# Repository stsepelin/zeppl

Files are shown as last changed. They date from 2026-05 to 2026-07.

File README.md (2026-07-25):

# Zeppl





> **Zeppl** — DIY digital instrument cluster for a 2009 Harley-Davidson VRSCF
> Muscle: an 800×800 round IPS gauge that drops into the stock dash, reads the
> bike's J1850 bus, and bridges phone notifications + media over BLE.

Built on the Waveshare ESP32-P4-WIFI6-Touch-LCD-3.4C (ESP32-P4 dual-core
RISC-V @ 360 MHz + ESP32-C6 BLE/WiFi coprocessor, 32 MB PSRAM, 16 MB flash).
LVGL 9 over MIPI-DSI on ESP-IDF v6, paired with the Zeppl Android companion
app for phone integration.

## What's in the repo

| Path | What it is |
|---|---|
| [`firmware/`](firmware/) | ESP-IDF cluster firmware — gauge UI, sim engine, BLE peripheral, host tests, desktop simulator |
| [`companion/`](companion/) | **Zeppl** Android BLE-central app — notifications + media bridge, live telemetry, and speed/fuel calibration for the cluster |
| [`docs/`](docs/) | Cross-system docs — project brief, roadmap, hardware/bus reference, phase plans, UI screens |
| [`firmware/docs/`](firmware/docs/) | Firmware-internal docs — architecture, reference notes, ride logs, plans |

Start with [`docs/PROJECT-BRIEF.md`](docs/PROJECT-BRIEF.md) for the whole-system view,
or jump straight to a component:

- [`firmware/CLAUDE.md`](firmware/CLAUDE.md) — firmware working notes
- [`companion/README.md`](companion/README.md) — Android app working notes

## Quick start

```sh
make help              # list every target
make build-fw          # build the firmware
make flash-monitor     # flash + open serial monitor
make test-fw           # run host unit tests (no MCU required)
make sim               # desktop SDL2 + LVGL simulator
make build-app         # build the Android app
make test-app          # run companion unit tests
```

The Makefile delegates to `idf.py` / `gradlew` in the right subdirectory
and sources the ESP-IDF environment for you. Override
`IDF_EXPORT=/path/to/export.sh` or `PORT=/dev/cu.usbmodemXXXX` on the
command line if defaults don't match your setup.

## Status

**Phase 1 (firmware & gauge UI)** is complete — display, widgets, touch,
settings, the Android BLE companion, the simulator, and a 100% host-test
gate; a synthetic driving cycle drives the full widget set at 30 FPS on the
round display. **Phase 2 (J1850 bus + IM simulation)** is well along: the RX
sniffer, decode → vehicle_data producer, on-board ride log, and the full
companion telemetry / calibration / fuel stack are in and bench-validated,
with the **speed divisor locked at 188** (Ride 2, 2026-07-09 — gear-ratio
physics + radar, not GPS). **Stage 4 TX + IM replay is on-bike validated
(2026-07-24)** and the **DTC read** firmware is built. Remaining: the DTC
follow-ups and the stock-cluster-removal checks. See
[`docs/phases/phase2-j1850.md`](docs/phases/phase2-j1850.md).

See [`docs/ROADMAP.md`](docs/ROADMAP.md) for the full four-phase roadmap with
per-stage statuses.

## Hardware

- **Board**: Waveshare ESP32-P4-WIFI6-Touch-LCD-3.4C — [vendor page](https://www.waveshare.com/esp32-p4-wifi6-touch-lcd-3.4c.htm)
- **Bike**: 2009 Harley-Davidson VRSCF Muscle (VRSC family, J1850 VPW bus,
  12-pin instrument harness)
- **Companion**: Android 16+ device (minSdk 36); the companion app is
  side-loadable in dev builds

The firmware *should* compile on any ESP32-P4 board with a 16 MB flash
and PSRAM, but the BSP layer (display, touch, codec) is Waveshare-specific.

## Development

```sh
# First-time IDF setup (one-off)
git clone https://github.com/espressif/esp-idf.git -b v6.0.1 ~/esp/esp-idf
cd ~/esp/esp-idf && ./install.sh esp32p4

# In this repo, with IDF active:
. ~/esp/esp-idf/export.sh   # or have Makefile source it via IDF_EXPORT
make build-fw

# Host tests (no IDF needed beyond cmake + lcov)
brew install lcov            # macOS
make test-fw

# Android side: standard Gradle + Android Studio
make build-app
```

See each component's working notes for deeper conventions (cache
discipline on widget setters, theme palette, font choices, BLE GATT
layout, etc.).

## Contributing

This is primarily a personal project for one specific bike, but the
firmware patterns (LVGL setter caches, V-Rod palette, BLE-over-VHCI
on a P4+C6 module, the binutils 2.45 link-trap workaround) are
generic enough to be useful elsewhere. Issues + PRs welcome —
especially ports to other Harley models or display boards.

If you're filing a bug, please include:
- ESP-IDF version + toolchain bundle
- ESP32-P4 silicon revision (`esptool chip_id`)
- Board model
- The full boot log if it's a runtime issue, or `idf_size.py --archives`
  output for a build-size issue

## License

[Apache 2.0](LICENSE). Vendor BSP components under `firmware/components/`
and `firmware/managed_components/` retain their own licenses (Apache 2.0,
MIT, etc.); see the LICENSE file inside each.

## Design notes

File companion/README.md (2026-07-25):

# Zeppl (companion)

**Zeppl** (package `ee.zeppl.companion`) is the Android phone-side bridge for
the [Zeppl](../) cluster firmware.

Mirrors notifications and media state from the phone to the bike's
gauge over a BLE GATT link, and accepts commands back (accept / reject
calls, media transport). The firmware advertises as `Zeppl`
and this app is the central that pairs with it.

Whole-system context: [`../docs/PROJECT-BRIEF.md`](../docs/PROJECT-BRIEF.md) ·
[`../docs/ROADMAP.md`](../docs/ROADMAP.md). The companion work is Phase 1 (relay)
+ Phase 2 Stage 5 (telemetry / calibration) in that roadmap.

**Deep-dive docs** (in [`docs/`](docs/)): [`ARCHITECTURE`](docs/ARCHITECTURE.md)
(packages, link model, data flow) · [`PROTOCOL`](docs/PROTOCOL.md) (the BLE wire
format) · [`CALIBRATION`](docs/CALIBRATION.md) (speed-divisor + fuel math).

## Status

**Phase 1 relay + Phase 2 Stage 5 companion, done.** The Material 3
Expressive redesign (adaptive nav, per-cluster detail screens, Galaxy
Fold 6 foldable support) is in.

Relay (Phase 1): BLE central with scan + device picker, LE Secure Connections
bonding (numeric comparison), a foreground service
(`FOREGROUND_SERVICE_CONNECTED_DEVICE`) hosting the GATT link,
`NotificationListenerService` relay with a per-app allow-list,
`MediaSessionManager` watcher for now-playing metadata, and a
`CommandHandler` that dispatches cluster-issued commands (call
accept/reject/end, media prev/play/pause/next, notification dismiss)
into `TelecomManager` / `MediaController`.

Cluster integration (Phase 2 Stage 5): a 4 Hz **telemetry** stream
(`TelemetryCodec`), a **GPS speed-calibration** wizard (`SpeedCalibrator`
least-squares-fits GPS speed vs the cluster's raw ECM count → speed
divisor, written back over BLE), **config write-back** to cluster NVS,
and **fuel economy / range** (`FuelEconomy`: fill-up mL/tick calibration →
mpg / L/100km / range-to-empty). The wire-format encoder and the pure
calibration modules are unit-tested against the firmware's C fixtures.

Auto-reconnect: on link loss (`ReconnectPolicy` — supervision timeout,
i.e. cluster power cycle or out-of-range) the client re-arms a
background `connectGatt(autoConnect=true)` to the bonded address, so
the link heals on every ignition cycle without touching the phone.
Deliberate disconnects (either side's disconnect button) stay
disconnected.

## Why a custom companion app

The cluster's ESP32-C6 radio is BLE-only — no Bluetooth Classic, so
HFP / AVRCP / MAP are off the table. iOS exposes notifications and
media over ANCS + AMS natively; Android doesn't have an equivalent
profile, so we forward over our own GATT characteristic. Keeping the
wire format custom (rather than re-using a spec like ANCS) lets the
firmware speak the same protocol on both platforms.

## Requirements

- Android 16 (API 36) device or emulator
- Android Studio (AGP 9.2 + Kotlin 2.3)
- JDK 17 (the Robolectric test task self-selects JDK 21 via the toolchain)

## UI architecture

Material 3 **Expressive** (`MaterialExpressiveTheme` + the spring-based
`MotionScheme`), branded Zeppl dark theme by default (orange-on-near-black,
mirroring the cluster's own palette in `firmware/main/display/theme.h`;
Material You dynamic color is an opt-in toggle under Settings). The theme
lives in `ui/theme/` (`Color.kt` / `Type.kt` / `Theme.kt`).

Navigation is an adaptive `NavigationSuiteScaffold` (bottom bar on phones,
rail on larger screens) over a type-safe `@Serializable`-route NavHost
(`ui/Destinations.kt`, `ui/App.kt`), with a persistent connection-status
strip (`ui/ConnectionStatusBar.kt`) visible on every tab. Four top-level
destinations:

- **Ride** — live telemetry dashboard (`ui/RideScreen.kt`), reading
  `ble/TelemetryState`; offline empty-state until frames arrive.
- **Cluster** — device hub: link, bond management, setup/maintenance
  (`ui/ClusterScreen.kt`).
- **Settings** — notification/media relay + appearance + cluster config
  write-back (`ui/SettingsScreen.kt`).
- **History** — trips + economy trends (`ui/HistoryScreen.kt`, placeholder).

Version note: material3 is pinned to `1.5.0-alpha18` (newest Expressive
alpha still on the Compose 1.11 line — 1.5.0-alpha20+ / Compose 1.12 need
compileSdk 37; see `gradle/libs.versions.toml`).

## Build + run

```sh
# From the repo root via the top-level Makefile:
make build-app         # ./gradlew :app:assembleDebug
make test-app          # ./gradlew :app:test
make install-app       # ./gradlew :app:installDebug (to a connected device)

# Or directly:
cd companion
gradle wrapper         # one-time, generates gradlew jar
./gradlew :app:assembleDebug
```

## Wire format

`app/src/main/java/ee/zeppl/companion/ble/Protocol.kt` mirrors
[`firmware/main/connectivity/phone/phone_protocol.c`](../firmware/main/connectivity/phone/phone_protocol.c)
byte-for-byte. The firmware's host tests
(`firmware/test_apps/host/tests/test_phone_protocol.c`) are the
canonical fixtures; `ProtocolTest.kt` asserts the same shapes from the
encoder side. Touch one, touch both.

## Layout

```
companion/
├── app/                          Main module
│   ├── src/main/
│   │   ├── AndroidManifest.xml
│   │   ├── java/ee/zeppl/companion/
│   │   │   ├── MainActivity.kt
│   │   │   ├── ble/              GATT client, protocol encoder, state, telemetry
│   │   │   ├── media/            MediaSession watcher → wire format
│   │   │   ├── notif/            NotificationListener bridge
│   │   │   └── ui/               Compose app: theme/, nav shell, four tab screens
│   │   └── res/
│   └── src/test/                 JVM unit tests (Protocol, BleState, …)
├── build.gradle.kts
└── settings.gradle.kts
```

## Roadmap

- [x] BLE central: scan for `Zeppl`, bond, open the GATT
      service, hold the write characteristic, subscribe to the command
      notify characteristic.
- [x] Foreground service hosting the BLE link
      (`FOREGROUND_SERVICE_CONNECTED_DEVICE`).
- [x] `NotificationListenerService` → `Protocol.encodeNotif`.
- [x] `MediaSessionManager` listener → `Protocol.encodeMedia`.
- [x] Inbound command path → Telecom
      (`TelecomManager.acceptRingingCall`, `endCall`) and
      media key dispatch for prev/play/next.
- [x] Status / pairing UI (`ScanScreen`, device picker).
- [x] Auto-reconnect when the bonded cluster reappears after a power
      cycle (background `connectGatt(autoConnect=true)` armed on link
      loss — works under directed advertising, unlike a rescan).
- [x] Material 3 Expressive redesign: branded theme, adaptive
      navigation hub (Ride / Cluster / Settings / History), persistent
      connection status.
- [x] Live telemetry stream on the Ride dashboard (Brick 1).
- [x] GPS speed-calibration wizard (Brick 2). (Firmware divisor is locked at
      188 from Ride 2 physics + radar; the wizard is a GPS cross-check.)
- [x] Cluster config write-back with ack/read-back (Brick 3).
- [x] Fuel economy / range (Brick 4). Persistent trip history is a follow-up.
- [ ] **Diagnostics view** — surface the DTCs the cluster reads (firmware read
      path is built) + a clear-codes action. See the roadmap's Phase 2 Stage 5.

## License

Apache 2.0 — see [`../LICENSE`](../LICENSE) at the repo root.

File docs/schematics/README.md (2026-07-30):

# Schematics

Source of truth for the analog/wiring drawings. Each `.py` is a
[schemdraw](https://schemdraw.readthedocs.io/) script that renders the
`.svg` next to it; the SVGs are committed so the docs render on GitHub
without any toolchain. (Exceptions: the matplotlib drawings —
`j1850_signal_board.py`, `bike_power_perfboard.py`,
`im_connector_face.py` — are matplotlib, not schemdraw; see Regenerate.)

> **TX polarity RESOLVED (2026-07-04): standard VPW → high-side TX.**
> The bus idles LOW / dominant HIGH (bare-bus DMM + invert-off raw dump +
> clean filter-off decode all agree — see `SESSION-2026-07-04.md`), so
> `j1850_tx.svg` (high-side PNP) is the canonical TX. The low-side
> `j1850_transceiver` drawing was the inverted-bus hypothesis; it was
> wrong and has been deleted (its "wrong turn" is recorded in prose in
> the roadmap + session notes, not kept as a buildable drawing). TX
> build itself is still Stage 4, gated on the 2N2907A + bench self-sniff.

| Drawing | Built in | What it is |
|---|---|---|
| `j1850_rx.py/.svg` | Phase 2 Stage 1–2 | J1850 RX front end alone: 7.5V zener clamp + 10k/4.7k divider → sniffer GPIO. Correct and unchanged. Build this first — it can't disturb the bus. (The temporary GPIO 22 ADC amplitude probe is a second wire off node B — firmware `CONFIG_VROD_J1850_ADC_GPIO`; not drawn.) **Phase 3:** the permanent harness needs a **comparator / Schmitt** stage here for noise immunity — not the P4 glitch filter (it desyncs decode; see the roadmap Phase 3 note + `../../firmware/docs/reference/j1850-toggling-isr-candidate.md`). This bare-divider drawing is the bench build. |
| `j1850_tx.py/.svg` | Phase 2 Stage 4 — **canonical TX (high-side)** | High-side PNP source: dominant = drive bus HIGH. Correct for standard VPW (idle LOW / dominant HIGH), now confirmed on the bike. 2N2907A needed. |
| `j1850_signal_board.py/.svg` | Phase 2 + 6 — full bike signal board | Physical pad-per-hole layout of the whole signal board: the J1850 transceiver **plus the 6 discrete 12V dividers** (`discrete_divider`, ×6: turn L/R, beam, neutral, oil, ignition). Bike build (no Rpd). **v4 (18×24 perfboard): single GND rail down the right edge, one P4 comb (RX·GP20 / TX / GND + the 6 divider outputs), a PWR/BUS 3-pin input terminal, 2×3p signal-input terminals, and a +12V/GND transit terminal onward to the power board; each 3V3 clamp joins its comb pin through a jumper so the pin hole stays free.** **12V topology (split point S2): the row-1 rail IS the split — the harness feeds (1,3), Q2's emitter taps off the rail, and (18,2) transits onward to the power board, so this rail carries the FULL power-board current (~0.5 A cont / ~1.0 A peak). F1 is inline in the harness; this board is fused but NOT reverse-protected (D2 is downstream, on the power board).** ⚠ **That describes the INTENDED state: F1 is currently NOT installed and v4 is drawing from pin 6 unfused — see the deviation note in [`../../firmware/docs/reference/bike-power-injection.md`](../../firmware/docs/reference/bike-power-injection.md). Blocking before the power board is connected.** As-built status: `j1850_signal_board.md`. The power chain lives on a **separate** board (switcher noise / current). Build doc + netlist + ring-out: `j1850_signal_board.md`. Electrical source of truth stays `j1850_rx`/`j1850_tx`/`discrete_divider`. **matplotlib, not schemdraw.** |
| `discrete_divider.py/.svg` | Phase 3 | 12V discrete-signal divider (10k/2.7k + optional 3.3V zener), ×6 for turns/beam/neutral/oil/ignition. Sized for 14.4V charging voltage. |
| `bike-power-chain.py/.svg` | Phase 3 (power) | Protected 12V→5V bike-power chain: fuse + reverse-polarity + load-dump TVS (TVS1 P6KE16A) → mini560 → output reverse-block (D4 XL74610 ideal-diode @ 5.0V) → board header 5V, with USB-C data coexisting via the board's own AO3401. Full parts list + bench test in `../../firmware/docs/reference/bike-power-injection.md`; BOM in `bike-power-chain.bom.md`. |
| `bike_power_perfboard.py/.svg` | Phase 3 (power) — perfboard build | Physical pad-per-hole layout of the `bike-power-chain` circuit. **Starts at D2** — F1 is a harness part, not on this board: D2 SB560 → TVS1 P6KE16A → mini560 12V→5V → D4 XL74610 ideal-diode → P4 header 5V. **Its 12V input is fed BY the signal board's transit terminal (split point S2); this board sources nothing back to it.** Separate board from the signal board. Electrical source of truth stays `bike-power-chain.py`. **matplotlib, not schemdraw.** |
| `im_connector_face.py/.svg` | Phase 3 (harness) | Physical face map of the V-Rod Instrument Module 12-pin connector (**Deutsch DTM06-12S** socket, from the molded housing marking) for building quick-connect mating connectors. 2-row / 6-wide; **bottom row numbering is inverted** — 12,11,10,9,8,7 left→right (pin 12 under pin 1, pin 7 under pin 6), **verified on the bike (2026-07)**, not assumed. Wire-entry side (the mating face mirrors L↔R). Each cavity shows wire colour + signal; the ring colour encodes the destination (signal-board divider / J1850 BUS / power board / GND / Phase 3 / unused). Pin→colour→signal from the connector table in `../reference/J1850-BUS.md` / `../PROJECT-BRIEF.md`. **matplotlib, not schemdraw.** |
| `gps_module.py/.svg` | Map (optional) | NEO-6M / GY-NEO6MV2 map-position module: 5V/GND + module TX → GPIO 21 (3.3V TTL, no level shift), RX-only. Wiring + bring-up in `../../firmware/docs/reference/gps-module.md`. |

## Regenerate

```sh
python3 -m venv .venv && .venv/bin/pip install schemdraw matplotlib
for f in *.py; do .venv/bin/python "$f"; done
```

Edit the `.py`, re-run, commit both files. Don't hand-edit the SVGs.

The matplotlib drawings — `j1850_signal_board.py`,
`bike_power_perfboard.py`, `im_connector_face.py` — are **matplotlib, not
schemdraw** (hence the `matplotlib` install above). Each writes both a `.svg`
and a `.png`; only the `.py` + `.svg` are committed, the `.png` is gitignored
(`docs/schematics/*.png`).

## Conventions

- Component designators are stable across drawings, in **two families** that
  never share a name. The v4 signal board carries parts from both, so read the
  family, not just the letter:
  - **J1850 front end** — `R1` 10k / `R2` 4.7k divider, `D1` 7.5 V BUS clamp,
    plus `R3` 1k, `R4`/`R6` 10k, `R5` 100 Ω, `Rg` 10k, `Q1` IRLZ44N, `Q2`
    2N2907A. Match the prose in `../reference/J1850-BUS.md`.
  - **12V discrete divider** (×6) — `Ra` 10k / `Rb` 2.7k, `Dz` 3.3 V clamp.

  The distinction is load-bearing: a 3.3 V `Dz` fitted in the `D1` position would
  clamp the **bike's J1850 bus** at 3.3 V. `j1850_signal_board.md`'s placement
  table lists both families with their holes.
- Values that came out of analysis carry their reasoning as a caption
  inside the drawing (e.g. the 14.4V charging-voltage math), so a
  printout taken to the bench is self-contained.

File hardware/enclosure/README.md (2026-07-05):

# Enclosure — Waveshare ESP32-P4-WIFI6-Touch-LCD-3.4C

Parametric round enclosure in `enclosure.scad`. **Rear-bolt board fixation** for a
motorcycle (vibration): the PCB is mounted the way it's designed to be — bolted at
its 4 mount holes (74.5 mm square) to internal standoffs, from the **rear**.

**Key dimensions:** Ø115 mm face (cover-glass OD, `glass_od`) · 74.5 mm board mount
square (`mount_square`) · ~50 mm electronics cavity depth (`internal_depth`). Build
tiers (`simple` / `compromise` / `robust`) tune wall / floor / standoff / gasket —
see the tier table below. (STL outputs are regenerated from `enclosure.scad`, not
committed — see the render commands under "Modes".)

> **This is a TEMP / bench-test build.** Wiring exits through ONE cable hole at the
> bottom of the wall (`cable_hole_dia` at `cable_exit_angle` = 270°); the per-connector
> cutouts (USB-C / microSD / 40-pin / buttons) are dropped and kept as commented
> params for the final enclosure. microSD access on this build = remove the rear cover.
> **Every screw boss is gusseted** (bezel ears, case perimeter bosses, board
> standoffs) via a shared `boss_gusset` module — no freestanding stalks anywhere.

```
[ bezel ring ]   frames + protects the glass edge (light duty)
[ glass + PCB ]  one bonded block, 7.6 mm (glass 6 + pcb 1.6), touching; in from front
[ standoffs ]    4 chunky wall-gusseted posts behind the PCB at the 74.5 square,
                 M3 heat-set inserts — the board's PRIMARY load path
[ deep cavity ]  ~50 mm for breadboard + mini560 + wiring
[ rear cover ]   REMOVABLE — reach the 4 board bolts + wiring, then close
```

## Why the rear cover is removable (not a closed cylinder)

The 4 board bolts are driven from the **rear**, so the back must be **open during
assembly** to reach them. A one-piece closed cylinder would make the board bolts
(and wiring, and the microSD) unreachable. So the rear cover is a separate,
removable panel — screwed on last.

## Why this works now (it didn't before)

The 4 M3 holes sit under the glass *from the front*, but the removable rear cover
means they're **reachable from behind**. The board seats rear-face on 4 chunky
standoffs at the 74.5 square; 4 rear M3 bolts thread up into heat-set inserts in
the standoffs, engaging the board's own mount holes. The block is trapped forward
by the front lip + bezel and rearward by the standoffs, so the board is held
captive at its 4 holes — its intended mount, stronger and more direct than the
edge-compression it replaces.

> Note on the load path: because the glass fully backs the PCB *front*, a bolt
> head can't sit on the glass side, so the rear bolts **locate + secure** the board
> at its holes while the front lip/bezel trap the block forward (the board can't
> lift off the posts). This is a direct 4-point board mount, not an edge clamp.

## Standoffs (the board's load path)

Chunky and **wall-gusseted** — no thin tall stalks. Diameter is per-tier (`simple`
9, `compromise` 10, `robust` 11 mm). Each post is tied to the wall by a **tapered
fan gusset** (`gusset_span` ±15°, `gusset_h` 10 mm): a solid web fanning from the
post base out to a ~30° arc of the wall and tapering up to the post, so the post
can't crack off at the base under vibration. M3 heat-set insert (`insert_hole_dia
= 4.0`, `insert_depth = 6.0`) opens toward the PCB; the rear bolt reaches it up a
clearance bore. A **`gasket_under_pcb`** pad (0.8 mm default) sits between the PCB
rear and the standoff tops — the whole board is damped, not just the glass rim.
Print `rear_case` open-end up so the standoff/gusset layers resist the bolt load
across, not along, the layer lines.

Verified in the render echo: standoff centers at (±37.25, ±37.25) → **74.5 mm
center-to-center in X and Y**, and the bolt path PCB-hole (z 6–7.6) → under-PCB
gasket (7.6–8.4) → insert (8.4–14.4) → rear clearance to the open back.

## Modes / render

```sh
openscad -o rear_case.stl        -D 'part="rear_case"'        enclosure.scad
openscad -o bezel.stl            -D 'part="bezel"'            enclosure.scad
openscad -o rear_cover.stl       -D 'part="rear_cover"'       enclosure.scad
openscad -o calibration_base.stl -D 'part="calibration_base"' enclosure.scad
# tier / fastener overrides:
openscad -o rear_case.stl -D 'part="rear_case"' -D 'tier="robust"' enclosure.scad
```
All four parts render manifold (`Simple: yes`) at every tier / fastener setting.

## Build tiers (`-D 'tier="..."'`)

| tier | fastener | wall | floor | perimeter screws | standoff Ø | gasket_gap |
|---|---|---|---|---|---|---|
| `simple` | captured nuts | 3.0 | 4.0 | 4 | 9 | 1.0 |
| `compromise` (default) | heat-set | 3.0 | 3.5 | 6 | 10 | 0.6 |
| `robust` | heat-set | 4.0 | 4.0 | 6 | 11 | 1.0 |

Every screw boss (bezel ears, case perimeter bosses, board standoffs) is reinforced
by the shared `boss_gusset` module — a fan web to its wall/ring/floor, sized by
`gusset_span` / `gusset_h`. `screw_offset` (0°) keeps a clean gap at the bottom
(270°) for the cable hole with 6 screws.

`fastener` (for the perimeter bezel/cover screws) is independently overridable:
`-D 'fastener="heatset"'` / `"captured_nut"`. The **board** standoffs always use
M3 heat-set inserts (metal — the board is the load path).

## Print order

1. **`calibration_base`** — shallow front section with the block-seat ledge, the
   bezel screw ears, **and the 4 board standoffs**. Verify the block seats, the
   bezel screws line up, and — most important — the **board bolts onto the 74.5
   standoffs from the rear**. Cheap.
2. **`rear_case` + `bezel` + `rear_cover`** once the fit checks out.

## Assembly order

1. **Heat-set the inserts** into the 4 board standoffs (and the perimeter bezel /
   rear-cover bosses). Metal only — printed threads strip under vibration.
2. **Glass+PCB block in from the FRONT** — glass to the front lip; the PCB rear
   lands on the 4 standoff tops. Put the `gasket_under_pcb` foam/silicone pad (with
   4 clearance holes for the bolts) between the PCB rear and the standoff tops, and
   a gasket under the glass rim — the whole board is damped, not just the glass.
3. **4 rear board bolts** — reaching through the **open back**, drive short M3 bolts
   into the standoff inserts, engaging the board's 4 mount holes. **Thread-locker**
   (medium, e.g. Loctite 243) on every one.
4. **Bezel on the front** — light-duty frame/edge protection over the glass rim,
   its perimeter screws into the rear-case ears.
5. **Wiring** in the cavity (breadboard + mini560) exits the **single bottom cable
   hole**; then **rear cover** on last (screws into the rear bosses; thread-locker too).

## Material (print settings)

- **PETG** to start (tough). **ASA** best for a bike — UV / heat / sun resistant.
  **Not PLA** — heat-warps in a sun-parked cockpit.
- **Layer orientation:** print `rear_case` open-end up so the standoffs + gussets
  aren't a cleavage plane under the bolt load; 4+ perimeter walls. Print `bezel` and
  `rear_cover` flat. Thread-locker on all metal fasteners.

## Params to tune after test-fit

- **`standoff_len` / `standoff_od`** — post depth and chunk.
- **`gusset_span` / `gusset_h`** — fan-gusset arc and taper height (post-to-wall tie).
- **`gasket_under_pcb`** — foam/silicone pad between the PCB rear and standoff tops.
- **`gasket_gap`** — damping pad under the glass rim.
- **`mount_square` (74.5)** — the board bolt circle; re-measure if the bolts miss.
- **`fastener`** — perimeter screw style (`heatset` / `captured_nut`).
- **`glass_fit` / `block_fit`** — bore clearance if the block is tight/loose.

## Cable exit — single bottom hole (TEMP build)

All wiring exits one grommet hole at the **bottom of the wall** (`cable_hole_dia`
12 mm at `cable_exit_angle` 270°, `cable_exit_z` 35). Verified clear of the
standoffs (45/135/225/315°, z 8.4–22.4) and the screw gussets (270° sits in the
255–285° gap between the 240°/300° screws) — echoed at render time. **microSD is
accessed by removing the rear cover** on this temp build; a dedicated SD slot (and
the per-connector cutouts, kept commented in-file) comes on the final enclosure.
Move the hole with `cable_exit_angle` / `cable_exit_z`, or widen `cable_hole_dia`,
if your bundle needs it.

## Out of scope — handlebar mount

Metal load path, separate task: aluminium straps to the triple-tree riser bolts
(M10×1.5, ~89 mm). A commented `mount_strap_*` location is left in `enclosure.scad`.

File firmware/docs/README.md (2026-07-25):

# Firmware docs

Working notes for the ESP-IDF cluster firmware. Cross-system docs (project
brief, roadmap, hardware/bus reference) live at the repo root in
[`../../docs/`](../../docs/).

## Core (read these first)

- [`ARCHITECTURE.md`](ARCHITECTURE.md) — threading, render pipeline, boot
  sequence, decision history.
- [`DISPLAY-PERF-AND-MEMORY.md`](DISPLAY-PERF-AND-MEMORY.md) — **read before
  touching anything that draws.** Render/RAM constraints, bake-don't-transform
  rules, the debug playbook.
- [`PINS.md`](PINS.md) — header pin map / GPIO assignments.
- [`ble-bringup-bisect.md`](ble-bringup-bisect.md) — the binutils 2.45 / IDF
  P4-rev link-trap resolution.

## reference/ — design + bring-up notes

- [`reference/bike-power-injection.md`](reference/bike-power-injection.md) — protected 12V→5V power chain.
- [`reference/gps-module.md`](reference/gps-module.md) — optional NEO-6M map-position module.
- [`reference/dtc-read-probe.md`](reference/dtc-read-probe.md) — HD J1850 DTC read protocol + probe.
- [`reference/j1850-toggling-isr-candidate.md`](reference/j1850-toggling-isr-candidate.md) — future RX ISR design note.
- [`reference/j1850-undecoded-frames.md`](reference/j1850-undecoded-frames.md) — catalogue of still-undecoded bus frames.
- [`reference/live-gauge-bench-test.md`](reference/live-gauge-bench-test.md) — stationary bus→gauge validation.
- [`reference/signal-mapping-capture.md`](reference/signal-mapping-capture.md) — one-input-at-a-time signal capture plan.

## rides/ — on-bike sessions + bring-up logs

- [`rides/next-onbike-plan.md`](rides/next-onbike-plan.md) — **step-by-step plan for the next bike visit** (all open tests, in order).
- [`rides/ride-1-findings.md`](rides/ride-1-findings.md) — J1850 decode calibration.
- [`rides/ride-2-findings.md`](rides/ride-2-findings.md) — speed-divisor lock (188) + live-stack review.
- [`rides/ride-2-calibration-plan.md`](rides/ride-2-calibration-plan.md) — the Ride-2 plan (completed).
- [`rides/ride-3-plan.md`](rides/ride-3-plan.md) — map on-bike verification (pending).
- [`rides/onbike-session-plan.md`](rides/onbike-session-plan.md) · [`rides/stage4-onbike-step3.md`](rides/stage4-onbike-step3.md) — Stage-4 on-bike session plans.
- [`rides/stage4-tx-bench-log.md`](rides/stage4-tx-bench-log.md) — the Stage-4 TX bring-up + on-bike validation log.
- `captures/` — raw serial capture logs the ride docs reference.

## plans/

- [`plans/phase1-display-plan.md`](plans/phase1-display-plan.md) — the (complete) gauge-UI phase.
- [`plans/map-worldwide-plan.md`](plans/map-worldwide-plan.md) — GPS-paged per-cell map tiles.

## Other

- `waveshare-reference/` — vendor examples kept for reference (not ours).

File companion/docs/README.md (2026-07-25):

# Companion docs

Deep-dive docs for the Zeppl Android companion app. Start with the app overview
+ status + roadmap in [`../README.md`](../README.md); these are the reference
details behind it.

- [`ARCHITECTURE.md`](ARCHITECTURE.md) — package/class map (ble / cal / media /
  notif / ride / ui), the foreground-service link model, data flow, threading,
  and testing.
- [`PROTOCOL.md`](PROTOCOL.md) — the BLE GATT wire format: Nordic-UART
  characteristics, the TLV framing, every phone→cluster event type, the `0x40`
  telemetry frame, commands, and the icon codec. Mirrors the firmware's
  `phone_protocol.c` / `telemetry_codec.c` byte-for-byte.
- [`CALIBRATION.md`](CALIBRATION.md) — the pure `cal/` math: the least-squares
  speed-divisor solve and the fuel-economy / range calculations.

Whole-system context: [`../../docs/PROJECT-BRIEF.md`](../../docs/PROJECT-BRIEF.md)
· [`../../docs/ROADMAP.md`](../../docs/ROADMAP.md). The companion is **Phase 1**
(notification/media relay) + **Phase 2 Stage 5** (telemetry / calibration) in
that roadmap.

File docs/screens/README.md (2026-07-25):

# Screen layouts

Real renders of the cluster UI, captured headlessly from the desktop simulator
(`firmware/simulator/`) — the same widget code that runs on the P4, not mockups.
The physical panel is the inscribed circle of the 800×800 square (the case hides
the black corners). Images are downscaled to 480 px and palette-quantized for the
repo (see "Regenerating" below).

## Ride / gauge screen

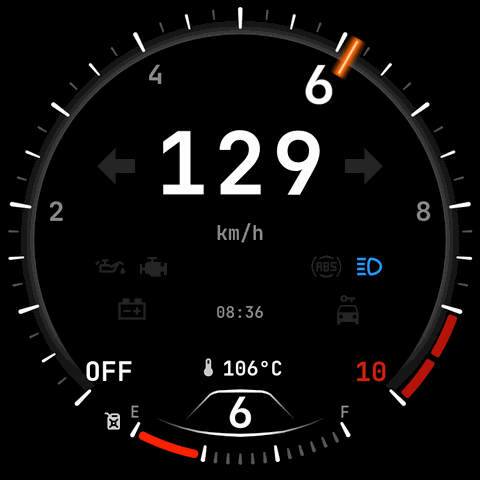
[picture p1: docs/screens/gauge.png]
Ride gauge screen — 129 km/h, gear 6, high beam


The primary screen (BMW-EfficientDynamics styling). Layout:

- **Tach** — 270° arc around the rim: capsule ticks, zoom + colour-coupled
  labels 2/4/6/8/10, a two-segment rounded **redline** (red, lower right), and a
  baked Gaussian **cursor** sprite tracking RPM. `OFF` (lower left) is the
  shift-light state.
- **Speed** — large centre digits (three slots, `km/h` / `mph` per settings),
  flanked by the **turn-signal** arrows.
- **Warning lamps** — two chevrons: oil, check-engine, ABS, battery,
  immobiliser (car-key), high/low beam (slot rotates).
- **Clock + odometer + dual trips** cycle in a shared slot; **temperature**
  readout; **gear** indicator in the bottom selector (orange `N`).
- **Fuel** — arc across the bottom (E→F), red when low, jerrycan icon.

Idle / key-on state (engine off, immobiliser + battery lit, `N`):

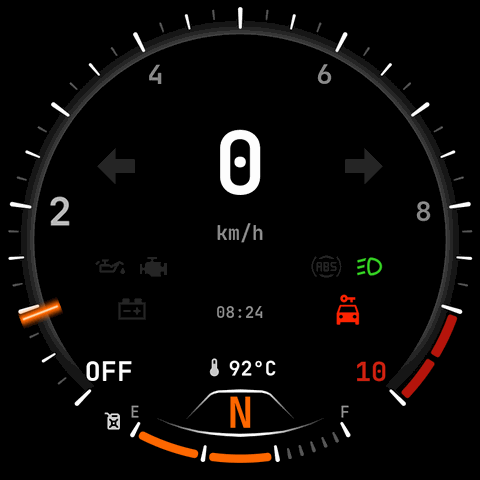
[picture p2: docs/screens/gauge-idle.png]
Ride gauge screen — idle, N, immobiliser lit


## Map screen

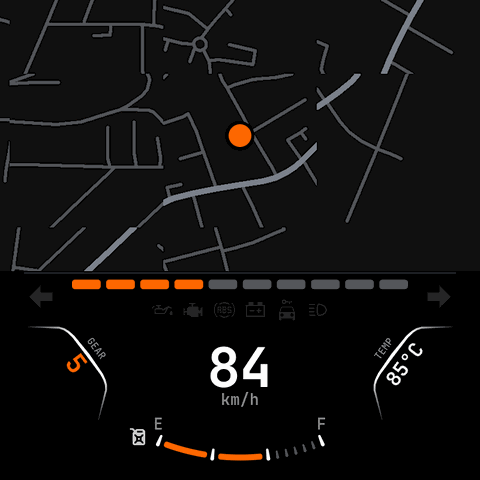
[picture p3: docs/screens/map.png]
Moving map + compact cluster


Reached by double-tapping off the gauge: SD-streamed vector tiles, heading-up
rotation, position dot (dual-source — onboard NEO-6M preferred, phone GPS
fallback), and a **compact cluster** strip below — RPM bar, warning lamps, a
slanted gear panel, centre speed, temperature, and the fuel arc.

## Settings

| | |
|---|---|
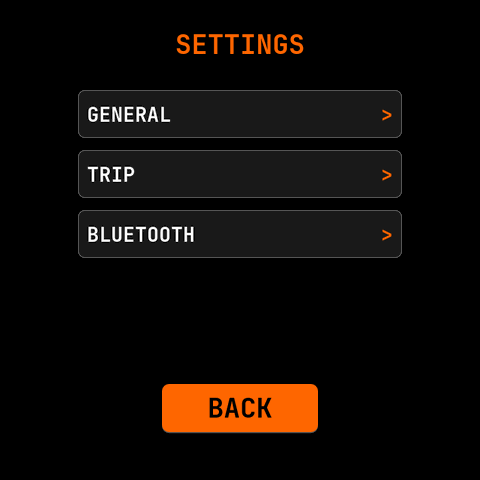
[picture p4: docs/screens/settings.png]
Settings menu
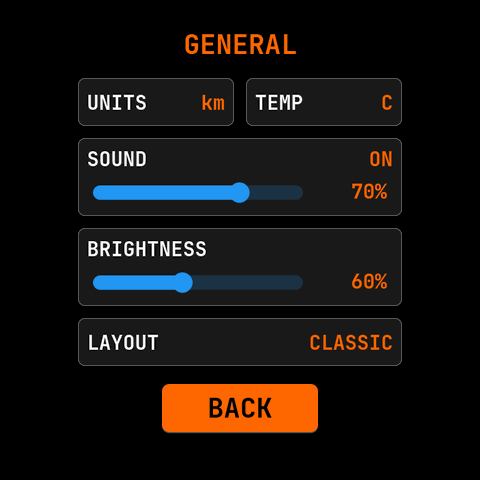
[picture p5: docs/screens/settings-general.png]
General settings
|  |  |
| **Menu** — General / Trip / Bluetooth. | **General** — units, temp unit, sound + brightness sliders, layout (classic / map). |
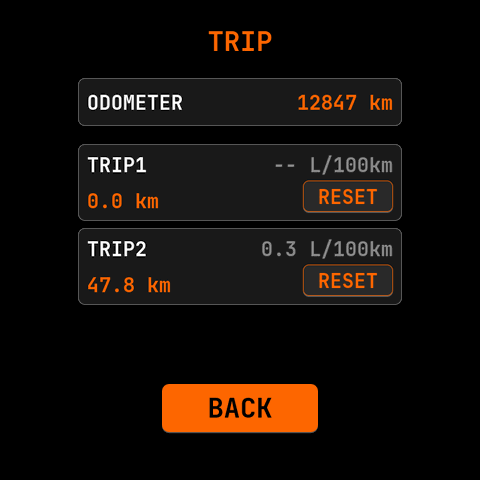
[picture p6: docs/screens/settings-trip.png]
Trip settings
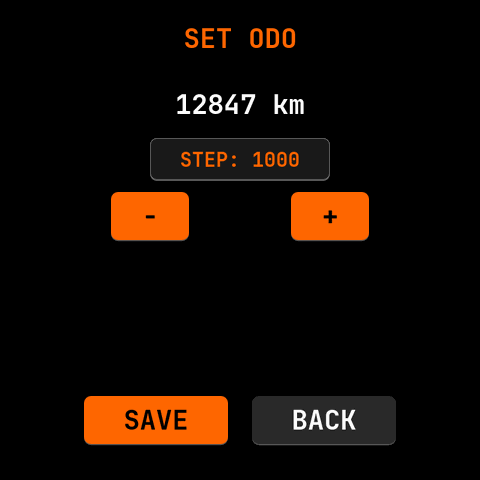
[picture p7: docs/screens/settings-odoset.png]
Set odometer
|  |  |
| **Trip** — odometer + dual trips, reset. | **Set ODO** — seed the odometer (step + / −, save). |
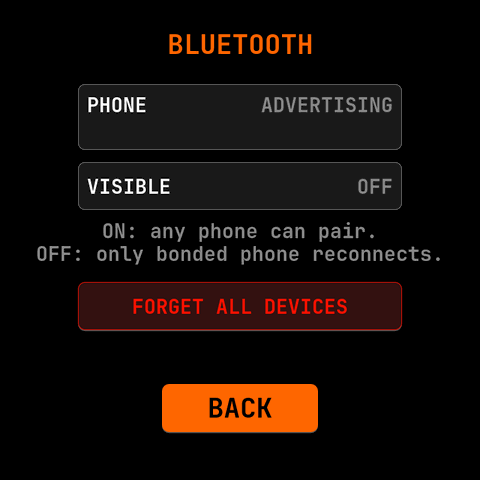
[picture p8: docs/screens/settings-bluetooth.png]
Bluetooth settings
|  | |
| **Bluetooth** — advertising state, visibility toggle, forget-all-devices. | |

## Regenerating

The simulator dumps the active screen to PNG headlessly via `VROD_SHOT` (needs
SDL2; `brew install sdl2`). `VROD_SCREEN=<name>` jumps to a settings screen;
`VROD_MAP_ZMTA` renders the map; `VROD_SHOT_FRAMES` picks the driving-cycle
frame; `VROD_NO_DEVBTN=1` hides the simulator-only dev buttons.

```sh
cd firmware/simulator
cmake -B build -S . && cmake --build build --parallel

# Gauge (moving ~frame 1400) and idle (frame 90):
VROD_SHOT=/tmp/gauge.png       VROD_SHOT_FRAMES=1400 VROD_NO_DEVBTN=1 ./build/vrod_sim
VROD_SHOT=/tmp/gauge-idle.png  VROD_SHOT_FRAMES=90   VROD_NO_DEVBTN=1 ./build/vrod_sim
# Map + compact cluster (demo corridor, centred on the demo track):
VROD_SHOT=/tmp/map.png VROD_SHOT_FRAMES=150 VROD_NO_DEVBTN=1 \
  VROD_MAP_ZMTA=../main/assets/corridor.zmta VROD_MAP_CENTER="59.4802377,24.8538196" ./build/vrod_sim
# Settings family:
for s in settings settings-general settings-trip settings-odoset settings-bluetooth; do
  VROD_SHOT=/tmp/$s.png VROD_SHOT_FRAMES=70 VROD_NO_DEVBTN=1 VROD_SCREEN=$s ./build/vrod_sim
done
```

Then downscale to 480 px + palette-quantize (small, crisp; `sips` re-encodes PNG
poorly, so use Pillow):

```sh
python3 -c 'from PIL import Image;import sys
for p in sys.argv[1:]:
    im=Image.open(p).convert("RGB").resize((480,480),Image.LANCZOS)
    im.quantize(256,method=Image.Quantize.FASTOCTREE).save(p,optimize=True)' /tmp/*.png
```

See `firmware/simulator/main.c` for the full env-var list (`VROD_SCREEN`,
`VROD_MAP_*`, `VROD_NO_BEZEL`, `VROD_PERF`, …). The bench (`VROD_J1850_SNIFFER`
build) and BLE-pairing screens aren't in this gallery — the first needs the
sniffer build + live stats, the second is a transient pairing prompt.

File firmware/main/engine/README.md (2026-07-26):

# engine/ — the bike node

**Role:** everything vehicle-facing. Reads the motorcycle (J1850 bus, discrete
signals, IM simulation), aggregates it into one canonical vehicle state, and
accepts vehicle commands. This is the always-on unit that could one day live as a
tiny board near the harness. See [ADR 0001](../../../docs/adr/0001-engine-display-split.md).

## Boundaries (the rules that keep this a clean node)

- **Produces** the canonical `vehicle_data` store; **accepts** vehicle commands
  (DTC read/clear, speed-divisor calibration) via [`contract/`](../contract/).
- **MUST NOT** include a radio (BLE / WiFi), **MUST NOT** include LVGL, and
  **MUST NOT** own GPS, media, settings, or any UI. If the engine needs something
  the phone knows, it arrives as a command through `contract/` — never as a
  direct call into a connectivity or display module.
- Anything the outside world reads (a display, the telemetry publisher, a future
  CAN broadcaster) reads it from `vehicle_data`, not from engine internals.

## Contents

### `j1850/` — the SAE J1850 VPW transceiver stack
- `j1850_vpw.c` — VPW symbol codec: pulse-width decode/encode + CRC-8/SAE-J1850. *(host-tested)*
- `j1850_edge.c` — toggling edge→level tracker for the RX front end. *(host-tested)*
- `j1850_parse.c` — message decoder: frame → RPM/temp/speed/turns/CEL/immobiliser. *(host-tested)*
- `j1850_driver.c` — producer glue: decoded frame → parse (+ `gear_calc`, + odo/fuel
  accumulation) → `vehicle_data_set`. The running aggregate. *(host-tested)*
- `j1850_sniffer.c` — GPIO-ISR edge capture. *(driver glue, out of gate)*
- `j1850_tx.c` — RMT-timed symbol TX + gptimer watchdog. *(driver glue)*
- `j1850_tx_logic.c` — pure TX logic: CRC frame build + watchdog dominant-length guard + on-air duration. *(host-tested)*
- `j1850_bench_feed.c` — bench-only synthetic SPEED/RPM (self-guarded).
- `frame_inject.c` — USB-injector wire codec: frame <-> `#F <hex>` line, CRC-validated. *(host-tested)*
- `usb_inject.c` — always-on task: reads `#F` lines off USB-Serial-JTAG -> `j1850_driver_feed`. *(transport glue, out of gate)*
- `j1850_adc_probe.c` — ADC bring-up repro.
- `dtc.c` — SAE J2012 DTC codec + HD J1850 read/clear request framing + response decode. *(host-tested)*
- `dtc_service.c` — phone-triggered DTC read/clear service task (keys the bus, answers a `0x41` frame).
- `dtc_probe.c` — standalone serial DTC probe.
- `ride_log.c` / `ride_log_format.c` — SD ride-log sink + line formatter *(format host-tested)*.

### `vehicle/` — canonical state + aggregation
- `vehicle_data.c` — the mutex-guarded latest-value store; **the contract surface**
  between producers here and every consumer. *(host-tested)*
- `gear_calc.c` — gear from the RPM:speed ratio (no gear sensor on the bike). *(host-tested)*
- `trip_meter.c` — rolling 16-bit bus counter → per-frame delta, wrap-safe. *(host-tested)*
- `odo_meter.c` — odometer + dual-trip totals. *(host-tested)*
- `odo_store.c` — NVS persistence for the odometer/trips.

### `simulator/` — the synthetic model (desktop only, not on the P4)
- `drive_model.c` — deterministic idle→accel→cruise→decel cycle: `drive_model_at(t)` → a `vehicle_data` snapshot. *(host-tested)*
- `sim_producer.c` — FreeRTOS task that steps `drive_model` and publishes it (gear via `gear_calc`). Built only into the desktop SDL2 simulator; the P4 always runs the real bus / USB injector. *(task body out of gate)*

### command handling
- `command_handler.c` — the engine-side command handler. Registered at boot; when
  connectivity dispatches a command it applies the config write-back (divisor →
  live decoder + NVS; layout → `ui_manager`) or keys a DTC read/clear. This is the
  seam that lets the engine stop knowing a phone exists.

## How it connects

```
J1850 bus / sim ──► j1850_driver / sim_producer ──► vehicle_data (canonical store)
                                                        ▲
contract/command ──► command_handler ───────────────────┘ (divisor, DTC)
```

`vehicle_data` is read by `display/` (rendering) and by
`connectivity/phone/telemetry_codec` (publishing state to the phone).

## Build gating

Most J1850 / TX / DTC sources are Kconfig-gated (`CONFIG_VROD_J1850*` in
`main/Kconfig.projbuild`). The synthetic `drive_model` producer is desktop-only
(`firmware/simulator/`); the P4 firmware always runs the live bus / USB injector.

## Testing

The pure modules above (`j1850_vpw`, `j1850_edge`, `j1850_parse`, `j1850_driver`,
`j1850_tx_logic`, `dtc`, `gear_calc`, `drive_model`, `trip_meter`,
`odo_meter`, `vehicle_data`) sit inside the **100% line+branch host-test gate**
(`firmware/test_apps/host/`). Capture/driver/task glue is deliberately out of it.

## See also

- [ADR 0001](../../../docs/adr/0001-engine-display-split.md) — the engine / connectivity / display split.
- [`docs/reference/CONTRACT.md`](../../../docs/reference/CONTRACT.md) — the canonical state model this node produces.
- [`docs/reference/J1850-BUS.md`](../../../docs/reference/J1850-BUS.md) — the bus map + VPW decode.

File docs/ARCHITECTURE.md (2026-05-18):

# V-Rod cluster — architecture

How the firmware fits together, and *why* each non-obvious choice is the
way it is. CLAUDE.md is the day-to-day cheat sheet; this file is the
context behind it.

## Threading model

Two cores on the ESP32-P4. Pinning is deliberate.

| Task | Core | Prio | Purpose |
|---|:----:|:----:|---|
| `sim_task` |  0 |  8 | Synthetic driving cycle → `vehicle_data` |
| `event_watcher_task`  |  0 |  5 | Polls indev + `vehicle_data` at 100 Hz for events |
| `audio_task` |  0 |  3 | Pulls click events from queue, writes to I2S codec |
| `ui_update_task` |  1 |  4 | 30 FPS widget setter sweep |
| LVGL render pthread |  1 |  4 | Composes dirty regions, flushes to DSI |

**Why event detection isn't in `ui_update_task`.** The UI task takes
`bsp_display_lock(-1)` before calling widget setters. LVGL's render
thread holds the same lock during compose. On a heavy frame (cursor +
shift-light + turn arrows all redrawing) the UI task waits on that lock,
which means turn-signal-edge detection and long-press timing stop being
sampled — inputs feel sluggish. `event_watcher_task` polls
`lv_indev_get_state()` and `vehicle_data` directly at 100 Hz on the
sim's core, where there's nothing to compete with, and only grabs the
LVGL lock briefly to call `ui_manager_show_settings` when a long-press
fires.

**Why audio is on core 0, not core 1.** Earlier the audio task lived on
core 1 with LVGL. `esp_codec_dev_write` blocks for ~30 ms while feeding
DMA; whenever LVGL was rendering a heavy frame at the same time, audio
queueing latency jumped and turn-signal clicks felt off-sync with the
arrows. Moving the audio task to core 0 (where the sim sleeps 45 of
every 50 ms) gives the codec writes a quiet neighbour and the clicks
stay locked to the visual.

## Shared state

- **`vehicle_data`** is the single source of truth between the producer
  (sim today, J1850 driver tomorrow) and the UI. Mutex-guarded. Sim
  writes the whole struct under the lock; consumers `vehicle_data_get`
  a snapshot.
- **`settings_store`** (NVS) loads at boot and exposes a stable pointer
  via `settings_store_current()`. Mutations happen inside settings-screen
  event callbacks, which run under `bsp_display_lock` — that serialises
  them against `ui_update_task`'s reads. No extra mutex needed.

## Render pipeline (the tach is the interesting case)

Everything that's static is pre-baked into ARGB8888 sprites in PSRAM
once at boot. Per-frame work is reduced to memcpy-with-alpha blits.

| Sprite | Size | What it is |
|---|---|---|
| Tail glow ring | 800×800 | Gaussian halo, orange in the normal sweep + red in  |
| | | the redline sweep |
| Cursor (normal) | 32×72 | Pill-shaped bar with perpendicular Gaussian glow |
| Cursor (redline) | 32×72 | Tighter sigma + red palette, swapped past redline |
| Tach track ring | 800×800 | 5-pixel gray rail at the bezel (was an `lv_arc`) |
| Tach scale ticks | 800×800 | 21 ticks at correct angles + redline coloring (was  |
| | | an `lv_scale` with section styles) |

Total PSRAM at runtime: ~14 MB / 31 MB (45%).

**Why bake the track + ticks.** The original `lv_arc` track and
`lv_scale` widget composed pixels per dirty area. Every cursor-movement
frame had to re-walk the arc path and re-draw 21 tick line segments in
the dirty rect. Replacing both with ARGB sprites makes the per-frame
cost a memory blit; cursor frames dropped noticeably on the device.

**Why labels are still `lv_label` widgets.** The labels need
transform-scale animation as the cursor sweeps past them. Per-label
scale is cached so labels whose scale didn't change skip their style
set (during a hard RPM transient that's 4 of 6 labels saved per frame).

## Upshift warning — the long story

The warning has been through several iterations. Recording them here so
nobody re-tries an approach we already discarded.

1. **5 Hz blinking full-screen ring** (`lv_obj` with circular border).
   Each visibility toggle invalidated the entire 800×800 framebuffer.
   At 10 invalidates/sec the triple-buffer copy stalled the audio +
   tach pipeline; visible stutter.
2. **Solid full-screen ring**. Only invalidated twice per WOT pull, but
   the ring's bounding rect IS the screen, so any other widget that
   overlapped it (cursor at the bezel, etc.) caused per-frame
   ring-pixel recompose.
3. **`lv_arc` with the same sweep as the tach**. Same cost story as the
   ring; visual was nicer but performance unchanged.
4. **Line-arc colour fade + glow-opacity fade**. Each LVGL refresh
   during the 150 ms fade invalidated the line arc's 800×800 bounding
   rect — 10× full-tach redraws crammed into the worst possible 150 ms,
   right when the cursor was moving fastest. Laggy.
5. **2 Hz blink of the line + glow swap**. Less dense than the fade
   but same per-toggle invalidation cost. Still laggy.
6. **Blink the gear digit**. Current implementation. `gear_indicator`
   is ~80×110 px — invalidating it costs ~70× less per blink than the
   tach area, and the timer fires 4×/sec instead of 60×/sec.

## Boot sequence

```
bsp_display_start_with_config   // panel + LVGL up
settings_store_init             // NVS open, defaults if first boot
bsp_display_brightness_set      // BEFORE backlight_on, avoids 100% flash
bsp_display_backlight_on
sound_init                      // codec, queue, click sample baked
sound_set_volume/_enabled       // apply persisted prefs
vehicle_data_init
sim_engine_start                // sim task spawns on core 0
boot_screen_show                // GIF starts; hands off to ride screen
                                // on LV_EVENT_READY (or 15 s safety)
```

## Out-of-band timing notes

- **Sim tick**: 20 Hz (50 ms). Writes a complete `vehicle_data` snapshot
  per tick.
- **UI tick**: 30 Hz (33 ms). Reads `vehicle_data`, runs the widget
  setter sweep under `bsp_display_lock`.
- **Event watcher tick**: 100 Hz (10 ms). Independent of LVGL load.
- **LVGL refresh**: `CONFIG_LV_DEF_REFR_PERIOD=15` (~66 Hz).
- **Boot GIF**: native 600×600, software blit. Native 800×800 was
  attempted but smoothness suffered when PPA was disabled (see
  CLAUDE.md gotchas).

## Tried and rejected

- **PPA** for the cooked-GIF blit. Caused horizontal banding on this
  BSP's DSI tear-avoid triple-buffer setup. Re-enable only with a
  known-good alignment story.
- **Lottie / ThorVG** for the boot animation. Vector rasterisation at
  800×800 isn't real-time on the P4. Don't retry unless either the
  resolution drops to ≤200×200 or ThorVG's rasteriser gets much faster.
- **LVGL `LV_EVENT_PRESSED` / `_LONG_PRESSED`** for touch on the ride
  screen. Hover events fired but press never reached the screen on this
  BSP. We bypass LVGL's gesture system and poll `lv_indev_get_state()`
  directly from `event_watcher_task`.
- **Line color animation / glow opacity animation** for the upshift
  warning. See the "long story" above.

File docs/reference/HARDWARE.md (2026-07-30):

# Hardware reference — BOM, transceiver, proxy box, power

Evergreen build reference: shopping list, system architecture, the J1850
transceiver + discrete dividers, the proxy box, power chain, phone-integration
design, display layout, warnings, dev environment, and external references.
Roadmap/status: [`../ROADMAP.md`](../ROADMAP.md). Bus pinout + decode table:
[`J1850-BUS.md`](J1850-BUS.md).

**Target:** 2009 Harley-Davidson VRSCF Muscle. **Budget:** ~€225-230. Full
custom gauge replacement — 3.4" round 800×800 IPS touch display, BLE phone
integration (iOS ANCS/AMS + Android companion), J1850 read + IM simulation,
proxy development harness, full reversibility to stock.

## Shopping list — confirmed AliExpress cart

### Core components

| Item | Link | Price | Notes |
|---|---|---|---|
| **Waveshare ESP32-P4 3.4" WIFI6 IPS Round Touch LCD** | [AliExpress](https://www.aliexpress.com/item/1005009157965757.html) | ~€86 | The brain. ESP32-P4 360MHz RISC-V dual-core + ESP32-C6 for WiFi6/BLE5. 800×800 round display, optically bonded toughened glass, 32MB PSRAM, 16MB flash (the listing says 32MB; the module on our board is 16MB — see `firmware/sdkconfig.defaults`), dual mics, microSD slot. |

### J1850 bus interface components

| Item | Link | Price | Notes |
|---|---|---|---|
| **5pcs IRLZ44N Logic-Level MOSFET (TO-220)** | [AliExpress](https://www.aliexpress.com/item/1005007434482338.html) | ~€0.77 | J1850 bus TX driver. Logic-level gate turns on at 3.3V. |
| **100pcs Transistor Assortment (incl. 2N2222A)** | [AliExpress](https://www.aliexpress.com/item/1005004188649994.html) | ~€3.77 | J1850 TX high-side switch (Q2). Needs a **PNP** — 2N2907A or S8550; the kit's 2N2222A is NPN and cannot serve as Q2. RX + 12V dividers are passive (zener + resistors), no transistor. |
| **50pcs Zener Diode 1W Assortment (incl. 7.5V)** | [AliExpress](https://www.aliexpress.com/item/1005006639039658.html) | ~€0.65 | Bus voltage clamp protection. Use 7.5V variant. |
| **600pcs Metal Film Resistor Kit (1% precision)** | [AliExpress](https://www.aliexpress.com/item/1005009347924494.html) | ~€20 | Voltage dividers (10kΩ, 4.7kΩ, 1kΩ, 100Ω). Useful long-term for any electronics project. |

### Wiring & connectors

| Item | Link | Price | Notes |
|---|---|---|---|
| **T-Tap Wire Connectors (Mixed)** | [AliExpress](https://www.aliexpress.com/item/1005006872234222.html) | ~€3.34 | For tapping the bike's 12-pin harness without cutting. Red (22-18 AWG) + blue (18-14 AWG) mixed. Need 9 red + 3 blue minimum. |
| **12-Pin Sealed Waterproof Connector** | [AliExpress](https://www.aliexpress.com/item/1005011688911042.html) | ~€23 | Pluggable interface between proxy box and DIY display. (BOM note: the DIY-side connector has since moved to a Deutsch DTM pair — see [`../../firmware/docs/PINS.md`](../../firmware/docs/PINS.md) / connector notes.) |
| **Mini560 Buck Converter 5V (10pcs)** | [AliExpress](https://www.aliexpress.com/item/1005007167054073.html) | ~€4.24 | 12V→5V for the ESP32-P4 power. |
| **Silicone Wire 18-22 AWG (Red/Black, 10m)** | [AliExpress](https://www.aliexpress.com/item/1005007007160447.html) | ~€3 | Heat-resistant, flexible — critical for motorcycle vibration. |
| **Tinned solid bus wire** (bare, single-core) | *needs sourcing — no part recorded* | — | The perfboard rails. **Not a convenience jumper: a current-carrying part.** Under split point S2 the signal board's row-1 rail carries the full power-board current (~0.5 A cont / ~1.0 A peak on the 12V side), so it must be one continuous run, not solder bridges. Diameter is **not recorded anywhere in this repo** — neither the T-tap nor the silicone-wire rows above are this wire. `MEASURE: diameter = ___ mm` (micrometer); see `../schematics/j1850_signal_board.md` for the drop table and the 1 A joint test. |

### Prototyping supplies

| Item | Link | Price |
|---|---|---|
| MB-102 Breadboard (830+400 pts + jumpers) | [AliExpress](https://www.aliexpress.com/item/1005011583761439.html) | ~€2.36 |
| Dupont Jumper Wire Kit (M-F, M-M, F-F) | [AliExpress](https://www.aliexpress.com/item/1005003219096948.html) | ~€8.66 |
| Prototype PCB Boards 5×7cm / 7×9cm (10 pcs) | [AliExpress](https://www.aliexpress.com/item/1005008742575241.html) | ~€5.41 |
| JST Connector Kit (SH/GH/ZH/PH/XH) | [AliExpress](https://www.aliexpress.com/item/1005005763085908.html) | ~€27 |
| 2.54mm Pin Headers (M/F, 20 strips) | [AliExpress](https://www.aliexpress.com/item/1005011781229719.html) | ~€2.61 |
| PCB Screw Terminals 2-pin + 3-pin (50 pcs) | [AliExpress](https://www.aliexpress.com/item/1005008625838032.html) | ~€7.37 |

**AliExpress total: ~€205.** Plus local (Tallinn) items — conformal coating
spray (~€10), heat-shrink kit (~€2), IP65 junction box (~€3), PG7 cable glands
(~€1.50), 32GB microSD (~€4), USB-C **data** cable (~€2). **Other total ~€22.**
**GRAND TOTAL ~€225-230.**

### Optional upgrades (buy later, not build-critical)

Solder-seal connectors (~€2), insulated bullet connectors (~€2), waterproof
22mm handlebar momentary button (~€3), BH1750 ambient-light sensor for
auto-brightness (~€1), ML1220 RTC battery (~€2), 3M VHB tape (~€3).

**CAN/DBC interop (Phase C — [ADR 0001](../adr/0001-engine-display-split.md)).**
For the engine to broadcast its state on the motorsport-standard bus so a
third-party dash/logger can read it (validated on the bench — **no bike, no second
board required**):

- **3.3V CAN transceiver** — SN65HVD230 breakout (~€2). The ESP32-P4's TWAI
  peripheral outputs logic-level TX/RX; this converts it to differential
  CANH/CANL. 3.3V part, so no level shifting.
- **USB-CAN dongle** — a CANable / candleLight running SocketCAN (~€15) or a
  PEAK PCAN-USB (~€30), plus a 120Ω terminator. Decodes the P4's broadcast on a
  laptop with `zeppl.dbc`.

Not needed until Phase C; the interop is designed but not yet implemented.

## System architecture

```
                    ┌─────────────────┐
                    │   Your Phone    │
                    │  (Android/iOS)  │
                    │  Waze / GMaps   │── Nav instructions ──┐
                    │  Spotify / etc  │── Track metadata ────┤
                    │  Phone calls    │── Caller ID ─────────┤
                    └────────┬────────┘                      │
                             │ BLE 5 (ANCS/AMS/companion)    │
                             ▼                               │
Bike 12-pin                                                  │
 harness ──► PROXY BOX ──┬──► Stock cluster (dev mode)       │
              [T-taps]    │    OR                            │
                          │    DIY display via 12-pin conn   │
                          └──► Signal taps:                  │
       ┌───────────────────────┘                             │
       ├─ J1850 Data ──► DIY transceiver ──► P4 GPIO         │
       │                  (IRLZ44N + 2N2907A + zener)        │
       ├─ +12V(sw) ─► F1 2A (harness) ─┬─► signal board rail   │
       │                                │    ─► Q2 emitter     │
       │                                │    (fused, NOT       │
       │                                │     reverse-prot.)   │
       │                                └─► power board: D2 ─►  │
       │                                    TVS1 ─► Mini560 ─►  │
       │                                    D4 ─► hdr 5V       │
       ├─ Ground ──► common GND                              │
       ├─ Turn L/R, High beam, Neutral, Oil ──► dividers ──► GPIO
       ├─ Fuel sender ──► P4 ADC pin                         │
       ├─ VSS ──► P4 GPIO (pulse counter)                    │
       └─ Ignition ──► voltage divider ──► P4 GPIO           │
                                                             │
microSD (32GB) ◄── SDIO ── P4 ◄─────────────────────────────┘
  ├── OSM vector map data        ESP32-C6 co-processor (BLE radio only —
  └── Ride data logs               no Bluetooth Classic): WiFi 6 + BLE 5,
                                   phone notifications + media metadata +
                                   transport commands via the companion's
                                   GATT link (Android) or ANCS/AMS (iOS)
```

(IM bus-simulation TX happens on the P4 itself through the transceiver on a
GPIO — the C6 is only the phone radio.) Firmware threading/render architecture:
[`../../firmware/docs/ARCHITECTURE.md`](../../firmware/docs/ARCHITECTURE.md).

## J1850 bidirectional transceiver circuit

> **TX topology RESOLVED (2026-07-04): standard VPW → high-side TX.** The bus
> idles LOW (~0.3 V) and pulses dominant HIGH (~7 V) — textbook active-high VPW.
> The earlier "idle HIGH / low-side / inverted" reading was an artifact of the
> 500 ns hardware glitch filter dropping the slow recessive falling edge.
> Consequences, all landed: **TX is a high-side PNP source (2N2907A)**;
> `CONFIG_VROD_J1850_RX_INVERT` removed; glitch filter defaults off
> (`CONFIG_VROD_J1850_GLITCH_NS=0`). Canonical drawing:
> [`../schematics/j1850_tx.svg`](../schematics/j1850_tx.svg). See the sweep in
> `firmware/docs/captures/SESSION-2026-07-04.md`.

J1850 VPW is an **active-high** single-wire bus: recessive = 0V, dominant = ~7V
*sourced by the transmitting node*. The TX stage is a switched high-side source,
connected to the bus only while transmitting a dominant symbol. (Do NOT build a
permanently-connected 12V pull with a low-side MOSFET shorting to ground — that
inverts polarity and jams the bus dominant whenever idle.)

Build and verify the **RX front end first** — with no FET populated it can't
disturb the bus: [`../schematics/j1850_rx.svg`](../schematics/j1850_rx.svg).

J1850 RX front end

- **Reading:** 10kΩ/4.7kΩ steps the bus ~7.5V → ~2.4V (safe for the P4's 3.3V
  GPIO); node B also feeds GPIO 22 (ADC amplitude probe).
- **Protection:** the 7.5V zener clamps transients on the bus wire.
- **Writing (TX):** high-side PNP source (drawing below). TX GPIO high → Q1
  pulls Q2's base low → Q2 sources ~7V onto the bus (dominant); low → Q2 off,
  bus floats to recessive 0V. A stuck-on TX jams the bus dominant, so the
  firmware watchdog must kill TX if a dominant persists past one VPW symbol.
- **Bench-validate first:** sniff-only (RX, no Q1/Q2) against the live bus; then
  the self-sniff loop (TX → RX node) sets R5 and CRC-checks our own frames.

**Canonical TX — high-side PNP source.** Dominant = ~7V *sourced* onto the bus
via a PNP high-side switch, level-shifted by a low-side NMOS off the 3.3V TX
GPIO:

J1850 TX stage

Node list (matches [`../schematics/j1850_tx.svg`](../schematics/j1850_tx.svg) —
the single source of truth):

- **Q2** (PNP, 2N2907A / S8550): emitter → **+12V**; collector → **R5 100Ω →
  J1850 bus**; base → **node A**.
- **Node A** (Q2 base) is pulled to +12V by **R6 10kΩ** (holds Q2 hard off at
  idle) and toward ground by **R4 10kΩ** in series with **Q1**.
- **Q1** (IRLZ44N, low-side level shift): gate ← **R3 1kΩ** ← P4 TX GPIO;
  source → GND.
- **TX GPIO high** → Q1 on → node A low → Q2 on → bus **sourced HIGH
  (dominant)**. **TX GPIO low** → Q1 off → R6 holds node A at +12V → Q2 off →
  bus released to **0V (recessive)**.
- **D1 7.5V zener** (in the RX drawing) clamps the driven bus level.

A stuck-high TX jams the bus dominant — the firmware TX watchdog is mandatory
before this stage touches the bike. (TX watchdog + on-bike validation:
[`../../firmware/docs/rides/stage4-tx-bench-log.md`](../../firmware/docs/rides/stage4-tx-bench-log.md).)

### 12V discrete signal voltage divider (×6 — turn L/R, high beam, neutral, oil, ignition)

12V discrete divider

```
12V signal ──── 10kΩ ────┬──── ESP32-P4 GPIO input
                         │
                       2.7kΩ   (optional: 3.3V zener in parallel,
                         │      cathode up — belt-and-braces clamp)
                        GND
```

Sized for the real electrical system, not the nameplate 12V: with the engine
running the "12V" rails sit at ~14.4V charging voltage. An earlier 10kΩ/4.7kΩ
divider gave **4.6V at 14.4V — above the P4's ~3.6V absolute maximum** (P4 GPIOs
are not 5V tolerant). 10kΩ/2.7kΩ gives 2.55V at 12V and 3.06V at 14.4V — a clean
logic high with margin. Per-line active-high/active-low polarity is a firmware
flag (see ROADMAP Phase 3) — the divider hardware is identical ×6.

## Proxy box design

```
┌─────────────────────────────────────────────────────────────┐
│                        PROXY BOX  (IP65 junction box)        │
│  Bike harness ──► T-taps on each wire ──► Internal PCB        │
│  ┌──────────────────────────────────────────────────┐        │
│  │  DIY J1850 Transceiver (IRLZ44N + 2N2907A + 7.5V  │        │
│  │  zener + resistors) ──► Pin 7 (J1850 data)         │        │
│  │  6× voltage dividers (10kΩ + 2.7kΩ) for 2,3,4,6,9,10│       │
│  │  (pin 6 also powers the board — lane G6 can only    │       │
│  │   read "on". OPEN: see phases/phase3-cluster.md)    │       │
│  │  Pins routed through screw terminals               │        │
│  └──────────────────────────────────────────────────┘        │
│  SCREW TERMINALS → P4 via dupont (dev) OR 12-pin conn (test)  │
│  12-PIN OUTPUT → Stock cluster (pass-through) OR DIY display  │
└─────────────────────────────────────────────────────────────┘
```

Lifecycle: **Dev** — Bike → Proxy → Stock cluster (rides normally) + P4 on desk
(sniff/code). **Testing** — Bike → Proxy → DIY display via the 12-pin. **Final**
— Bike → DIY display directly (proxy → toolbox drawer as backup).

## Phone integration (BLE)

- **iPhone — zero setup (built-in ANCS + AMS):** ANCS (notifications, caller ID,
  turn-by-turn) + AMS (track/artist + transport). No companion app; pair via iOS
  Settings. (iOS parsers deferred to Phase 4.)
- **Android — companion app (`companion/`, ✅ Phase 1):** Kotlin/Compose with
  `NotificationListenerService` + `MediaSessionManager`, a foreground BLE
  service, LE Secure Connections bonding, device-picker UI. Notifications + media
  → custom TLV over BLE GATT → P4; transport commands come back over the notify
  characteristic. AVRCP is **not** an option — the C6 is BLE-only (no Bluetooth
  Classic), which is exactly why the companion exists.
- **Display priority (high → low):** incoming-call overlay → nav instruction →
  music now-playing ticker → gauges (always visible).

## Display layout (800×800 round)

Real render from the simulator (the same widget code that runs on the P4):

Ride gauge screen

270° tach arc + redline around the rim, large centre speed with turn arrows, a
two-chevron warning-lamp cluster (oil / check-engine / ABS / battery /
immobiliser / beam), clock + odo + dual trips in a shared slot, temperature,
the gear selector, and a bottom fuel arc. Full gallery (idle state + the
moving-map screen) with regen commands: [`../screens/`](../screens/).

## Critical warnings

- **Immobilizer:** IM simulation should prevent U1255. If TSSM security still
  fails, use a Screamin' Eagle tuner or keep the stock IM wired in parallel.
- **Weatherproofing:** conformal-coat the PCB; the P4's bonded glass is already
  waterproof on the display side; seal cable entries with PG7 glands; silicone
  wire (vibration + heat); the stock housing gives good water resistance.
- **Legal (Estonia / EU):** a functioning speedometer is required for road use.
  Speed comes from the J1850 bus; run proxy + stock cluster during the testing
  period for redundancy.
- **Power:** keyed +12V (pin 6) for ignition on/off; 470µF cap on the 5V rail to
  absorb cranking spikes; the P4 boots in ~2 s — no graceful shutdown needed.
  Protected power chain: [`../../firmware/docs/reference/bike-power-injection.md`](../../firmware/docs/reference/bike-power-injection.md).

## Development environment

macOS (MacBook Pro); Zed + clangd via `compile_commands.json`; ESP-IDF v6.0.1
(native C/C++); target esp32p4; LVGL 9.x via the ESP-IDF component manager; BLE =
NimBLE host on the P4, controller on the ESP32-C6 via esp_hosted VHCI over SDIO;
programming over USB-C (no separate programmer). Live version in
[`../PROJECT-BRIEF.md`](../PROJECT-BRIEF.md).

## References

| Resource | URL |
|---|---|
| Waveshare P4 3.4C wiki | https://www.waveshare.com/wiki/ESP32-P4-WIFI6-Touch-LCD-3.4C |
| HarleyDroid (decode table + DTC protocol) | https://github.com/stelian42/HarleyDroid |
| DIGTACHO (PIC decoder ref) | https://github.com/momex/DIGTACHO |
| HD J1850 Visual Display | https://hackaday.io/project/162865 |
| J1850 VPW Arduino Library | https://github.com/matafonoff/J1850-VPW-Arduino-Transceiver-Library |
| LVGL documentation | https://docs.lvgl.io |
| ESP-IDF documentation | https://docs.espressif.com |
| ESP32 ANCS library | https://github.com/Smartphone-Companions/ESP32-ANCS-Notifications |
| ESP32 AMS library | https://github.com/marmotton/esp32-apple-media-service |
| OpenStreetMap | https://openstreetmap.org |

## Value comparison

| Solution | Cost | Capabilities |
|---|---|---|
| **This DIY build** | **~€230** | 800×800 display, BLE phone integration, IM simulation, custom UI, ride logging, expansion |
| Motogadget Motoscope Pro + V-Rod adapter | ~€800-1000 | Premium dash, no fuel/gear/ABS |
| Dakota Digital MCV-7000 | ~€500 | Digital gauge, no phone integration |
| Exotic Choppers airbox kit | ~€500-600 | Same Dakota Digital in airbox |
| Stock cluster repair | ~€600-800 | Just back to OEM |

*Stock speedometer dial 75mm | Display 86mm (3.4" round, 800×800) | fits inside
the 95mm stock cluster housing with minor bezel modification | the proxy harness
allows full reversion to stock anytime (dealer visits, resale).*

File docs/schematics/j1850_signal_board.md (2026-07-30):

# Signal board v4 — perfboard build (18x24 pad-per-hole, bike build)

Soldering map and check-out procedure for the **full bike signal board**: the
J1850 transceiver (RX bare divider + high-side TX) **plus the six 12V discrete
dividers**, all landing on one P4 comb. Top / component-side view. Coordinates
are **(column, row)**, col 1 at the left, row 1 at the top.

Layout image: `j1850_signal_board.svg` (regenerate: `python3
j1850_signal_board.py`, needs matplotlib — this drawing is NOT schemdraw).
Electrical source of truth stays `j1850_rx.py` / `j1850_tx.py` /
`discrete_divider.py`; this file only fixes the physical placement and the
check-out.

Board: 18 columns x 24 rows at 2.54 mm pitch. Both conventions are given,
labelled, so nobody reconciles them by guessing:

| Convention | Size |
|---|---|
| outline (N x pitch) | **~45.72 x 60.96 mm** |
| hole-field span ((N-1) x pitch, centre-to-centre) | **43.18 x 58.42 mm** |

Arithmetic from the 2.54 mm pitch, **not** a measured board outline.

Bare-wire rails:

| Rail | Run | Net |
|---|---|---|
| **+12V** | row 1, cols 1→18 | +12V |
| **GND (transceiver)** | row 11, cols 1→18 | GND |
| **GND (right edge)** | col 18, rows 11→24 | GND |

The two GND runs meet at (18,11) — they are one net. **Rpd is omitted** (the
bench bus pull-down is bench-only; on the bike the other nodes hold recessive
— see the bench-test caveat at the end).

The power chain lives on a **separate board**. This board only transits +12V/GND
through to it.

## As-built / in-service status

**This board is fitted to the bike and is the transceiver that carries every
logged on-bike result.** Owner-confirmed. Dates are given only where the log
records them.

| Gate | Status |
|---|---|
| DMM ring-out (pre-power) | **PASS** — date unrecorded |
| Diode-test, all seven zeners (D1 + six Dz) | **PASS** — date unrecorded. Independently corroborated by the 312 clean sends below: a reversed D1 would forward-conduct and jam the bus, and nothing would decode. |
| Bench self-sniff | **PASS 2026-07-19** — watchdog trigger + all four IM keep-alive frames CRC OK, tally 32/0 |
| On-bike, engine-off / engine-on / two cold-start cranks | **PASS 2026-07-24** — 312 consecutive clean sends, 0 watchdog faults, stock cluster attached, no DTCs |
| Ridden | **NOT YET** — the only remaining gate. See [`../../firmware/docs/rides/ride-3-plan.md`](../../firmware/docs/rides/ride-3-plan.md) |

Current intermediate state:

- **Transceiver half in service.** The six divider lanes are **populated but
  unconnected at both ends** — no input wire at the screw terminals, no comb pin
  wired to the P4. Nothing live is floating. Their GPIOs are still unassigned.
- **F1 is NOT installed.** The board is tapped to IM pin 6 with no 2 A inline
  fuse, backed only by the vehicle's own IM-circuit fuse — which is sized for the
  instrument module, not for our conductor. See the deviation note in
  [`../../firmware/docs/reference/bike-power-injection.md`](../../firmware/docs/reference/bike-power-injection.md).
- **The 1 A rail joint test has not been run.** It is not yet meaningful: with
  only the transceiver drawing, the row-1 rail carries ~1 mA. It becomes required
  **before the power board is connected**, because that is when the same rail
  first carries ~0.5 A continuous / ~1.0 A peak.

## 12V feed — DECIDED (split point S2)

This is settled, not proposed. The row-1 rail **is** the split:

```
IM pin 6 (Grey, switched +12V)
  -> F1 2A blade, inline IN THE HARNESS, within a few cm of the tap
  -> signal board PWR/BUS terminal (1,3)
  -> row-1 rail, cols 1..18          [Q2 emitter taps off at (4,3)]
  -> signal board transit terminal (18,2)
  -> power board IN
  -> D2 SB560 -> TVS1 P6KE16A -> mini560 (5.0 V) -> D4 XL74610 -> P4 header 5V
```

- **(1,3) "12V" on the left PWR/BUS terminal = INPUT** — from the harness tap.
- **(18,2) "12V" on the right terminal = OUTPUT** — onward to the power board.
- Both sit on the **same net**. **Never wire both to a source** — that parallels
  two feeds on one rail.
- **The power board sources nothing back.** There is no wire from it to here.
- **F1 is not a part of either board.** It is a harness part.

> **Accepted trade-off — this board is FUSED but NOT reverse-protected.**
> Reverse-polarity protection (D2) lives on the power board, which is
> *downstream* of this one, so a reversed feed reaches Q2's emitter rail
> unprotected. Key the harness connector and verify feed polarity with a DMM
> before every connection.

Drawings were changed to make this true: F1 removed from the power board
(`bike_power_perfboard.py:71-72`) and the split now drawn in the source-of-truth
schematic (`bike-power-chain.py:19`).

### Row-1 rail — verified construction

**Physically inspected 2026-07-29:** the row-1 rail is a **single continuous
tinned solid wire through all 18 holes**, not a chain of solder bridges between
adjacent pads. User-confirmed fact, not inferred from the drawing.

Because of S2 this rail carries the **full power-board current** — ~0.5 A
continuous, ~1.0 A peak on the 12V side
(`../../firmware/docs/reference/bike-power-injection.md:49-52`). **Design current
for the checks below: 1 A.** Rail span cols 1 -> 18 = 17 pitches = **43.18 mm**
(arithmetic from the 2.54 mm pitch, not measured).

The conductor is **not** the risk. Wire diameter is **not recorded anywhere in
this repo** — the only wire specs are `../reference/HARDWARE.md:35` (T-taps,
22-18 / 18-14 AWG) and `:38` (18-22 AWG stranded silicone), and neither is this
wire.

    MEASURE: rail wire diameter = ___ mm  (micrometer)

CALCULATED drop over 43.18 mm at 1 A (copper, rho = 1.68e-8 ohm-m):

| Assumed diameter | Resistance | Drop at 1 A |
|---|---|---|
| 0.4 mm | 5.8 mohm | 5.8 mV |
| 0.6 mm | 2.6 mohm | 2.6 mV |
| 0.8 mm | 1.4 mohm | 1.4 mV |

Copper's +0.393 %/degC puts the thin-and-hot case (0.4 mm at 60 degC) at
**~6.7 mV**. That is why the 20 mV threshold below keeps ~3x margin and is
therefore diagnostic of **joints**, not of the conductor.

The **joints** are the risk: pad solder joints, and — on a motorcycle — the two
12V screw terminals working loose under vibration.

## Netlist

### Transceiver

| Net | Holes (col,row) | Members |
|---|---|---|
| **+12V** | rail row 1 | terminal 12V IN (1,3), Q2 E (4,3), R6 top (6,1), transit 12V OUT (18,2) |
| **GND** | rail row 11 + col 18 | terminal GND (1,7), Q1 S (7,8), Rg bottom (9,11), D1 anode (4,11), R2 bottom via (13,9) → (13,11) (`j1850_signal_board.py:109`), comb GND (15,11), transit GND (18,4), all 6 Rb returns |
| **BUS** | (4,9); via (5,9)→(5,6)→(10,6) | terminal BUS (1,5) via (3,5)→(3,9), R5 bottom, D1 cathode, R1 left → IM pin 7 |
| **NODE_A** | (6,4) | R6 bottom, R4 top, Q2 B (via (4,4)) |
| **DRAIN** | (6,7)+(6,8) | R4 bottom, Q1 D |
| **GATE** | (8,8)+(9,8) | Q1 G, Rg top, R3 left |
| **TX** | (12,8) | R3 right → comb TX (15,8) |
| **NODE_B / RX** | (13,6) | R1 right, R2 top → comb RX (15,6) |

### Divider lanes (x6)

Each lane is identical. `rr` is the lane row, `gap` the adjacent empty row that
carries Rb horizontally:

| Lane | Signal | Input pin | Lane row `rr` | Gap row |
|---|---|---|---|---|
| G1 | turn L | (1,12) | 12 | 13 |
| G2 | turn R | (1,14) | 14 | 15 |
| G3 | high beam | (1,16) | 16 | 17 |
| G4 | neutral | (1,20) | 20 | 19 |
| G5 | oil | (1,22) | 22 | 21 |
| G6 | ignition | (1,24) | 24 | 23 |

Per lane: input (1,rr) → **Ra 10k** (8,rr)→(11,rr) → **node (11,rr)** → comb pin
(15,rr). From the node, (11,rr)→(11,gap) → **Rb 2k7** (11,gap)→(14,gap) →
(18,gap) on the GND rail. The **3V3 clamp** hangs off the comb pin through a
short jumper: (15,rr)→(16,rr), zener (16,rr)→(18,rr) to the GND rail.

## Component placement

| Part | Value | Pin A | Pin B | Net A → Net B |
|---|---|---|---|---|
| R6 | 10k | (6,1) | (6,4) | +12V → NODE_A |
| R4 | 10k | (6,4) | (6,7) | NODE_A → DRAIN |
| R5 | 100Ω | (4,6) | (4,9) | Q2 collector → BUS |
| Rg | 10k | (9,8) | (9,11) | GATE → GND |
| R3 | 1k | (9,8) | (12,8) | GATE → TX |
| R1 | 10k | (10,6) | (13,6) | BUS → NODE_B |
| R2 | 4.7k | (13,6) | (13,9) | NODE_B → (jumper to GND) |
| D1 | 7.5V zener | (4,9) **cathode/band** | (4,11) anode | BUS → GND |
| Q1 | IRLZ44N (TO-220) | D(6,8) · S(7,8) · G(8,8) | | DRAIN / GND / GATE |
| Q2 | 2N2907A (TO-92) | E(4,3) · B(4,4) · C(4,5) | | +12V / NODE_A / collector |
| Ra ×6 | 10k | (8,rr) | (11,rr) | input → node |
| Rb ×6 | 2k7 | (11,gap) | (14,gap) | node → (jumper to GND) |
| Dz ×6 | 3V3 zener | (16,rr) **cathode/band** | (18,rr) anode | node side → GND |

### Zener orientation — D1 first, it is the dangerous one

**Both types have the band (cathode) on the *signal* side.** But the two are not
the same severity, and this doc used to read as if they were:

1. **D1 (7.5 V, BUS clamp) — sits on the vehicle bus.** Band faces **BUS**
   (the top lead, (4,9)); anode to the GND rail at (4,11). **Backwards, D1
   forward-conducts and pins the bike's J1850 bus at ~0.7 V — it jams the bus**,
   taking the stock cluster and every other node down with it.
2. **The six 3V3 clamps — divider outputs only.** Band faces the **comb pin**
   side (the col-16 lead, (16,rr)); anode to the GND rail at col 18. Backwards is
   a *local* fault: the clamp forward-conducts and pins that one input at ~0.7 V,
   silently killing it. Not destructive, not bus-affecting.

**Mandatory: DMM diode-test all seven zeners, D1 FIRST, before any power is
applied.** This is a verification step, not a redraw item. The drawing source was
always correct — `zen()`'s band rectangle is anchored at the `c1` end only, so the
*source* is unambiguous — but the *render* the board was assembled from drew the
band at zorder 4, underneath `node(4,9,"BUS")` at zorder 6, so **D1's band was
completely invisible**. The band placement is fixed in the current drawing, but
this board was already soldered from the old one. That is why this check exists.

Splay each transistor's legs so every lead lands in its own pad — Q1 across
three adjacent columns of row 8, Q2 down three adjacent rows of col 4.

## Screw terminals

| Terminal | Pins | Purpose |
|---|---|---|
| **PWR/BUS 3p** (left) | (1,3) 12V · (1,5) BUS · (1,7) GND | harness in: fused +12V, J1850 bus (IM pin 7), ground |
| **3p harness A** (left) | (1,12) t-L · (1,14) t-R · (1,16) beam | discrete inputs, pitch-2 |
| **3p harness B** (left) | (1,20) neu · (1,22) oil · (1,24) ign | discrete inputs, pitch-2 |
| **transit 2p** (right edge, holes flipped) | (18,2) +12V · (18,4) GND | **out** to the power board |

## P4 comb (col 15)

> **The hole numbers below are PERFBOARD ROWS, not GPIO numbers.** In
> `j1850_signal_board.py`'s `comb_pins` the integers 12/14/16/20/22/24 are row
> indices, and `C_GPIO` in that source is a **colour**, not a pin. Rows **20, 22
> and 24 collide numerically with three real claimed pins** — GPIO 20 = J1850 RX,
> GPIO 22 = reserved fuel-sender ADC, GPIO 24 = J1850 TX. **That collision is a
> coincidence.** Do not read row 24 as GPIO 24.

| Hole | Pin | GPIO |
|---|---|---|
| (15,6) | RX | **GPIO 20** (`CONFIG_VROD_J1850_RX_GPIO`) |
| (15,8) | TX | **GPIO 24** (`CONFIG_VROD_J1850_TX_GPIO`) |
| (15,11) | GND | — (on the row-11 rail) |
| (15,12) | turn L | **unassigned** |
| (15,14) | turn R | **unassigned** |
| (15,16) | high beam | **unassigned** |
| (15,20) | neutral | **unassigned** |
| (15,22) | oil | **unassigned** |
| (15,24) | ignition | **unassigned** |

The six divider GPIOs are **not yet chosen**. Pick from the free header pool in
`../../firmware/docs/PINS.md`, confirm each physically with the bench
pin-wiggle test, then record them there and here. Do not guess them from the
header silkscreen order.

## Jumpers (tinned bus wire)

| From | To | Purpose |
|---|---|---|
| (1,3) | (1,1) | 12V IN → +12V rail |
| (1,5) → (3,5) → (3,9) | (4,9) | BUS IN → BUS node |
| (1,7) | (1,11) | GND IN → GND rail |
| (4,3) | (4,1) | Q2 emitter → +12V rail |
| (4,4) | (6,4) | Q2 base → NODE_A |
| (4,5) | (4,6) | Q2 collector → R5 top |
| (6,7) | (6,8) | R4 → Q1 drain |
| (7,8) | (7,11) | Q1 source → GND rail |
| (8,8) | (9,8) | Q1 gate → GATE node |
| (4,9) → (5,9) → (5,6) | (10,6) | BUS → R1 (runs along row 6, under R4) |
| (13,9) | (13,11) | R2 bottom → GND rail |
| (13,6) | (15,6) | NODE_B → comb RX |
| (12,8) | (15,8) | TX node → comb TX |
| (18,2) | (18,1) | transit 12V → +12V rail |
| (18,4) | (18,11) | transit GND → GND rail (down col 18) |
| (1,rr) | (8,rr) | ×6 — input → Ra |
| (11,rr) | (15,rr) | ×6 — node → comb pin |
| (15,rr) | (16,rr) | ×6 — comb pin → clamp (keeps the pin hole free) |
| (11,rr) | (11,gap) | ×6 — node → gap row |
| (14,gap) | (18,gap) | ×6 — Rb → right GND rail |

## Parts count

10k ×10 (R6, R4, Rg, R1 + 6× Ra) · 2k7 ×6 (Rb) · 4.7k ×1 (R2) · 1k ×1 (R3) ·
100Ω ×1 (R5) · 7.5V zener ×1 (D1) · 3V3 zener ×6 (clamps, optional but
recommended) · 2N2907A ×1 · IRLZ44N ×1 · 3-pin screw terminal ×3 · 2-pin ×1.

## Solder order

1. Resistors, lowest profile first: R6, R4, R5, Rg, R3, R1, R2, then the six Ra
   and the six Rb.
2. Zeners — **band per the placement table**: D1 band up, toward BUS (4,9); each
   clamp band toward col 16, away from the GND rail.
3. Transistors — **verify pinout first** (Q2's middle leg = base by DMM diode
   test; emitter goes up to +12V).
4. Bare-wire rails: +12V row 1, GND row 11, GND col 18.
5. Jumpers per the table. The row-6 BUS run and the (13,8) pass-under sit
   beneath component bodies — dress them flat before fitting anything over them.
6. Screw terminals (tallest) last.

## Ring-out BEFORE applying 12V (mandatory)

DMM in resistance mode; the red probe sources current. Nothing powered, nothing
connected to the bike or the P4.

1. **Rails not shorted:** +12V (row 1) ↔ GND (row 11 / col 18) = **open**. Any
   reading under ~1 kΩ is a fault — stop and find it.
2. **Transistors not shorted:** Q2 E(4,3) ↔ C(4,5) = open. Q1 D(6,8) ↔ S(7,8) =
   open.
3. **BUS ↔ GND = ≈14.7 kΩ** (R1 + R2, with Rpd omitted) with the **red probe on
   BUS (4,9)**, black on GND. Not zero, not open.
4. **D1 orientation:** swap the probes on the same two points — black on BUS,
   red on GND — and the reading must drop well below 14.7 kΩ (D1 forward). If it
   reads ≈14.7 kΩ in **both** directions, D1 is missing or open; if it reads low
   in **both**, D1 is shorted; if the low reading appears with red on BUS, D1 is
   **in backwards**.
5. **Comb pins:** RX (15,6) ↔ GND = **4.7 kΩ** (R2). TX (15,8) ↔ GND = **11 kΩ**
   (R3 + Rg). GND (15,11) ↔ GND rail = **0 Ω**.
6. **Each divider lane** (all six, one at a time):
   - input pin (1,rr) ↔ GND = **12.7 kΩ** (Ra + Rb)
   - comb pin (15,rr) ↔ GND = **2.7 kΩ**, red probe on the comb pin
   - input pin ↔ comb pin = **10 kΩ**
   - clamp check: swap probes on the comb-pin↔GND measurement. Correct → the
     reading drops below 2.7 kΩ (clamp forward). ≈2.7 kΩ both ways → clamp not
     fitted or open. Low both ways → shorted. Low with the **red** probe on the
     comb pin → clamp is **in backwards**.
7. **No bridges between lanes:** every divider comb pin ↔ every other divider
   comb pin = open. Every comb pin ↔ +12V rail = open.
8. **Transit terminal:** (18,2) ↔ +12V rail = 0 Ω; (18,4) ↔ GND rail = 0 Ω;
   (18,2) ↔ (18,4) = open.

Only after a clean ring-out apply power — **current-limited bench PSU first,
never the bike**.

## First power-up (bench, current-limited)

1. **Quiescent current, TX idle.** 12 V into the PWR/BUS terminal, limit
   ~200 mA. All figures below are **CALCULATED**, not measured, and assume
   Veb ~ 0.7 V with the rail at 12.0 V.

   At idle TX is low, so Rg (10k gate pull-down) holds Q1 **off**. With Q1 off
   the +12V → R6 → NODE_A → R4 → DRAIN path is **open**, and R6 ties Q2's base to
   the same +12V rail as its emitter, so Veb = 0 and Q2 is off too:

   **True quiescent current = leakage only, ~0 mA.**

   When Q1 *is* on (TX asserted) Q2's base-emitter junction clamps NODE_A near
   11.3 V — it does *not* sit at the unloaded R6/R4 midpoint of 6 V:

   - I(R4) = 11.3 V / 10 kΩ ≈ **1.13 mA**
   - I(R6) = 0.7 V / 10 kΩ ≈ **0.07 mA**
   - I(base) = I(R4) − I(R6) ≈ **1.06 mA**

   The diagnostic inversion is the whole point of the number:

   | Measured current on the +12V feed, TX idle | Meaning |
   |---|---|
   | ~0 mA (leakage) | **Correct.** Q1 off, Q2 off, bus not driven. |
   | ~0.6–1.1 mA | **FAULT: Q1 is stuck on.** Q2 is being driven and will jam the vehicle bus. **Do not connect to the bike.** |

   An earlier revision of this doc quoted ~0.6 mA (12 V / 20 kΩ) as the expected
   *quiescent* draw. That figure is not quiescent — it is the signature of the
   stuck-on-Q1 failure mode.

2. **Divider outputs.** Feed each discrete input from the same supply and measure
   its comb pin. 10k/2k7, so:

   | Input | Comb pin | Note |
   |---|---|---|
   | 12.0 V | **2.551 V** | engine off, key on |
   | 14.4 V | **3.061 V** | charging — the worst case |
   | 9 V | **1.913 V** | cranking brown-out; reads low, not a fault |

   **P4 GPIO absolute maximum is ~3.6 V**, so 3.061 V at charging voltage leaves
   ~0.5 V headroom. **Verify at 14.4 V before the comb ever touches the header.**

   Inverse diagnostic: an output **below ~1 V** means that lane's clamp is
   **reversed** — it is forward-conducting and pinning the node at ~0.7 V.
3. **TX idle:** with the TX comb pin floating or low, the bus node must sit
   recessive — Rg holds Q1 off, so Q2 is off. Confirm no current is being sourced
   into the bus node.

4. **Rail joint test (1 A). Can be done NOW — no power board needed, no 12 V.**

   Terminals (1,3) and (18,2) are the same net, reaching the rail through the
   jumpers at `j1850_signal_board.py:81` and `:129`. So put a bench PSU in
   **constant-current mode at 1 A directly across those two terminals**.
   Compliance voltage will be ~10 mV — far below Veb — so Q2, R6 and everything
   else stay off. No 12 V is applied anywhere and nothing on the board is at risk.

   Measure **4-wire style**: force the 1 A through the screw terminals and sense
   with a **separate** probe pair, DMM on **mV DC**. A 2-wire ohmmeter cannot
   resolve single milliohms — on the resistance range it will read "0.0 Ω, fine"
   and tell you nothing.

   | Sense across | Covers | Expect |
   |---|---|---|
   | (1,1) → (18,1) | rail conductor only | a few mV |
   | (1,3) screw → (18,2) screw | conductor + both jumpers + both screw joints | a few mV |
   | **the difference** | **the joint resistance** | ~0 |

   **Interpretation: >20 mV across (1,3)→(18,2) at 1 A means a bad joint, not a
   thin wire** — the conductor cannot account for more than ~7 mV even thin and
   hot. **Re-flow, don't re-wire.**

5. **Screw terminals.** Torque both 12V terminals, then **re-check step 4 after
   the first heat cycle** — screw terminals on solid wire relax, and on a
   motorcycle that is the live failure mode in this path.

> **Bench self-sniff needs a temporary Rpd.** Rpd is omitted on this board, so
> on an isolated bench the bus has no defined recessive-LOW and loopback
> self-sniff will misbehave. Tack ~10k from BUS (4,9) to GND for bench work and
> **remove it before installing on the bike** — the vehicle's other nodes hold
> recessive.

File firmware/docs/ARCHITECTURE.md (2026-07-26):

# V-Rod cluster — architecture

How the firmware fits together, and *why* each non-obvious choice is the
way it is. CLAUDE.md is the day-to-day cheat sheet; this file is the
context behind it.

## Package layout (roles)

`main/` is organised into four role packages, promoting a boundary that was
always implicit ([ADR 0001](../../docs/adr/0001-engine-display-split.md)). Each
directory carries a `README.md` with its full contents and rules:

| Package | Role | Never contains |
|---|---|---|
| `engine/` | The bike node: J1850 + vehicle aggregation + sim producer + `command_handler`. Produces `vehicle_data`. | radios, LVGL, GPS, media/settings |
| `connectivity/` | Radios + the phone bridge (`ble/`, `phone/`). Data in, state out. | direct calls into engine internals |
| `contract/` | The shared seam — typed `command` dispatch; protocol spec in `docs/reference/CONTRACT.md` + `zeppl.dbc`. | radios, LVGL, driver deps |
| `display/` | The head unit: widgets, screens, `map/`, `gps/`, `settings/`, `sound/`. | vehicle-source or radio code |

The load-bearing rule: **connectivity and display reach the engine only through
`contract/command`** (a synchronous dispatch seam), so a display or radio can be
swapped without the engine knowing. This is what makes "engine here, display
elsewhere" — and the eventual CAN/DBC interop + board split — tractable. The
threading model below is orthogonal: it's about *which core* runs each task, not
*which package* owns the code.

## Threading model

Two cores on the ESP32-P4. Pinning is deliberate.

| Task | Core | Prio | Purpose |
|---|:----:|:----:|---|
| `sim_task` |  0 |  8 | Synthetic driving cycle → `vehicle_data` |
| `event_watcher_task`  |  0 |  5 | Polls indev + `vehicle_data` at 100 Hz for events |
| `audio_task` |  0 |  3 | Pulls click events from queue, writes to I2S codec |
| `ui_update_task` |  1 |  4 | 30 FPS widget setter sweep |
| LVGL render pthread |  1 |  4 | Composes dirty regions, flushes to DSI |

**Why event detection isn't in `ui_update_task`.** The UI task takes
`bsp_display_lock(-1)` before calling widget setters. LVGL's render
thread holds the same lock during compose. On a heavy frame (cursor +
shift-light + turn arrows all redrawing) the UI task waits on that lock,
which means turn-signal-edge detection and long-press timing stop being
sampled — inputs feel sluggish. `event_watcher_task` polls
`lv_indev_get_state()` and `vehicle_data` directly at 100 Hz on the
sim's core, where there's nothing to compete with, and only grabs the
LVGL lock briefly to call `ui_manager_show_settings` when a long-press
fires.

**Why audio is on core 0, not core 1.** Earlier the audio task lived on
core 1 with LVGL. `esp_codec_dev_write` blocks for ~30 ms while feeding
DMA; whenever LVGL was rendering a heavy frame at the same time, audio
queueing latency jumped and turn-signal clicks felt off-sync with the
arrows. Moving the audio task to core 0 (where the sim sleeps 45 of
every 50 ms) gives the codec writes a quiet neighbour and the clicks
stay locked to the visual.

## Shared state

- **`vehicle_data`** is the single source of truth between the producer
  (sim today, J1850 driver tomorrow) and the UI. Mutex-guarded. Sim
  writes the whole struct under the lock; consumers `vehicle_data_get`
  a snapshot.
- **`settings_store`** (NVS) loads at boot and exposes a stable pointer
  via `settings_store_current()`. Mutations happen inside settings-screen
  event callbacks, which run under `bsp_display_lock` — that serialises
  them against `ui_update_task`'s reads. No extra mutex needed.

## Render pipeline (the tach is the interesting case)

> The hard rules and the full reasoning live in
> [`DISPLAY-PERF-AND-MEMORY.md`](DISPLAY-PERF-AND-MEMORY.md). Read it before
> changing anything that draws. Short version below.

Everything dynamic is reduced to **swapping a pre-baked ARGB8888 sprite** (a
blit), never a per-frame transform or vector rasterization. Only the
ARGB→RGB565 blender is in fast SRAM; everything else draws from PSRAM XIP, so a
blit is fast and a transform/rasterize is ~5–20× slower.

| Sprite | Size | What it is |
|---|---|---|
| Tach track/glow | 800×800 | gray rail + Gaussian glow + redline band (was an |
| | | `lv_arc`), baked once |
| Tach scale ticks | 800×800 | 21 ticks at angle + redline colour (was `lv_scale`) |
| Tach cursor | 84×84 | **91 pre-rotated + pre-coloured** buckets (3° steps);|
| | | swap `src` per frame, no runtime rotation |
| Tach zoom labels | per lvl | 6 labels × **16 pre-scaled** sprites; swap `src` by |
| | | zoom level, no runtime scale |
| Fuel arc ticks | 280×52  | **one** strip image, redrawn into its buffer only |
| | | on a fuel-level change (not 21 `lv_obj`s) |

**Why bake the track + ticks.** The original `lv_arc`/`lv_scale` re-walked the
arc path and 21 tick segments in every cursor-movement dirty rect. Baking makes
the per-frame cost a blit.

**Why the cursor and labels are baked per-state, not transformed.**
`lv_image_set_rotation` / `set_scale` run the PSRAM-resident transform
rasterizer every frame (~100–155 ms during a sweep → ~7 FPS). Baking each
discrete angle/zoom and swapping `src` makes per-frame cost a blit. Per-element
caches mean only the changed sprite swaps.

**Why the fuel arc is one image, not 21 tick objects.** Recolouring +
invalidating ~21 scattered `lv_obj`s in one frame crashed the device's
triple-partial DSI render path (an instruction-access fault that never
reproduced in the simulator). One image = one invalidation = safe.

## Upshift warning — the long story

The warning has been through several iterations. Recording them here so
nobody re-tries an approach we already discarded.

1. **5 Hz blinking full-screen ring** (`lv_obj` with circular border).
   Each visibility toggle invalidated the entire 800×800 framebuffer.
   At 10 invalidates/sec the triple-buffer copy stalled the audio +
   tach pipeline; visible stutter.
2. **Solid full-screen ring**. Only invalidated twice per WOT pull, but
   the ring's bounding rect IS the screen, so any other widget that
   overlapped it (cursor at the bezel, etc.) caused per-frame
   ring-pixel recompose.
3. **`lv_arc` with the same sweep as the tach**. Same cost story as the
   ring; visual was nicer but performance unchanged.
4. **Line-arc colour fade + glow-opacity fade**. Each LVGL refresh
   during the 150 ms fade invalidated the line arc's 800×800 bounding
   rect — 10× full-tach redraws crammed into the worst possible 150 ms,
   right when the cursor was moving fastest. Laggy.
5. **2 Hz blink of the line + glow swap**. Less dense than the fade
   but same per-toggle invalidation cost. Still laggy.
6. **Blink the gear digit**. Current implementation. `gear_indicator`
   is ~80×110 px — invalidating it costs ~70× less per blink than the
   tach area, and the timer fires 4×/sec instead of 60×/sec.

## Boot sequence

```
bsp_display_start_with_config   // panel + LVGL up, backlight at LEDC duty 0
settings_store_init             // NVS open, defaults if first boot
vehicle_data_init               // data sources must be live before
phone_data_init                 //   boot_screen_show's safety-timer
j1850_driver_init               //   producer; fast-path into the ride screen
bsp_display_lock                // hold the LVGL lock for the paint sequence
  loop 3×:                      //   triple-partial has 3 PSRAM framebuffers
    invalidate(scr) + lv_refr_now + unlock + 20ms + lock
                                //   cycles all three buffers to black so
                                //   none of them shows PSRAM init garbage
                                //   (~0xFFFF / white) when the panel lights
  boot_screen_show              //   GIF widget paints on top of black
  lv_refr_now
bsp_display_unlock + 20ms       // last DMA flush reaches the panel
bsp_display_brightness_set      // LIGHTS THE PANEL at saved brightness — this
                                //   is the moment the user sees the screen
sound_init / sound_set_*        // codec, queue, click sample baked
ble_peripheral_init             // NimBLE host, esp_hosted VHCI brings up
                                //   the BLE controller on the C6
                                // GIF eventually hands off to ride screen
                                //   on LV_EVENT_READY (or 15 s safety)
```

The `bsp_display_brightness_set()` is the only call that actually turns
the backlight on. `bsp_display_backlight_on()` is just
`bsp_display_brightness_set(100)`; any duty change lights the panel.
Painting black-then-GIF before that call is what prevents the boot
white flash.

## Out-of-band timing notes

- **Sim tick**: 20 Hz (50 ms). Writes a complete `vehicle_data` snapshot
  per tick.
- **UI tick**: 30 Hz (33 ms). Reads `vehicle_data`, runs the widget
  setter sweep under `bsp_display_lock`.
- **Event watcher tick**: 100 Hz (10 ms). Independent of LVGL load.
- **LVGL refresh**: `CONFIG_LV_DEF_REFR_PERIOD=33` (~30 Hz, matching
  the UI tick — see `DISPLAY-PERF-AND-MEMORY.md`).
- **Boot GIF**: native 600×600, software blit. Native 800×800 was
  attempted but smoothness suffered when PPA was disabled (see
  CLAUDE.md gotchas).

## Tried and rejected

- **PPA** for the cooked-GIF blit. Caused horizontal banding on this
  BSP's DSI tear-avoid triple-buffer setup. Re-enable only with a
  known-good alignment story.
- **Lottie / ThorVG** for the boot animation. Vector rasterisation at
  800×800 isn't real-time on the P4. Don't retry unless either the
  resolution drops to ≤200×200 or ThorVG's rasteriser gets much faster.
- **LVGL `LV_EVENT_PRESSED` / `_LONG_PRESSED`** for touch on the ride
  screen. Hover events fired but press never reached the screen on this
  BSP. We bypass LVGL's gesture system and poll `lv_indev_get_state()`
  directly from `event_watcher_task`.
- **Line color animation / glow opacity animation** for the upshift
  warning. See the "long story" above.

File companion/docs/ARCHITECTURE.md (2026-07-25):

# Companion app architecture

Android BLE-central app (`ee.zeppl.companion`, Kotlin + Jetpack Compose) that
bridges phone notifications / media / calls to the cluster over a custom GATT
link and relays live telemetry back. Wire format: [PROTOCOL.md](PROTOCOL.md);
calibration math: [CALIBRATION.md](CALIBRATION.md).

## Packages

```
ee/zeppl/companion/
├── ble/     BLE central, GATT client, wire protocol, telemetry, calibration collectors
├── cal/     Pure calibration math (SpeedCalibrator, FuelEconomy) — unit-tested
├── media/   MediaSessionManager watcher → wire format
├── notif/   NotificationListenerService bridge + per-app allow-list
├── ride/    Ride recorder + store (trip history / economy trends)
└── ui/      Compose app: theme/, adaptive nav shell, tab screens, calibration cards
```

### `ble/` — the link
- **`BleService`** — a foreground service (`FOREGROUND_SERVICE_CONNECTED_DEVICE`)
  that owns the GATT connection so it survives the UI being backgrounded. This
  is the hub everything else talks to.
- **`BleClient` / `BleScanner` / `BleAccess`** — GATT connect/read/write/notify,
  scanning, and the runtime-permission gate.
- **`BondTracker` / `BondedClusters` / `ClusterNames`** — persist bonded cluster
  addresses + friendly names (multiple clusters supported).
- **`ReconnectPolicy`** — on link loss (supervision timeout = power cycle /
  out-of-range) re-arms a background `connectGatt(autoConnect=true)` to the
  bonded address, so the link heals every ignition cycle. Deliberate
  disconnects stay disconnected.
- **`Protocol`** (encoder) + **`TelemetryCodec`** (decoder) + **`TelemetryState`**
  — the wire format and the decoded live-frame state the UI observes.
- **`CommandHandler`** — dispatches cluster-issued commands into `TelecomManager`
  (call accept/reject/end) and media transport.
- **`IconCodec` / `IconSender`** — stream app-icon bitmaps (48×48 RGB565) the
  cluster caches and renders on notification banners.
- **`SpeedCalCollector` / `CalibrationSession` / `RideCollector`** — sample the
  telemetry stream (`speedRaw`, fuel ticks) to feed `cal/`.
- **`LocationSender`** — forwards phone GPS fixes (`LOCATION` events) for the
  map's dual-source position.

### `cal/` — pure, testable
`SpeedCalibrator` (least-squares divisor solve) and `FuelEconomy` (mL/tick +
range) have no Android deps and are JVM-unit-tested against the firmware's C
fixtures. See [CALIBRATION.md](CALIBRATION.md).

### `media/` + `notif/` — the sources
- **`notif/ZepplNotifListener`** — a `NotificationListenerService` (needs the
  system notification-access grant) → `NotifMapper` → `Protocol.encodeNotif`,
  filtered by a per-app **`AllowList`** (`AppListProvider` enumerates installed
  apps for the picker).
- **`media/MediaWatcher`** — a `MediaSessionManager` listener (rides on the same
  notification-access grant) → `MediaMapper` → `MediaPublisher`.

### `ui/` — Compose
Material 3 **Expressive** (spring `MotionScheme`), branded Zeppl dark theme
mirroring the cluster palette (`ui/theme/`). Adaptive `NavigationSuiteScaffold`
(bottom bar on phones, rail on tablets/folds) over a type-safe route NavHost,
with a persistent connection-status strip. Four tabs: **Ride** (live telemetry
dashboard), **Cluster** (link + bond management), **Settings** (relay
allow-list + appearance + config write-back), **History** (trips + economy).
Plus a **Developer** screen for the calibration wizards.

## Data flow

```
Phone events                         Cluster
────────────                         ───────
NotificationListener ─┐
MediaSessionManager  ─┤
Telecom (call state) ─┼─► Protocol.encode ─► BleService ══(RX write)══► parser ─► gauge
Phone GPS ───────────┘

TelemetryState ◄─ TelemetryCodec.decode ◄══(TX notify)══ vehicle_data (~4 Hz)
CommandHandler ◄─────────────────────────(TX notify)══ rider actions on the gauge
       └─► TelecomManager / MediaController
```

## Threading & lifecycle

- The **foreground service** (`BleService`) is the long-lived owner of the GATT
  link; the Compose UI observes state flows from it and can come and go.
- `NotificationListenerService` + the media watcher are system-bound and
  independent of the Activity lifecycle.
- Calibration + fuel math run on the sampled telemetry; persistence
  (`ride/RideStore`, prefs) is app-local.

## Testing

JVM unit tests (`app/src/test/`, Robolectric where Android APIs are touched):
`ProtocolTest` / `TelemetryCodecTest` (wire format vs the firmware fixtures),
`SpeedCalibratorTest` / `FuelEconomyTest` (calibration math), `BleStateTest`,
etc. Run with `make test-app`.

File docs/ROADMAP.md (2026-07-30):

# Zeppl — Roadmap

The single stage-by-stage map of the build: four phases, each with a status and
links to its detail docs. The narrative status snapshot is in
[`PROJECT-BRIEF.md`](PROJECT-BRIEF.md); the evergreen hardware/bus reference is
in [`reference/`](reference/).

**Legend:** ✅ done · ⏳ active · ◻ pending · ✖ dropped

## Phases at a glance

| Phase | Scope | Status |
|---|---|---|
| **1 — Firmware & Gauge UI** | display, widgets, touch, settings, Android BLE relay, sim, test gate | ✅ complete |
| **2 — J1850 Bus + IM Simulation** | RX/decode/TX/DTC transceiver + companion telemetry / calibration | ⏳ active |
| **3 — Cluster Replacement (hardware)** | discrete signals, RX hardening, enclosure, permanent install | ◻ pending |
| **4 — Polish & Daily Ride** | OTA, moving map + GPS, auto-brightness, themes, iOS BLE | ◻ ongoing |

> **History note:** earlier drafts used a messier numbering (a "Phase 2.5", a
> dropped "Phase 5"). It's now a clean 1-4. The **speed-camera / GPS-for-speed**
> work was **dropped** (Jul 2026) — speed comes from the J1850 bus; a
> map-position-only NEO-6M was later revived as an opt-in map source (Phase 4).

## Phase 1 — Firmware & Gauge UI ✅

The whole off-bike firmware foundation, built while the J1850 hardware shipped.

- **Gauge UI** (BMW-EfficientDynamics styling): tach (270° arc + redline +
  shift-light), speed, gear, fuel, temp, turn signals, 7 warning lamps, clock +
  odo + dual trips. Driven by `vehicle_data_t` off a synthetic driving cycle;
  30 fps with skip-if-unchanged caches; sim/UI core-pinned. Real renders:
  [`screens/`](screens/README.md). Detail:
  [`../firmware/docs/plans/phase1-display-plan.md`](../firmware/docs/plans/phase1-display-plan.md).
- **Touch + screens** (GT911 → LVGL indev + screen manager), **settings**
  (kph/mph, temp unit, brightness, trip reset) persisted to NVS, units threaded
  through every widget.
- **Android companion** (`companion/`): notifications + media over BLE GATT
  (TLV), LE Secure Connections bonding, directed advertising, auto-reconnect.
  (**iOS** ANCS/AMS deferred → Phase 4.)
- **Simulator** (desktop SDL2 + LVGL) + a **CI-enforced 100% line/branch
  host-test gate** over all pure-logic + widget code.
- Detail + loose ends: [`phases/phase1-offbike.md`](phases/phase1-offbike.md).

Ride gauge screen

## Phase 2 — J1850 Bus + IM Simulation ⏳

The first phase that touches the bike. Full detail:
[`phases/phase2-j1850.md`](phases/phase2-j1850.md). Bus reference:
[`reference/J1850-BUS.md`](reference/J1850-BUS.md).

| Stage | Scope | Status |
|---|---|---|
| 1 | Bench transceiver (RX + TX halves) | ✅ built; full PCB fabricated |
| 2 | Passive sniff (bike + proxy, stock cluster in) | ✅ live sniff (2026-07-04) |
| 3 | Decode → `vehicle_data` producer | ✅ RPM/temp/speed/turns/CEL/immobiliser |
| 3.5 | On-board ride log (laptop-free) | ✅ SD/FATFS sink |
| 4 | TX + IM replay | ✅ **on-bike validated (2026-07-24)** |
| 5 | Companion: telemetry, GPS cal, DTC | ⏳ telemetry/GPS/config/fuel done; DTC read done, clear+view open |

- **Fitted board: [`j1850_signal_board`](../docs/schematics/j1850_signal_board.md)
  (v4).** Transceiver **plus** the six 12V dividers on one 18×24 perfboard. It is
  the board on the bike and the one that carries every logged on-bike result —
  "fabricated PCB" in the logs means this board. **Its remaining gate is a ride**
  ([`../firmware/docs/rides/ride-3-plan.md`](../firmware/docs/rides/ride-3-plan.md));
  engine-off, engine-on and cold-start crank are all validated. The transceiver
  half is in service; the divider lanes are populated but unconnected at both ends
  and their GPIOs are unassigned. **F1 is not yet installed** — see the deviation
  note in
  [`../firmware/docs/reference/bike-power-injection.md`](../firmware/docs/reference/bike-power-injection.md).
- **Stage 4 — on-bike validated (2026-07-24).** The fabricated PCB does full
  bidirectional J1850 on the live bike: **312 consecutive clean TX sends, 0
  watchdog faults** across engine-off/on + two cold-start cranks; stock cluster
  attached, no DTCs. Record:
  [`../firmware/docs/rides/stage4-tx-bench-log.md`](../firmware/docs/rides/stage4-tx-bench-log.md).
- **Stage 5 — DTC read built + validated.** `dtc.c` codec (HD J1850 read/clear
  + response decode + J2012 format, ported from HarleyDroid) +
  `CONFIG_VROD_J1850_DTC_PROBE` read all three modules clean on the bike.
  Protocol: [`../firmware/docs/reference/dtc-read-probe.md`](../firmware/docs/reference/dtc-read-probe.md).
- **Speed divisor locked at 188** (Ride 2, 2026-07-09) by gear-ratio physics +
  a roadside-radar point — **not** GPS; the GPS calibration wizard is built but
  its on-bike sampling was fixed only after that ride, so a GPS calibration is
  still unexercised (a cross-check on the locked 188, not a blocker). See
  [`../firmware/docs/rides/ride-2-findings.md`](../firmware/docs/rides/ride-2-findings.md).

## Phase 3 — Cluster Replacement (hardware) ◻

Take the stock cluster out and run standalone. Full detail:
[`phases/phase3-cluster.md`](phases/phase3-cluster.md).

- **Read all 12-pin discrete signals** (turns, beam, oil, neutral, fuel). The
  ×6 divider is identical hardware; **polarity is a per-line firmware flag** —
  measure both states, never hard-code. Confirmed: neutral = **active-low**,
  turns = **active-high**; high beam / oil / ignition still TBD.
- **Fuel:** the 2009 VRSC uses an **ultrasonic** sender (not on the bus) —
  needs a discrete tap + our own calibration; fallback is integrating the ECM's
  J1850 fuel-consumption ticks (`A8 83 10`).
- **RX front end — add hysteresis** (comparator / Schmitt) for the permanent
  harness to cut the engine-EMI bad-CRC margin (the TX path is already clean).
  See [`../firmware/docs/reference/j1850-toggling-isr-candidate.md`](../firmware/docs/reference/j1850-toggling-isr-candidate.md).
- **Enclosure:** parametric OpenSCAD case (`hardware/enclosure/`) — designed +
  rendered, not yet printed. Conformal-coat, permanent install, keep the proxy
  box as a toolbox backup.
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

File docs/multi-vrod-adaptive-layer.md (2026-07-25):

# Multi-V-Rod adaptive decode layer — design

**Status:** Implemented (2026-07) — landed as PR series #42–#52; see the phased
plan at the end for what's done vs. deliberately deferred. Companion to
[ADR 0001](adr/0001-engine-display-split.md) (the engine/connectivity/display
split that makes this tractable) and
[`reference/CONTRACT.md`](reference/CONTRACT.md) (the canonical, bike-agnostic
state model).

## Purpose

Today the cluster is reverse-engineered against **exactly one bike — a 2009
VRSCF Muscle**. This document designs the adaptive layer that lets Zeppl decode
*other* VRSC-line bikes without us having physical access to each one, and lets
the **owner of an unknown bike** produce the data we need — no scope, no
soldering, no J1850 knowledge.
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

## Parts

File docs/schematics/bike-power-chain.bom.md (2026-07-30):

# BOM — protected bike-power chain (12V → 5V)

> **⚠ CURRENT DEVIATION — F1 is NOT installed.** F1 is specified inline in the
> harness at the IM pin-6 tap; it is not fitted. The `j1850_signal_board` (v4) is
> drawing from pin 6 **unfused**, backed only by the vehicle's own IM-circuit fuse,
> which is sized for the instrument module and not for our conductor. **Blocking:
> fit F1 before the next on-bike session and unconditionally before the power board
> is connected.** Detail:
> [`../../firmware/docs/reference/bike-power-injection.md`](../../firmware/docs/reference/bike-power-injection.md).

Bill of materials for the `bike-power-chain.py/.svg` drawing. Derived from the
parts table in [`../../firmware/docs/reference/bike-power-injection.md`](../../firmware/docs/reference/bike-power-injection.md);
keep the three in sync (drawn part = parts-table part = BOM row). Order is
bike-side to board.

| Ref | Part | Value / Rating | Package | Qty | Notes (purpose) |
|---|---|---|---|---|---|
| F1 **(HARNESS — do not solder to the power board)** | Automotive blade fuse + inline holder | 2 A, 32 V | ATM / mini blade | 1 | Protects the feed wiring against a short at the tap; blade fuse is slightly slow so it tolerates the mini560 inrush. Bump to 3 A only if inrush nuisance-blows. **Inline in the harness at the 12V tap, upstream of the signal board** — it fuses both branches. The row stays in this BOM because F1 is the chain's first part and still has to be bought; it is simply not a board component. |
| D2 | Schottky, series reverse-polarity — SB560 (60 V/5 A) or SS54 (40 V/5 A) | ≥40 V, ≥3 A | DO-201AD / SMC | 1 | Blocks a swapped +12V/GND at the mini560 input. Low-loss alternative: a P-channel MOSFET. |
| TVS1 | TVS, unidirectional — P6KE16A | 16 V standoff, ~26 V clamp @ I_PP, 600 W | axial (DO-15) | 1 | Load-dump / spike clamp across the mini560 12V input; ~26 V clamp sits ~2 V under the mini560 ~28 V abs-max. Axial/leaded for the potted flying module. Higher-energy alternative: 1.5KE16A (1500 W). |
| mini560 | MP1584-class 12V→5V buck module | Vin 4.5–28 V, Iout ~3 A, **set 5.0 V** | module | 1 | Steps 12V down to 5.0 V. Trim to exactly 5.0 V for the XL74610 ideal-diode path (no drop compensation). |
| D4 | XL74610 ideal-diode module (LM74610-based) | ~1.5–36 V, 30 A, ~tens-of-mV drop | module | 1 | Output reverse-block the header lacks (blocks `VCC_5V` → mini560); primary/drawn. Fallback: SS34 Schottky (40 V/3 A, SMA/DO-214AC) → then set the mini560 to 5.35 V to compensate. |

Notes:
- **5 V-rail bulk cap:** *unspecified* — `bike-power-injection.md` does not list a
  bulk/electrolytic cap on the 5 V rail, so none is included here. Add one per
  board/module guidance if bench testing shows it's needed.
- **On-board parts are not in this BOM.** The board's own USB reverse protection
  (AO3401 + MMDT3906DW) and its ESD clamp (D3 SMF5.0CA) are already fitted on the
  Waveshare board; only the injection-chain parts above are to be sourced.

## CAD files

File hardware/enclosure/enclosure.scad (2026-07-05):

// ============================================================================
// Waveshare ESP32-P4-WIFI6-Touch-LCD-3.4C -- parametric round enclosure
// REAR-BOLT BOARD FIXATION REV (motorcycle / vibration). No threads, no snap-fits.
// ----------------------------------------------------------------------------
// The PCB is mounted the way it was designed to be: BOLTED at its 4 mount holes
// (74.5 mm square) to internal standoffs, with the bolts driven from the REAR
// through the open back (the rear cover is removable, so the holes -- though under
// the glass from the front -- ARE reachable from behind). Bolts land in METAL (M3
// brass heat-set inserts in chunky, wall-gusseted standoffs), never printed threads.
//
//   [ bezel ring ]        frames + protects the glass edge (light duty)
//   [ glass + PCB ]        one bonded block, 7.6 mm (glass 6 + pcb 1.6), touching;
//                          inserts from the front, glass to a front lip
//   [ standoffs ]          4 chunky gusseted posts behind the PCB at the 74.5 sq;
//                          M3 heat-set inserts -- the board's primary load path
//   [ deep cavity ]        ~50 mm for breadboard + mini560 + wiring
//   [ rear cover ]         REMOVABLE -- reach the 4 board bolts + wiring, then close
//
// Direct board bolting is the primary fixation; edge-compression is dropped as the
// main load path (the bezel now just frames/protects the glass). A gasket under the
// glass rim + between PCB and standoffs stays for vibration damping.
//
// mount_square = 74.5 is LOAD-BEARING again (the rear board bolts use it).
//
// Modes (-D 'part="..."'):
//   rear_case | bezel | rear_cover | calibration_base | assembly
// Tiers (-D 'tier="..."'):  simple | robust | compromise(default)
//
// Coordinate frame: z=0 at the front rim (glass front), +z runs REARWARD.
// ============================================================================

part = "rear_case";     // rear_case | bezel | rear_cover | calibration_base | assembly
tier = "compromise";    // simple | robust | compromise
fastener = "auto";      // auto (tier default) | heatset | captured_nut

$fn = 128;              // $fn = circle facet count -> smooth round shell

// ---- CONFIRMED / locked ----------------------------------------------------
glass_od           = 115;   // measured cover-glass OD (== overall display face)
glass_thickness    = 6;
display_active_dia  = 87.6; // KEEP OPEN -- never covered
pcb_w = 86; pcb_h = 65;     // PCB outline (smaller than the glass; fully backed by it)
pcb_thickness = 1.6;
mount_square = 74.5;        // LOAD-BEARING: the 4 rear board bolts mount here
internal_depth = 50;        // electronics cavity depth (breadboard + mini560 + wiring)

// ---- Bonded block: glass + PCB, faces touching (7.6 mm) ---------------------
block_gap = 0;              // glass-rear to PCB-front; 0 = touching (bonded)

// ---- Tier presets (tune per build tier; don't fork geometry) ----------------
function t_wall(t)    = t=="robust" ? 4.0 : 3.0;
function t_floor(t)   = t=="robust" ? 4.0 : t=="simple" ? 4.0 : 3.5;
function t_screws(t)  = t=="simple" ? 4   : 6;   // keep 6 perimeter screws (simple=4)
function t_gasket(t)  = t=="robust" ? 1.0 : t=="simple" ? 1.0 : 0.6;
function t_fastener(t)= t=="simple" ? "captured_nut" : "heatset";
function t_standoff(t)= t=="robust" ? 11 : t=="simple" ? 9 : 10;   // chunky board-post dia

wall            = t_wall(tier);
floor_thickness = t_floor(tier);        // rear_cover thickness (the removable "floor")
screw_count     = t_screws(tier);
gasket_gap      = t_gasket(tier);       // foam/silicone slot behind the glass rim
fastener_r      = fastener=="auto" ? t_fastener(tier) : fastener;
standoff_od     = t_standoff(tier);     // >= 8, chunky; wall-gusseted, never a thin stalk

// ---- Fits ------------------------------------------------------------------
glass_fit = 0.5;            // diametral clearance for the glass in its bore
block_fit = 0.5;

// ---- Fastening -------------------------------------------------------------
screw_dia         = 3.0;    // M3
screw_clearance   = 0.6;    // -> 3.6 shaft clearance
insert_hole_dia   = 4.0;    // M3 brass heat-set insert seat (melt-in) -- METAL, not printed
insert_depth      = 6.0;
nut_af            = 5.5;    // M3 hex nut across-flats
nut_thick         = 2.4;
nut_pocket_extra  = 0.3;    // clearance on the hex pocket
csk_dia = 6.2; csk_depth = 2.0;   // countersink for the M3 screw head in the bezel

// ---- Bezel / screw ears ----------------------------------------------------
screw_boss_gap = 5.0;       // radial gap: glass edge -> screw axis (screws outside Ø115)
screw_boss_od  = 9.0;
bezel_th       = 4.0;
bezel_open_dia = display_active_dia;    // 87.6 open -- never covers the active area
bezel_relief   = 0.6;       // underside relief: bezel presses only the OUTER glass rim
ear_depth      = 12.0;      // screw-boss column depth (front)
ledge_overlap  = 2.5;       // how far the block-seat ledge reaches in over the glass rim
ledge_th       = 3.0;

// ---- Board standoffs (PRIMARY board fixation, at the 74.5 square) -----------
standoff_len       = 14.0;  // post depth behind the PCB (insert + solid base)
gasket_under_pcb   = 0.8;   // foam/silicone pad between PCB rear and standoff tops (0.5-1)
gusset_span        = 15;    // deg each side: fan gusset arc from post to wall
gusset_h           = 10.0;  // gusset taper height (full fan at the base -> post at the top)

// ---- Rear cover fixation ---------------------------------------------------
rear_boss_len = 10.0;       // rear screw-boss depth (rear_cover -> rear_case)
rc_lip        = 4.0;        // rear_cover locating lip into the bore

// ---- Cable exit -- ONE bottom hole (TEMP test enclosure) -------------------
// This is a bench/test build: all wiring (power, J1850 tap, USB if used) exits
// through a single grommet hole at the BOTTOM of the wall. microSD access on this
// temp build is by removing the rear cover (a dedicated slot comes on the final one).
cable_hole_dia   = 12;      // size for the wire bundle + grommet
cable_exit_angle = 270;     // deg CCW from +X; 270 = bottom (wires drop toward the bike)
cable_exit_z     = 35;      // z-centre in the cavity (behind the standoffs, ahead of rear bosses)
// Per-connector cutouts dropped for the temp build -- kept here for the FINAL enclosure:
// usb_c_angle = 0;   usb_c_w = 12;  usb_c_h = 7;
// microsd_angle = 40; microsd_w = 14; microsd_h = 5;   // MUST stay reachable (ride-log card)
// power_boot_angle = 90; power_boot_w = 16; power_boot_h = 6;
// harness_angle = 200; harness_w = 34; harness_h = 12;  // 40-pin harness exit

// ---- Handlebar mount = OUT of scope (metal load path, separate task) --------
// A future aluminium strap to the triple-tree riser bolts (M10x1.5, ~89 mm
// spacing) would attach near the rear-case wall here. Metal, not printed.
// mount_strap_angle = 270; mount_strap_boss_w = 24; mount_strap_boss_h = 16;

// ============================================================================
// Derived
// ============================================================================
glass_bore_dia = glass_od + glass_fit;              // 115.5
wall_inner_r   = glass_bore_dia/2;                  // 57.75
main_outer_dia = glass_bore_dia + 2*wall;
R_screw        = glass_od/2 + screw_boss_gap;       // screw axis radius (outside Ø115)
ear_outer_r    = R_screw + screw_boss_od/2;
overall_dia    = 2*ear_outer_r;                     // OD at the screw ears
screw_clear_dia = screw_dia + screw_clearance;      // 3.6
ledge_in_r     = glass_od/2 - ledge_overlap;        // block-seat inner radius
ledge_id       = 2*ledge_in_r;

// z-levels (z=0 = front rim = glass front, +z rearward)
glass_front_z = 0;
glass_rear_z  = glass_thickness;                    // 6
pcb_front_z   = glass_rear_z + block_gap;           // 6 (touching)
pcb_rear_z    = pcb_front_z + pcb_thickness;        // 7.6
ledge_front_z = glass_rear_z + gasket_gap;          // gasket sits glass-rim-rear .. ledge
ledge_rear_z  = ledge_front_z + ledge_th;
standoff_front_z = pcb_rear_z + gasket_under_pcb;   // post top sits a gasket behind the PCB rear
standoff_rear_z  = standoff_front_z + standoff_len;
rear_plane_z  = ledge_rear_z + internal_depth;      // rear opening
calib_depth   = max(standoff_rear_z, ear_depth) + 3;

// ============================================================================
// Helpers
// ============================================================================
module tube(od, id, h) { linear_extrude(h) difference(){ circle(d=od); circle(d=id); } }
module hexprism(af, h) { cylinder(d=af/cos(30), h=h, $fn=6); }   // af = across-flats
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

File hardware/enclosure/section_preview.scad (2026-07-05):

// Cross-section inspector. Half-cut (remove y<0), rotated -45deg so the cut
// passes through two opposite board standoffs (the 74.5 square corners).
include <enclosure.scad>
$fn = 96;

module half() { translate([-200,-200,-80]) cube([400,200,600]); }
module cut(col) { color(col) difference() { rotate([0,0,-45]) children(); half(); } }

cut("gold")        rear_case();
cut("limegreen")   bezel();
cut("dimgray")     translate([0,0,rear_plane_z]) rotate([180,0,0]) rear_cover();
cut("red")         translate([0,0,glass_front_z]) cylinder(d=glass_od, h=glass_thickness);       // glass
cut("deepskyblue") translate([0,0,pcb_front_z]) linear_extrude(pcb_thickness) square([pcb_w,pcb_h],center=true); // PCB
cut("orange")      translate([0,0,glass_rear_z]) tube(glass_od, ledge_id, gasket_gap);           // glass-rim gasket
cut("orangered") for (p=mount_pts())                                                             // under-PCB damper pads
    translate([p[0],p[1],pcb_rear_z]) cylinder(d=standoff_od+2, h=gasket_under_pcb);
// rear board bolts (silver) driven from the back into the standoff inserts
cut("silver") for (p=mount_pts())
    translate([p[0],p[1],standoff_front_z+insert_depth]) rotate([180,0,0]) cylinder(d=screw_dia, h=standoff_len);

module lbl(x, z, s)
    color("black") translate([x, -0.7, z]) rotate([90,0,0]) linear_extrude(0.6)
        text(s, size=2.3, halign="center", valign="center");

lbl( 35, -2.0, "BEZEL");
lbl( 18,  3.0, "GLASS");
lbl( 18,  6.8, "PCB");
lbl( 44,  8.0, "PCB GASKET");
lbl( 40, 14.0, "GUSSET");
lbl( 53, 20.0, "REAR BOLT");

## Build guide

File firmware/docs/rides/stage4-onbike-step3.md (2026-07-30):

# Stage 4 — step (3): J1850 transceiver on the bike (stock cluster attached)

The last bench-free gate before removing the stock cluster. Goal: prove the
**fabricated transceiver board** (the `j1850_signal_board` v4 build —
[`../../../docs/schematics/j1850_signal_board.md`](../../../docs/schematics/j1850_signal_board.md))
behaves on the *real* J1850 bus with the stock
Instrument Module (IM) still connected — RX decodes the live bus, TX emits the
IM keep-alive set, and **no DTCs / warning lights** appear while both talk.

> This step needs the **transceiver only** — already built and self-sniff-green
> on the PCB (`stage4-tx-bench-log.md`). It does **not** need the 6 discrete
> divider zeners or the 12V->5V power board (those are separate features).

## What you need (all on hand)
- Transceiver board tapped to the bike **J1850 pin 7** (LGN/V data) + **pin 5**
  (BK/GN ground) via the proxy box / T-tap.
- **+12V to the transceiver** (Q2 emitter) — bike **switched 12V (pin 6)** or a
  bench PSU. Common ground with pin 5.
- **P4 on USB** (laptop / powerbank). No bike power board needed.
- Stock cluster stays fully connected.
- Optional but recommended: an **OBD/HD scan tool** to read DTCs directly
  (our own DTC read isn't built yet — Stage 5 brick, gated on this step).

## Firmware builds (local sdkconfig only — do NOT commit sdkconfig)

**3a — passive (TX off):** confirm the PCB RX decodes the live bus without
disturbing it.
```
CONFIG_VROD_J1850_SNIFFER=y
# CONFIG_VROD_J1850_TX is not set        # TX hardware idle: Rg holds Q1/Q2 off
CONFIG_VROD_J1850_RX_GPIO=20
CONFIG_VROD_PIN_WIGGLE_GPIO=-1
```

**3b — replay (TX on):** emit the IM keep-alive set on the live bus.
```
CONFIG_VROD_J1850_TX=y
CONFIG_VROD_J1850_TX_GPIO=24
CONFIG_VROD_J1850_SNIFFER=y
CONFIG_VROD_J1850_TX_BIKE_REPLAY=y      # emit keep-alives, NO self-sniff compare
# CONFIG_VROD_J1850_TX_SELFTEST is not set
CONFIG_VROD_J1850_GLITCH_NS=0
CONFIG_VROD_PIN_WIGGLE_GPIO=-1
# CONFIG_VROD_J1850 / RIDE_LOG off (focused build)
```
`VROD_J1850_TX_BIKE_REPLAY` runs the watchdog trigger test once at boot, then
emits the 4-frame keep-alive set at ~2 s cadence and logs each send
(`replay: frame N sent`). It deliberately has **no PASS/FAIL verdict** — judge
from the RX sniffer's per-frame CRC log + 10 s stats instead (a live bus carries
the stock IM's own traffic, which would flap any self-sniff compare).

Build/flash: `cd firmware && . $IDF_PATH/export.sh && idf.py build flash monitor`
(flash port: `/dev/cu.usbmodem5B5F0299541`).

## Procedure
1. **Ring-out + power**: pin 5/6 correct, transceiver +12V present, common
   ground, P4 on USB. Key OFF.
2. **3a passive**: flash the sniffer-only build, key ON.
   - PASS: sniffer logs stock-IM frames with **CRC OK**, low bad-CRC rate,
     no bus disturbance. This re-validates the PCB RX front end on the real bus.
3. **3b replay**: flash the replay build, key ON.
   - Expect `watchdog trigger test: PASS`, then `replay: frame N sent` (no
     `[TX FAULT]`), and the sniffer logging BOTH stock + our frames CRC-OK.
   - Watch the **stock cluster** for warning lights / MIL, and (if available)
     read DTCs with the scan tool.
4. **Record**: save the serial capture to `firmware/docs/captures/`.

## Abort / fail signals (stop, revert to stock via the proxy box)
- `[TX FAULT]` in the replay log (watchdog latched — TX disabled).
- Sniffer bad-CRC rate spikes, or the bus goes silent, after enabling TX.
- Any new warning light / DTC on the stock cluster while TX is active.

## Notes
- Emitting the IM keep-alives while the stock IM is also present means **two
  senders of the same messages** — that is the intended "both talk" test. J1850
  VPW has CSMA/CR arbitration; watch that it coexists without bus errors.
- **Do NOT remove the stock cluster in this step** — that (U1255 / TSSM security
  lockout) is step (4), one variable at a time.
- "No DTCs" is currently observed via the stock cluster / a scan tool. Firmware
  DTC read/clear is the next Stage-5 brick, unblocked once this step passes.

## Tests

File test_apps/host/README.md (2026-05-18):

# Host tests

Fast unit tests for the project's pure-logic modules. Build with the host
compiler (Apple clang / GCC), no ESP-IDF required.

## Run

```sh
cd test_apps/host
cmake -B build -S .
cmake --build build
ctest --test-dir build --output-on-failure
```

## With coverage

One-time setup (macOS):

```sh
brew install lcov
```

Then from `test_apps/host/`:

```sh
./coverage.sh
```

That builds with gcov instrumentation, runs ctest, extracts the
policy-scoped subset, prints a line / branch summary, generates HTML
under `build-cov/html/`, and opens it in your browser. Pass
`--no-open` to skip the auto-open.

If you'd rather drive it by hand:

```sh
# Build + run tests with instrumentation
cmake -B build-cov -S . -DCOVERAGE=ON -DCMAKE_BUILD_TYPE=Debug
cmake --build build-cov
ctest --test-dir build-cov --output-on-failure

# Capture and filter (macOS: --gcov-tool is needed because Apple's gcov is
# at /usr/bin/gcov; on Linux you can drop --gcov-tool)
lcov --rc branch_coverage=1 --gcov-tool /usr/bin/gcov \
     --capture --directory build-cov --output-file build-cov/coverage.info

lcov --rc branch_coverage=1 --gcov-tool /usr/bin/gcov \
     --extract build-cov/coverage.info \
       '*/main/simulator/gear_table.c' \
       '*/main/simulator/sim_math.c' \
       '*/main/display/format.c' \
       '*/main/display/units.c' \
       '*/main/display/widgets/smooth.c' \
       '*/main/settings/settings.c' \
       '*/main/vehicle/vehicle_data.c' \
     --output-file build-cov/coverage.tested.info

lcov --rc branch_coverage=1 --summary build-cov/coverage.tested.info
genhtml --branch-coverage build-cov/coverage.tested.info \
        --output-directory build-cov/html
open build-cov/html/index.html
```

CI runs the same flow on every push (`.github/workflows/host-tests.yml`)
and fails the build if the tested-by-policy modules drop below 100 % line
and 100 % branch coverage.

## Coverage policy

We claim **100 % coverage of tested-by-policy code**, not 100 % of the
repo. The set of files in scope is whatever ends up in `vrod_pure` in
`CMakeLists.txt`, and the same list lives in the CI `lcov --extract`
filter. The two must stay in sync.

Today that's:

| File | Why it's in scope |
|---|---|
| `main/simulator/gear_table.c` | Pure math: speed → (gear, RPM) |
| `main/simulator/sim_math.c` | Distance integrator, clock advance / split, fuel cycle state machine |
| `main/display/format.c` | Pure formatters: thousand-separated integer |
| `main/display/units.c` | Pure math: km/h ↔ mph and metre ↔ km/mi conversions |
| `main/display/widgets/smooth.c` | Pure math: single-pole step with snap |
| `main/settings/settings.c` | Defaults + validate for the persisted prefs struct |
| `main/vehicle/vehicle_data.c` | Mutex-guarded latest-value store. Tested with a FreeRTOS stub. |

### Behaviour-checked but not coverage-measured

The label-based widgets (`speed_display`, `gear_indicator`, `temp_display`,
`turn_signals`, `fuel_bar`, `clock_display`, `odometer_display`,
`trip_display`, `warning_lights`) link against an LVGL stub in
`test_widget_caches.c`. Those tests assert one property only — **the
skip-if-unchanged caches don't accidentally re-render**. They run on real
production widget code (no parallel mock implementation), but we don't
require 100 % line/branch coverage of the widgets themselves: the rest
of the widget code is LVGL setup glue, same flavour as the excluded
boot/screen wiring. If a future refactor breaks a cache, the regression
test fails; the widget files just don't appear in the coverage report.

To add a file: extract its pure-logic parts into a free-function module
with no LVGL / FreeRTOS / ESP-IDF deps, add it to `vrod_pure`, write the
test, update the lcov filter in the workflow, and add a row to the table
above.

Files **deliberately excluded** from the metric:

- `display/fonts/*.c` — generated by `lv_font_conv`. Testing them tests
  the generator.
- `display/widgets/tach_arc.c` — uses arc, scale, and image primitives.
  Stubbing that surface would roughly double the LVGL stub for marginal
  return; its cache is intentionally simple and any regression is
  trivially visible on the device.
- `display/boot_screen.c`, `display/ui_manager.c`, `display/screen_ride.c`,
  `main.c`, `simulator/sim_engine.c` (the task body), `vehicle/vehicle_data.c`
  — BSP / FreeRTOS / LVGL glue. Validated on hardware, not here.
- `assets/boot.gif`, `managed_components/**` — not source code we own.

This list is on purpose. Adding a widget creation path to it would be a
red flag — write a test for the *helper* the widget uses, not for the
glue around it.

## Adding a test

1. Drop a `tests/test_<name>.c` that defines `void RunTests(void)` and
   calls `RUN_TEST(case)` on each Unity test function.
2. Add `add_unit_test(test_<name>)` to `CMakeLists.txt`.
3. If the test exercises a new module, also add the module's `.c` to the
   `vrod_pure` library and to the lcov filter in the workflow.

## Why Unity, vendored

Unity (the test framework, not the game engine) is the same one ESP-IDF
uses for its own component tests. Vendoring it under `external/unity/`
keeps the host tests self-contained — no network at CI time, no version
skew between host and target. The three files are an unmodified copy
from `$IDF_PATH/components/unity/unity/src/`.

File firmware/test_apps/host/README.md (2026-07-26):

# Host tests

Fast unit tests for the project's pure-logic modules. Build with the host
compiler (Apple clang / GCC), no ESP-IDF required.

## Run

```sh
cd test_apps/host
cmake -B build -S .
cmake --build build
ctest --test-dir build --output-on-failure
```

## With coverage

One-time setup (macOS):

```sh
brew install lcov
```

Then from `test_apps/host/`:

```sh
./coverage.sh
```

That builds with gcov instrumentation, runs ctest, extracts the
policy-scoped subset, prints a line / branch summary, generates HTML
under `build-cov/html/`, and opens it in your browser. Pass
`--no-open` to skip the auto-open.

If you'd rather drive it by hand:

```sh
./coverage.sh            # builds with instrumentation, runs the suite,
                         # extracts the gated scope, opens the HTML report
```

The gated file list lives in `coverage.sh` (`SCOPED=`) and must stay in
sync with the CI workflow's `lcov --extract` list.

CI runs the same flow on every push (`.github/workflows/host-tests.yml`)
and fails the build if the tested-by-policy modules drop below 100 % line
and 100 % branch coverage.

## Coverage policy

We claim **100 % coverage of tested-by-policy code**, not 100 % of the
repo. The set of files in scope is whatever ends up in `vrod_pure` in
`CMakeLists.txt`, and the same list lives in the CI `lcov --extract`
filter. The two must stay in sync.

Today that's:

| File | Why it's in scope |
|---|---|
| `main/engine/simulator/drive_model.c` | Deterministic driving cycle → realistic `vehicle_data` (idle/accel/cruise/decel, gear-shaped RPM, temp warm-up). Drives the desktop simulator and the profile encoder. |
| `main/display/format.c` | Pure formatters: thousand-separated integer |
| `main/display/gesture.c` | Long-press + swipe state machine shared by firmware and sim |
| `main/display/units.c` | Pure math: km/h ↔ mph and metre ↔ km/mi conversions |
| `main/display/widgets/smooth.c` | Pure math: single-pole step with snap |
| `main/display/widgets/display_filter.c` | Damped-hysteresis anti-jitter filter: kills last-digit dither on a readout parked on a rounding edge (speed/temp) |
| `main/display/widgets/fuel_scale.c` | Fuel band grid quantization + gap-split segments |
| `main/display/widgets/rpm_scale.c` | RPM -> lit-segment count + redline segment for the shift-light bar |
| `main/connectivity/phone/phone_data.c` | Mutex-guarded latest-value store + notification queue. FreeRTOS-stubbed. |
| `main/connectivity/phone/phone_protocol.c` | Binary TLV parser for the companion-app BLE wire format |
| `main/connectivity/phone/telemetry_codec.c` | Cluster -> phone telemetry frame encoder (vehicle_data -> TLV) |
| `main/connectivity/phone/raw_sniff_codec.c` | Raw J1850 frame -> `0x50` TLV for phone-side guided capture (adaptive layer). |
| `main/contract/command.c` | Command-dispatch seam: register one handler, route typed commands (config / DTC) to it. Decouples the BLE bridge from engine internals (ADR 0001). |
| `main/display/settings/settings.c` | Defaults + validate for the persisted prefs struct |
| `main/engine/vehicle/vehicle_data.c` | Mutex-guarded latest-value store. Tested with a FreeRTOS stub. |
| `main/engine/vehicle/gear_calc.c` | Gear from the RPM:speed ratio (no gear sensor on the bike): match to the spec's exact overall ratios + boundary hysteresis. |
| `main/engine/vehicle/trip_meter.c` | Rolling 16-bit bus counter (odometer/fuel ticks) -> per-frame delta, wrap-safe + reset-clamp. |
| `main/engine/vehicle/odo_meter.c` | Odometer + dual-trip totals: add distance/fuel, reset a trip, set the odometer. Pure (odo_store owns NVS). |
| `main/connectivity/ble/ble_visibility.c` | Pure decision: `(has_bond, override) → adv_mode`. Stage 8. |
| `main/display/gps/nmea.c` | NMEA 0183 sentence framing + RMC parse (NEO-6M) → lat/lon/speed/heading |
| `main/display/gps/gps_source.c` | Mutex-guarded latest-fix store (module producer, map consumer) |
| `main/display/map/map_cells.c` | Cell-paging decision logic: which lat/lon cell a position is in (floor division), the working-set window, heading-ahead prefetch. Pure (cell manager owns the SD open/close). |
| `main/engine/j1850/j1850_vpw.c` | J1850 VPW symbol codec: pulse-width decoder + encoder + CRC-8/SAE-J1850. Round-trip tested. |
| `main/engine/j1850/j1850_parse.c` | J1850 message decoder: frame -> vehicle_data (RPM/temp/speed/turns/CEL/immobiliser), calibrated against real captures. Gear is not on the bus (see gear_calc). |
| `main/engine/j1850/dtc.c` | SAE J2012 DTC codec: text formatting (raw 2 bytes -> "U1255") + the HD J1850 read/clear request framing and the response-frame decode (ported from HarleyDroid). The `dtc_probe.c` task that keys them onto the bus is driver glue, out of the gate. |
| `main/engine/j1850/j1850_driver.c` | J1850 producer glue: decoded frame -> j1850_parse (+ gear_calc, + odometer/fuel tick accumulation) -> vehicle_data_set (running aggregate). |
| `main/engine/j1850/j1850_edge.c` | Toggling edge->level tracker (no pin read): toggle + recessive-idle re-sync anchor; a missed/spurious edge self-limits to one frame. |
| `main/engine/j1850/j1850_tx_logic.c` | J1850 TX pure logic: CRC frame build (round-tripped through encode→decode) + the watchdog dominant-length guard + on-air duration. |
| `main/engine/j1850/frame_inject.c` | USB-injector wire codec: frame ↔ `#F <hex>` line (CRC-validated on parse). End-to-end tested drive_model → encode → line → parse → driver. |
| `main/engine/j1850/ride_log_format.c` | Ride-log line/header formatting: frame -> one plain-text line (sec.ms, hex, CRC, IFR, decoded speed/temp/gear suffix), capture.py-compatible. |
| `main/engine/profile/bike_profile.c` | Profile-driven J1850 decoder: walks a bike profile's signal map -> vehicle_data. Reproduces `j1850_parse` byte-for-byte (cross-checked). The reference table `profile_vrscf_2009.c` is data (out of gate). |
| `main/engine/profile/profile_registry.c` | Profile identification: passive bus fingerprint, confidence-scored select vs the registry (auto-select or degraded mode), and the never-transmit listen-only gate. |

`main/engine/j1850/j1850_sniffer.c` (GPIO-ISR capture glue),
`main/engine/j1850/j1850_tx.c` (RMT/gptimer TX driver + watchdog), and
`main/engine/j1850/ride_log.c` (SD/FATFS mount + flush-task glue) are
FreeRTOS/driver glue and stay out of the gate.

### Widgets — also gated at 100 %

The widgets (`speed_display`, `gear_indicator`, `temp_display`,
`turn_signals`, `clock_display`, `odometer_display`, `trip_display`,
`warning_lights`, `fuel_arc`, `fuel_scale`, `notification_banner`,
`media_banner`, `now_playing_display`, `widget_util`,
plus the shared `sprite_raster.h` helpers) link against an LVGL stub in
`test_widget_caches.c` / `test_sprite_raster.c` and are **inside the
100 % line/branch gate** alongside the pure-logic modules. The stub fires
timers (`lv_timer_stub_fire_all`), synthesizes button clicks
(`lv_event_stub_click_all`), injects allocation failures
(`heap_caps_stub_fail_next`) and fakes layout heights
(`g_lv_stub_obj_height`), so the blink/click/alloc-failure paths run on
host too. The primary property remains: **the skip-if-unchanged caches
don't accidentally re-render**. If a future refactor breaks a cache, the regression
test fails; the widget files just don't appear in the coverage report.

To add a file: extract its pure-logic parts into a free-function module
with no LVGL / FreeRTOS / ESP-IDF deps, add it to `vrod_pure`, write the
test, update the lcov filter in the workflow, and add a row to the table
above.

Files **deliberately excluded** from the metric:

- `display/fonts/*.c` — generated by `lv_font_conv`. Testing them tests
  the generator.
- (none on the widget side — `tach_arc.c` joined the gate via the stub's
  canvas + block-glyph rasterizer and allocation-failure hooks; its baked
  OUTPUT is still verified visually in the simulator + on device, since a
  block glyph can't prove the real font rendering looks right.)
- `display/boot_screen.c`, `display/ui_manager.c`, `display/screen_ride.c`,
  `main.c`, `engine/simulator/sim_producer.c` (the task body)
  — BSP / FreeRTOS / LVGL glue. Validated on hardware, not here.
  (`engine/vehicle/vehicle_data.c` used to sit in this list but has been in
  scope since it gained the FreeRTOS-stub test — see the table above.)
- `assets/boot.gif`, `managed_components/**` — not source code we own.
- `display/map/map_tile.c` — the vector-map tile parser. Regression-tested
  (`test_map_tile`, compiled straight into the test, not `vrod_pure`) since it
  decodes untrusted embedded/SD bytes, but it allocates (per-tile buffers), so
  it can't reach the 100% branch bar the same way `connectivity/phone/icon_cache.c` can't.
  `display/map/map_render.c` (rasteriser) and `display/screen_map.c` (LVGL) are verified in
  the simulator + on device.
- `display/map/map_world.c` — the `world.hdr` manifest reader for the GPS-paged cell grid
  (`tools/maptiles/world.py` writes it). Same story as `map_tile.c`: regression-
  tested (`test_map_world`, compiled straight in) since it decodes untrusted SD
  bytes, but it allocates the present-cell set, so it is out of the branch gate.

This list is on purpose. Adding a widget creation path to it would be a
red flag — write a test for the *helper* the widget uses, not for the
glue around it.

## Adding a test

1. Drop a `tests/test_<name>.c` that defines `void RunTests(void)` and
   calls `RUN_TEST(case)` on each Unity test function.
2. Add `add_unit_test(test_<name>)` to `CMakeLists.txt`.
3. If the test exercises a new module, also add the module's `.c` to the
   `vrod_pure` library and to the lcov filter in the workflow.

## Why Unity, vendored

Unity (the test framework, not the game engine) is the same one ESP-IDF
uses for its own component tests. Vendoring it under `external/unity/`
keeps the host tests self-contained — no network at CI time, no version
skew between host and target. The three files are an unmodified copy
from `$IDF_PATH/components/unity/unity/src/`.

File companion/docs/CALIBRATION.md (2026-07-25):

# Calibration & fuel math

The two pure modules in `cal/` — no Android dependencies, JVM-unit-tested. They
turn the cluster's raw telemetry into calibrated speed and fuel figures.

## SpeedCalibrator — the speed divisor

The cluster reads a raw ECM count and shows `speed_mph = speed_raw / divisor`.
The relationship is **linear through the origin** (`raw = divisor · mph`), so the
best-fit divisor is the least-squares slope of paired (raw, GPS-mph) samples:

```
divisor = Σ(raw · mph) / Σ(mph²)
```

`SpeedCalibrator.compute(samples)`:
- **Filters** samples to `gpsMph ≥ 10` and `speedRaw > 0` (GPS is noisy near
  standstill and the ratio blows up); requires **≥ 5** usable samples.
- Rounds and **clamps to the firmware's accepted range** `[50, 400]` (mirrors
  `settings.h`), so it never pushes a value the cluster rejects.
- Returns `{ divisor, sampleCount, rmsErrorMph }` where the RMS error (fitted
  mph vs GPS mph) is the fit-quality readout in the wizard. Returns `null` if
  there aren't enough usable samples.

The Developer-screen wizard collects samples over BLE while riding and writes
the result back as a `CONFIG` message (→ cluster NVS).

> **Note on the current lock:** the firmware divisor is **188**, pinned on Ride 2
> (2026-07-09) by gear-ratio physics + a roadside-radar point — **not** by this
> GPS wizard, whose on-bike sampling bug was fixed only after that ride. So the
> GPS calibration is a **cross-check** on the locked 188, not the source of it.
> See `firmware/docs/rides/ride-2-findings.md`.

## FuelEconomy — economy + range

The cluster streams a per-trip fuel counter in raw injector **ticks** alongside
trip distance in metres. One fill-up calibrates how much fuel a tick represents:

```
mLPerTick = litersAdded · 1000 / ticks          (calibrateMlPerTick)
```

Then any `(distance, ticks)` window gives economy:

```
liters   = ticks · mLPerTick / 1000
km/L     = km / liters
L/100km  = liters / km · 100
mpg (US) = miles / (liters / 3.785411784)
```

Constants: **tank = 18.9 L** (VRSCF, 5.0 US gal); the sender's coarse level is
`0..6` bars. Range-to-empty comes from the level bars × tank fraction and the
running economy. All inputs are validated (non-positive distance/ticks/mLPerTick
return `null`).

Calibrated `mL/tick ≈ 0.309` from the Ride-2 fill-up (supersedes the `0.000040`
placeholder). This is the **fuel-computer** path — likely more stable than the
VRSCF's erratic ultrasonic sender, and it needs no discrete tap (that's a
Phase-3 addition for an absolute gauge + low-fuel telltale).

## Ground truth

Both modules mirror the firmware's pure logic and are cross-checked against the
same fixtures: `firmware/main/engine/vehicle/gear_calc.c` / `settings.h` bounds for the
divisor, and the fuel constants in the firmware's fuel-economy tests. Keep them
in lock-step.

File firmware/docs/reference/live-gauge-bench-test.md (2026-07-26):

# Live-gauge bench test (real J1850 on the display, stationary)

Verify the full chain **bus -> decode -> display** at the bike before any
ride: key-on / engine running but **stationary**, ESP on **laptop USB power**
(no bike power, no ride-log, no microSD). RX front end tapped to the bike's
J1850 pin **7 (signal)** + pin **5 (ground)**, same as the sniffer, into the
divider node on **GPIO 20**.

## The one flag that matters

**`CONFIG_VROD_J1850=y`** makes the J1850 decode the live `vehicle_data`
producer. The firmware has no compiled-in simulator (the on-P4 sim engine was
removed in the "single prod build" rework); the sniffer's decoded frames flow
`j1850_driver -> vehicle_data_set`, and the gauge UI (which always renders from
`vehicle_data`) shows real bus values. It depends on
`CONFIG_VROD_J1850_SNIFFER=y` (the RX capture/decode). For a bench with **no
bus at all**, drive the same path from a Mac - see the USB-injector check
below.

## Build config (menuconfig -> "V-Rod cluster")

| Option | Set | Why |
|---|---|---|
| `VROD_J1850_SNIFFER` | **y** | RX capture + VPW decode |
| `VROD_J1850` | **y** | **the live producer** -> vehicle_data (suppresses the sim) |
| `VROD_J1850_RX_GPIO` | 20 | divider node (default) |
| `VROD_INCLUDE_SIM_ENGINE` | n | sim not needed (it is gated off anyway; n keeps the build clean) |
| `VROD_RIDE_LOG` | n | no SD logging / no card for this test |
| `VROD_J1850_TOGGLE_ISR` | n | keep the shipping pin-read RX ISR |
| `VROD_J1850_TX` | n | RX-only, cannot disturb the bus / stock cluster |
| `VROD_J1850_GLITCH_NS` | 0 | filter off (the tuned default; see the capture notes) |
| `VROD_J1850_ADC_GPIO` | -1 | no amplitude probe |

Build + flash + watch the serial log alongside the gauge:

```sh
cd firmware && . $IDF_PATH/export.sh
idf.py build
idf.py -p /dev/cu.usbmodem5B5F0299541 flash monitor
```

The **ride/gauge screen is the boot screen**; the BENCH diagnostics screen is
still reachable via Settings (sniffer is on) if you want raw frame counts.

## What is LIVE vs not (be honest about the bus)

Decoded from the bus and driven onto the gauge:

| Field | Frame | On screen |
|---|---|---|
| **RPM** | `28 1B 10 02` | tach arc — moves with throttle |
| **Temperature** | `A8 49 10 10` | temp dial — climbs as the engine warms (**raw / provisional scaling**; the point is it *moves*, calibration is later) |
| **Turn L / R / hazard** | `48 DA 40 39` | turn arrows |
| **Neutral** | gear frame `A8 3B 10 03`, `00`=N | gear reads **"N"** (orange) |
| **Check-engine** | `68 88 10` | engine lamp (off unless a fault is set) |

Expected NOT to move in this test:
- **Speed = 0** and **gears 1-6 absent** — stationary, no motion. Correct.
- **High/low beam — NOT on the J1850 bus.** They are discrete 12 V wires
  read locally by the IM (pin 2 White = high beam), confirmed off-bus in the
  2026-07-04 capture; `j1850_parse` does not decode them, so the beam lamp
  will **not** follow the switch here. That is a Phase 3 discrete-line tap,
  not a bug in this build.
- **Fuel gauge, oil, ABS, battery, immobiliser** — also not bus-decoded in
  Stage 3; they sit at their boot/zero state.

## Stationary checklist

1. **Key on, engine off.** Gauge shows **N** (neutral), RPM 0, speed 0. In
   `idf.py monitor` you should see the sniffer frame log + periodic
   `speed:` / `temp:` / `gear:` hint lines — confirms the bus is alive and
   frames decode with good CRC.
2. **Rev the engine.** The **RPM** needle tracks the throttle on the tach.
3. **Let it warm.** The **temperature** reading climbs (raw/provisional
   number — just confirm it rises, don't trust the absolute value yet).
4. **Turn signals.** Left blinker -> left arrow; right -> right; hazards ->
   both.
5. **High beam (expected no-op).** The on-screen beam lamp will **not**
   change — off-bus. Confirm via serial that no beam-related frame appears;
   that is the expected result, and the reason the discrete tap is Phase 3.

Success = RPM, temperature, turn signals, and the neutral "N" all follow the
bike live off the J1850 bus. That proves bus -> decode -> display end to end
before committing to a ride.

## Notes

- **RX-only, safe:** no TX is compiled in, so this build cannot put anything
  on the bus or upset the stock cluster.
- The **sniffer capture build** (same `VROD_J1850_SNIFFER=y` but without the
  producer / with the ride log) stays available separately — this is the
  gauge/live variant, driven by the single `VROD_J1850` producer flag.
- `j1850_vpw.c` and the RX capture path are untouched by this build.

## USB-injector check (no bus needed) — UNVERIFIED on hardware

For UI work away from the bike, drive the gauge from the Mac instead of a live
bus (see `usb-frame-injector.md` for the full design). This exercises the
always-on `usb_inject.c` reader, which has **not yet been confirmed on
hardware** — run this once to validate it, then treat it as the standard bench
loop.

1. Build the generator: `cd test_apps/host && cmake -B build -S . &&
   cmake --build build --target frame_inject_gen`.
2. Flash a normal prod build (`CONFIG_VROD_J1850=y`; the injector is always
   compiled in). No bus, laptop USB power.
3. **Close `idf.py monitor`** (it holds the port), then
   `cd tools && ./inject_stream.py`.
4. **Expect:** the dials run the drive_model cycle — RPM sawtooths through the
   gears, speed ramps 0→60→0, temperature warms 20→90, left blinker in the
   decel window. This is the same cycle the desktop simulator shows.
5. **If the console fights the shared USB-Serial-JTAG peripheral** (no frames
   land, or logging breaks): note it here; the fallback is a dedicated UART or
   gating the reader. The host-tested codec/generator are unaffected.

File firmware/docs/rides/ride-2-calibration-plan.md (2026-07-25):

# Ride 2 plan — GPS speed calibration + live-stack validation

Ride 1 (`ride-1-findings.md`) proved the speed frame `48 29 10 02` is
km/h-native and pinned the raw->mph divisor at a **provisional 195** (physics
fit ~188, stock-speedo peak ~200, naive ~206 — all within ~5 %). Ride 2 locks
that number with a GPS reference and validates the full live stack end to end
on the Zeppl companion:

```
J1850 bus -> j1850_driver decode -> vehicle_data -> gauge
                                              \-> BLE telemetry -> phone
phone GPS speed + speed_raw -> SpeedCalibrator -> divisor -> cluster -> NVS
```

This is the payoff of Stage 5 Bricks 1-3. Brick 4 (fuel economy) needs a
fill-up and is a separate follow-up (Part D).

## Preconditions

**Firmware — production build** (the currently-flashed config; confirm before
riding):

| Option | Set | Why |
|---|---|---|
| `VROD_J1850_SNIFFER` | y | RX capture + VPW decode |
| `VROD_J1850` | y | live producer -> vehicle_data (suppresses the sim) |
| `VROD_J1850_BENCH_SPEED` | **n** | **must be off** — it fabricates speed_raw=19500 |
| `VROD_J1850_RX_GPIO` | 20 | divider node |
| `VROD_J1850_TX` | n | RX-only; cannot disturb the stock cluster / bus |
| `VROD_RIDE_LOG` | y | log raw counts to microSD for an offline cross-check |
| `VROD_RIDE_LOG_DUMP` | **n** | leave off — dumping a full log blocks boot ~1 min |

Sanity-check on serial before leaving: **no `j1850_bench` lines**, and
`j1850: stats` climbing with frames once the RX tap is on the bus.

**Rig:**
- RX front end tapped to J1850 **pin 7 (signal) + pin 5 (ground)** into the
  GPIO 20 divider node (same as the sniffer).
- Bike 5 V power (`bike-power-injection.md`) or a powerbank on the header 5 V.
- microSD inserted (ride log).
- Phone: **Zeppl** app installed + bonded to the cluster; a clear-sky start so
  GPS locks quickly.
- **A pillion or an assistant to operate the phone** — the wizard needs taps
  while moving. Never interact handheld while riding; do it stopped or hand it
  to a passenger.

## Part A — stationary at the bike (gate before moving)

Reuse `live-gauge-bench-test.md`. Key-on / engine running, **stationary**, and
confirm the same values on the **gauge and the phone** (Zeppl Ride screen +
Dev > Live telemetry):

- Rev -> RPM tracks on the tach and phone `rpm`.
- Warm up -> temperature climbs (`raw - 40` °C).
- Turn signals -> arrows. Neutral -> **N**.
- **Speed 0** (stationary) — correct. `speed_raw` should read 0.

If the phone shows live RPM/temp, the decode -> display -> BLE telemetry chain
(Brick 1) is proven and it's safe to ride.

## Part B — GPS calibration ride (the divisor lock)

1. **Unlock dev mode:** Cluster tab -> tap your cluster -> **Firmware** -> tap
   *Version* seven times.
2. **Dev tab -> your connected cluster -> Speed calibration -> Start.** Grant
   location when prompted.
3. **Ride and vary speed** across roughly **15-55 mph (25-90 km/h)**. Hold a
   few steady speeds for several seconds each; a spread of points fits a better
   slope than one cruise speed. The wizard samples `(GPS mph, speed_raw)` once a
   second, drops sub-10 mph noise, and needs >=5 usable samples.
4. Watch the card: **Solved divisor** + **Fit error (RMS mph)** appear once
   enough samples land. Aim for **RMS < ~2 mph** and **>=8-10 samples** across
   the range.
5. **Finish -> Apply to cluster.** This writes the divisor over BLE; the cluster
   applies it live (`speed_mph = speed_raw / divisor`) and persists it to NVS.
6. **Sanity:** the solved divisor should land ~**180-200** (physics ~188, stock
   ~200). If it's wildly outside that, the samples were noisy — Redo with
   steadier holds and a clearer GPS view.

## Part C — cross-checks (confidence, not required to ride)

- **Reboot persistence (Brick 3):** power-cycle the cluster, reconnect, confirm
  `speed_mph` still tracks GPS at the new divisor (not back to 195). Validated
  on the bench; re-confirm on the real value.
- **Offline re-derivation:** the ride log stores raw counts (`speed_raw=`), so
  the divisor is independently re-derivable from the capture
  (`tools/ride_log_pull.py` + `tools/j1850_report.py`). Compare it to the
  wizard's number — they should agree within a couple of percent.
- **Stock speedo** (if the proxy box keeps it alive): eyeball-compare at a
  couple of held speeds.

## Part D — the rest of the live stack

- **Gear derivation:** N at a stop; 1-6 should settle sensibly under way
  (`gear = argmin |rpm/speed - ratio|` over the exact overall ratios). No
  sensor on this bike, so it's inferred — spot-check it feels right per gear.
- **Fuel economy (Brick 4) — start the baseline at the fuel stop.** The
  mL/tick calibration needs *two* fills bracketing a known burned amount, so a
  single stop can only **start** it. At this ride's fuel stop: **fill the tank
  and reset Trip 1** (cluster Trip settings) at the pump — that zeroes the fuel
  tick counter for the tank you're about to burn. Ride the tank down; at the
  **next** fill-up, open the Zeppl Ride screen's **Fuel** card, enter the litres
  added, and Save — that solves mL/tick (litres / Trip-1 ticks) and unlocks
  trip economy (mpg / L/100km) + range-to-empty. Until then the Fuel card shows
  the level bar and prompts to calibrate.

## Safety rails

- Phone mounted or pillion-operated; **no handheld interaction underway**.
- Firmware is **RX-only** (no TX compiled) — it physically cannot put anything
  on the bus or upset the stock cluster.
- **BLE drops** (occasional `status=19` peer-terminate / `status=8` supervision
  timeout) auto-recover in <11 s. A drop mid-ride does **not** lose the divisor
  once Applied — it's in NVS. If the link is down when you hit Apply, reconnect
  and re-send.

## Success criteria

- Solved divisor Applied and **persisted** (survives a reboot).
- `speed_mph` within a few percent of GPS across the 15-55 mph range.
- RPM, temperature, turn signals, N, and gear all live and sane on **both** the
  gauge and the phone.

## Post-ride

1. Record results in **`firmware/docs/rides/ride-2-findings.md`**: solved divisor,
   RMS, sample count, cross-check deltas (wizard vs offline re-derivation vs
   stock).
2. **Promote the locked divisor** for fresh flashes (this unit's NVS already
   holds it): update `SETTINGS_SPEED_DIVISOR_DEFAULT` in
   `main/display/settings/settings.h` and `J1850_SPEED_DIVISOR` in
   `main/engine/j1850/j1850_parse.h`, and replace the "provisional 195" notes in
   `ride-1-findings.md` and the Phase 2 plan with the locked value.
3. Turn `VROD_RIDE_LOG_DUMP` on only to pull the capture, then back **off**
   (it blocks boot ~1 min).

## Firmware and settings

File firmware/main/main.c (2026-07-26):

#include "bsp/esp-bsp.h"
#include "bsp/display.h"
#include "esp_log.h"
#include "freertos/FreeRTOS.h"
#include "freertos/task.h"
#include "esp_flash_chips/spi_flash_chip_driver.h"
#include "esp_flash_chips/spi_flash_chip_generic.h"
#include "lvgl.h"

#include "ble_peripheral.h"
#include "command_handler.h"
#include "boot_screen.h"
#include "emoji_font.h"
#include "phone_data.h"
#include "icon_cache.h"
#include "telemetry_publisher.h"
#include "screen_pairing.h"
#include "vehicle_data.h"
#include "gps_source.h"
#if CONFIG_VROD_GPS_UART
#include "gps_uart.h"
#endif
#if CONFIG_VROD_J1850_SNIFFER
#include "j1850_sniffer.h"
#include "raw_sniff.h"
#endif
#if CONFIG_VROD_RIDE_LOG
#include "ride_log.h"
#endif
#if CONFIG_VROD_J1850
#include "j1850_driver.h"
#include "j1850_bench_feed.h"
#include "usb_inject.h"
#include "odo_store.h"
#endif
#if defined(CONFIG_VROD_J1850_ADC_GPIO) && CONFIG_VROD_J1850_ADC_GPIO >= 0
#include "j1850_adc_probe.h"
#endif
#if CONFIG_VROD_J1850_TX
#include "j1850_tx.h"
#if CONFIG_VROD_J1850_DTC_PROBE
#include "dtc_probe.h"
#endif
#if CONFIG_VROD_J1850_DTC
#include "dtc_service.h"
#endif
#endif
#if CONFIG_VROD_PIN_WIGGLE_GPIO >= 0
#include "pin_wiggle.h"
#endif
#if CONFIG_VROD_ADC_REPRO
void adc_repro_touch(void);
#endif
#include "settings_store.h"
#include "sound.h"

// CONFIG_SPI_FLASH_OVERRIDE_CHIP_DRIVER_LIST=y disables IDF's built-in
// chip-driver registration table so the vendor-specific drivers
// (winbond/mxic/issi/boya/th) drop out of the IRAM placement competition
// on P4 < v3 silicon. Generic driver accepts any chip ID and is enough for
// the Waveshare module's flash. See docs/ble-bringup-bisect.md.
const spi_flash_chip_t *default_registered_chips[] = {
    &esp_flash_chip_generic,
    NULL,
};

static const char *TAG = "vrod_gauge";

void app_main(void)
{
    bsp_display_cfg_t cfg = {
        .lv_adapter_cfg = ESP_LV_ADAPTER_DEFAULT_CONFIG(),
        .rotation = ESP_LV_ADAPTER_ROTATE_0,
        .tear_avoid_mode = ESP_LV_ADAPTER_TEAR_AVOID_MODE_TRIPLE_PARTIAL,
        .touch_flags = { .swap_xy = 0, .mirror_x = 0, .mirror_y = 0 },
    };
    bsp_display_start_with_config(&cfg);
    settings_store_init();
    // FreeType + memfs are up by the time bsp_display_start has called
    // lv_init. Attach the emoji fallback before any widgets get created
    // so the very first frame can render emoji correctly.
    emoji_font_init();

    // Data sources used by ui_manager_show_ride() at boot-hand-off must
    // exist before boot_screen_show(); otherwise a GIF decode failure
    // would fire the safety timer's fast-path into the ride screen
    // against an uninitialised vehicle_data store.
    vehicle_data_init();
    phone_data_init();
    gps_source_init();  // shared GPS fix store (module producer, map consumer)
    icon_cache_init();  // PSRAM buffers for streamed app-notification icons
#if CONFIG_VROD_J1850
    // Producer: the sniffer's decode feeds vehicle_data via the driver.
    // Init before the sniffer task so it can consume frames immediately.
    j1850_driver_init();
    // Log the persisted divisor so a wrong speedo is diagnosable from the boot
    // console (a stale bench value once shipped a whole ride reading ~45% high).
    ESP_LOGI(TAG, "speed divisor (NVS) = %u", settings_store_current()->speed_divisor);
#if CONFIG_VROD_RESET_CALIBRATION
    if (settings_store_current()->speed_divisor != SETTINGS_SPEED_DIVISOR_DEFAULT) {
        settings_t reset    = *settings_store_current();
        uint16_t   was      = reset.speed_divisor;
        reset.speed_divisor = SETTINGS_SPEED_DIVISOR_DEFAULT;
        settings_store_apply(&reset);
        ESP_LOGW(TAG, "RESET calibration: speed divisor %u -> %u", was, reset.speed_divisor);
    }
#endif
    // Restore the GPS-calibrated speed divisor persisted in settings.
    j1850_driver_set_speed_divisor(settings_store_current()->speed_divisor);
    // Restore the persisted odometer/trips into the driver, then keep them
    // saved (periodic + on user reset). Must follow driver_init (it seeds it).
    odo_store_init();
#if CONFIG_VROD_J1850_BENCH_SPEED
    j1850_bench_feed_start();
#endif
    // Always-on USB frame injector: a Mac tool can stream a drive_model cycle
    // over USB to drive the gauge on a bench with no live bus. Inert otherwise.
    usb_inject_start();
#endif
#if CONFIG_VROD_RIDE_LOG
    // Mount the SD sink + start its flush task before frames arrive; a missing
    // card is non-fatal (state NO_CARD, start retries the mount).
    ride_log_init();
#endif
#if CONFIG_VROD_J1850_SNIFFER
    // Read-only capture; also feeds the producer when CONFIG_VROD_J1850.
    j1850_sniffer_start();
#if CONFIG_VROD_J1850_RAW_SNIFF
    raw_sniff_start();  // forward every frame to the phone (adaptive-layer capture)
#endif
#endif
#if CONFIG_VROD_GPS_UART
    gps_uart_start();  // NMEA reader -> gps_source (map prefers it over phone GPS)
#endif
#if defined(CONFIG_VROD_J1850_ADC_GPIO) && CONFIG_VROD_J1850_ADC_GPIO >= 0
    j1850_adc_probe_start();
#endif
#if CONFIG_VROD_J1850_TX
    j1850_tx_init();
#if CONFIG_VROD_J1850_DTC
    dtc_service_start();  // phone-triggered read/clear (runs with the gauge)
#endif
#if CONFIG_VROD_J1850_DTC_PROBE
    dtc_probe_start();
#elif CONFIG_VROD_J1850_TX_BIKE_REPLAY
    j1850_tx_bike_replay_start();
#elif CONFIG_VROD_J1850_TX_SELFTEST
    j1850_tx_selftest_start();
#endif
#endif
#if CONFIG_VROD_PIN_WIGGLE_GPIO >= 0
    pin_wiggle_start();
#endif
#if CONFIG_VROD_ADC_REPRO
    adc_repro_touch();
#endif

    // Backlight strategy. bsp_display_brightness_init() leaves the LEDC
    // channel at duty 0 (backlight off). bsp_display_brightness_set() and
    // bsp_display_backlight_on() are the *same* function — the latter just
    // calls the former with 100. Any brightness change lights the panel.
    // A naive "set brightness early, then init, then boot screen" sequence
    // flashed white at the user's saved duty: the framebuffer still held
    // PSRAM init garbage (≈ 0xFFFF / white in RGB565) when the panel lit
    // up. Instead: keep duty at 0 through init, paint black through all
    // three triple-partial framebuffers, then put the GIF on top, then
    // light the panel in one step at the saved brightness.
    bsp_display_lock(-1);
    lv_obj_t *scr = lv_screen_active();
    lv_obj_set_style_bg_color(scr, lv_color_black(), 0);
    lv_obj_set_style_bg_opa(scr, LV_OPA_COVER, 0);
    for (int i = 0; i < 3; i++) {
        lv_obj_invalidate(scr);
        lv_refr_now(NULL);
        bsp_display_unlock();
        vTaskDelay(pdMS_TO_TICKS(20));
        bsp_display_lock(-1);
    }
    boot_screen_show();
    lv_refr_now(NULL);
    bsp_display_unlock();
    vTaskDelay(pdMS_TO_TICKS(20));
    bsp_display_brightness_set(settings_store_current()->brightness);

    // Non-display init continues in parallel with the boot animation
    // (LVGL task is pinned to core 1, the calls below run on core 0).
    sound_init();
    sound_set_volume(settings_store_current()->volume);
    sound_set_enabled(settings_store_current()->sound_enabled);
    // Register the pairing-prompt UI hook before bringing up the radio,
    // so a paired phone reconnecting at boot doesn't briefly hit a
    // null callback during the SM exchange.
    ble_peripheral_pair_set_callback(screen_pairing_show);
    command_handler_init();  // register the engine-side handler before commands can arrive
    ble_peripheral_init();
    telemetry_publisher_start();

    // The map is no longer started here: it loads lazily the first time the map
    // layout is shown (ui_manager_show_home), so a classic setting never mounts
    // the SD or builds the tileset. The boot hand-off always follows this point
    // (ble is up), so the lazy load keeps nimble's RAM ordering.
    ESP_LOGI(TAG, "boot complete");
    // app_main can return — all the real work runs in the FreeRTOS tasks
    // we spawned (ui_update_task, event_watcher_task, j1850 producer,
    // NimBLE host, LVGL render). The previous busy-log loop here would
    // also block any future TWDT IDLE-task feed on core 0.
}

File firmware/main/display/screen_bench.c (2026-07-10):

#include "screen_bench.h"
#include "j1850_sniffer.h"
#include "theme.h"
#include "ui_manager.h"
#include <stdio.h>
#if CONFIG_VROD_J1850_GLITCH_SWEEP
#include "esp_timer.h"
#endif
#if CONFIG_VROD_J1850_ADC_GPIO >= 0
#include "j1850_adc_probe.h"
#endif
#if CONFIG_VROD_RIDE_LOG
#include "ride_log.h"
#endif

LV_FONT_DECLARE(jbm_bold_45);
LV_FONT_DECLARE(jbm_bold_33);
LV_FONT_DECLARE(jbm_bold_26);

// Same bezel-clearance geometry as the settings screen.
#define ROW_W 540

// node B (RX divider output) → bus voltage: bus_mv = node_B_mv * 147/47
// (10k/4.7k inverse). The amplitude probe already applies this for its
// serial log; the screen re-applies it for display.
#define BUS_FROM_PIN_MV(mv) ((mv) * 147 / 47)

#define REFRESH_MS 500

static lv_obj_t *s_scr;
static lv_obj_t *s_amp_value;
static lv_obj_t *s_amp_lo;
static lv_obj_t *s_line_value;
static lv_obj_t *s_frames_value;
static lv_obj_t *s_last_value;
#if CONFIG_VROD_J1850_GLITCH_SWEEP
static lv_obj_t *s_sweep_value;
#endif
#if CONFIG_VROD_RIDE_LOG
static lv_obj_t        *s_ridelog_value;
static lv_obj_t        *s_rec_lbl;
static lv_obj_t        *s_clr_lbl;
static ride_log_state_t s_shown_rl_state  = -1;
static uint32_t         s_shown_rl_frames = UINT32_MAX;
static uint32_t         s_shown_rl_drop   = UINT32_MAX;
#endif

// Skip-if-unchanged caches (house rule: setters never re-render for
// the same value).
static int      s_shown_amp_max = -2;
static bool     s_shown_level;
static uint32_t s_shown_edges  = UINT32_MAX;
static uint32_t s_shown_frames = UINT32_MAX;
static uint32_t s_shown_crcbad;
static uint32_t s_shown_ovr;

static lv_obj_t *make_row(lv_obj_t *parent, int32_t height, int32_t y)
{
    lv_obj_t *row = lv_obj_create(parent);
    lv_obj_set_size(row, ROW_W, height);
    lv_obj_align(row, LV_ALIGN_TOP_MID, 0, y);
    lv_obj_set_style_bg_color(row, lv_color_hex(0x1A1A1A), 0);
    lv_obj_set_style_border_color(row, lv_color_hex(VROD_TEXT_DIM), 0);
    lv_obj_set_style_border_width(row, 1, 0);
    lv_obj_set_style_radius(row, 12, 0);
    lv_obj_set_style_pad_all(row, 14, 0);
    lv_obj_remove_flag(row, LV_OBJ_FLAG_SCROLLABLE);
    return row;
}

static lv_obj_t *make_caption(lv_obj_t *row, const char *text, lv_align_t align, uint32_t color)
{
    lv_obj_t *lbl = lv_label_create(row);
    lv_label_set_text(lbl, text);
    lv_obj_set_style_text_color(lbl, lv_color_hex(color), 0);
    lv_obj_set_style_text_font(lbl, &jbm_bold_33, 0);
    lv_obj_align(lbl, align, 0, 0);
    return lbl;
}

static void refresh_cb(lv_timer_t *t)
{
    (void)t;
    // The screen object outlives visibility; skip work while hidden.
    if (lv_screen_active() != s_scr)
        return;

    char buf[48];

#if CONFIG_VROD_J1850_ADC_GPIO >= 0
    // Bus amplitude from the dedicated ADC probe (GPIO 22, second wire
    // off node B). On this active-low bus, MAX = idle resting (HIGH)
    // level — the number Stage 4 TX must overcome. MIN reads the driven
    // (LOW) level only if a sample landed inside a pulse.
    int amp_max, amp_min;
    if (j1850_adc_probe_get(&amp_max, &amp_min) && amp_max != s_shown_amp_max) {
        s_shown_amp_max = amp_max;
        int hi          = BUS_FROM_PIN_MV(amp_max);
        int lo          = BUS_FROM_PIN_MV(amp_min);
        snprintf(buf, sizeof(buf), "%d.%02dV", hi / 1000, (hi % 1000) / 10);
        lv_label_set_text(s_amp_value, buf);
        snprintf(buf, sizeof(buf), "lo %d.%02dV", lo / 1000, (lo % 1000) / 10);
        lv_label_set_text(s_amp_lo, buf);
    }
#endif

    j1850_sniffer_stats_t st;
    j1850_sniffer_get_stats(&st);

#if CONFIG_VROD_J1850_GLITCH_SWEEP
    if (st.sweep_active) {
        int rem = (int)((st.sweep_deadline_us - esp_timer_get_time()) / 1000000);
        if (rem < 0)
            rem = 0;
        snprintf(buf, sizeof(buf), "SWEEP %luns  %ds  p%lu", (unsigned long)st.sweep_ns, rem,
                 (unsigned long)st.sweep_pass);
        lv_label_set_text(s_sweep_value, buf);
    }
#endif

    if (st.pin_level != s_shown_level || st.edges_last_period != s_shown_edges) {
        s_shown_level = st.pin_level;
        s_shown_edges = st.edges_last_period;
        snprintf(buf, sizeof(buf), "%s  %lu edges", st.pin_level ? "HIGH" : "LOW",
                 (unsigned long)st.edges_last_period);
        lv_label_set_text(s_line_value, buf);
        lv_obj_set_style_text_color(s_line_value,
                                    lv_color_hex(st.pin_level ? VROD_ORANGE : VROD_TEXT_DIM), 0);
    }

    if (st.frames != s_shown_frames || st.crc_bad != s_shown_crcbad || st.overruns != s_shown_ovr) {
        s_shown_crcbad = st.crc_bad;
        s_shown_ovr    = st.overruns;
        snprintf(buf, sizeof(buf), "%lu  bad %lu  ovr %lu", (unsigned long)st.frames,
                 (unsigned long)st.crc_bad, (unsigned long)st.overruns);
        lv_label_set_text(s_frames_value, buf);

        // New frame arrived → refresh the hex line too.
        if (st.frames != s_shown_frames && st.last_len > 0) {
            char hex[48];
            int  pos = 0;
            for (size_t i = 0; i < st.last_len && pos < (int)sizeof(hex) - 4; i++) {
                pos += snprintf(hex + pos, sizeof(hex) - (size_t)pos, "%02X ", st.last_frame[i]);
            }
            lv_label_set_text(s_last_value, hex);
            lv_obj_set_style_text_color(s_last_value,
                                        lv_color_hex(st.last_crc_ok ? VROD_TEXT : VROD_RED), 0);
        }
        s_shown_frames = st.frames;
    }

#if CONFIG_VROD_RIDE_LOG
    ride_log_stats_t rl;
    ride_log_get_stats(&rl);
    if (rl.state != s_shown_rl_state || rl.frames != s_shown_rl_frames ||
        rl.dropped != s_shown_rl_drop) {
        s_shown_rl_state  = rl.state;
        s_shown_rl_frames = rl.frames;
        s_shown_rl_drop   = rl.dropped;
        const char *name;
        uint32_t    col;
        switch (rl.state) {
        case RIDE_LOG_RECORDING:
            name = "REC";
            col  = VROD_RED;
            break;
        case RIDE_LOG_IDLE:
            name = "IDLE";
            col  = VROD_TEXT;
            break;
        case RIDE_LOG_NO_CARD:
            name = "NO CARD";
            col  = VROD_TEXT_DIM;
            break;
        case RIDE_LOG_ERROR:
            name = "ERROR";
            col  = VROD_RED;
            break;
        default:
            name = "--";
            col  = VROD_TEXT_DIM;
            break;
        }
        if (rl.state == RIDE_LOG_RECORDING || rl.state == RIDE_LOG_IDLE) {
            snprintf(buf, sizeof(buf), "%s  %luf d%lu  %lu/%luMB", name, (unsigned long)rl.frames,
                     (unsigned long)rl.dropped, (unsigned long)rl.mb_used,
                     (unsigned long)rl.mb_total);
        } else {
            snprintf(buf, sizeof(buf), "%s", name);
        }
        lv_label_set_text(s_ridelog_value, buf);
        lv_obj_set_style_text_color(s_ridelog_value, lv_color_hex(col), 0);
        lv_label_set_text(s_rec_lbl, rl.state == RIDE_LOG_RECORDING ? "STOP" : "REC");
    }
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

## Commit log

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2026-05-15 feat: full ride-screen UI with simulated cluster data
    Phase 2: working ride dashboard against a synthetic driving cycle.
    Tach arc with glow tail + smooth-zoom labels + breathing jitter;
    speed, gear, fuel bar, turn signals, temp; warning-lamp chevrons
    flanking the speed digits (oil, engine, battery on the left; ABS,
    rotating low/high beam, immobiliser on the right); clock + odometer
    sharing one slot above the fuel bar, rotating every 5 s. Replaces
    the bring-up speedo_arc widget. Colour palette extracted to theme.h.
2026-05-18 test: host unit tests with 100% pure-logic coverage + CI
    Adds a CMake-based host test app under test_apps/host/ that compiles
    the project's pure-logic modules with the system clang/gcc — no
    ESP-IDF needed — and runs them under Unity. Six suites cover:
    - gear_table: gear selection across every speed boundary
    - sim_math: distance integrator, 24-hour clock wrap, fuel cycle
    - format: thousand-grouped + tenth-km formatters, truncation
    - smooth: single-pole step with snap, monotonic convergence
    - vehicle_data: mutex-guarded latest-value store (FreeRTOS stub
    drives both happy-path and timeout branches)
    - widget_caches: one cache-regr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
2026-05-20 feat: companion ble central — scan, connect, route bytes over GATT
    Adds the BLE-central half of the phone-bridge. Foreground service
    (FOREGROUND_SERVICE_CONNECTED_DEVICE) hosts a BleClient that scans for
    the cluster's SERVICE_UUID, connects, requests a 247-byte MTU, and
    swaps itself into OutboundSink.send for the duration — so the
    NotificationListener and MediaWatcher don't need to know there's a
    radio now. Disconnecting restores the prior logcat sink.
    - Protocol.kt exposes the GATT UUIDs (NUS-shaped, mirror of
    main/ble/ble_peripheral.c). Tests cross-check the LE byte order so
    a swap on either side fails loudly.
    - BleAccess.kt: runtime perm check for BLUETOOTH_SCAN/CONNECT +
    POST_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
2026-05-20 feat: cluster ble peripheral — link-trap workaround + boot sequence fix
    Wire the BLE peripheral into the cluster build (commit 7723c98's parked
    source) and work around the binutils 2.45 / IDF P4-rev<3 link trap.
    Three pieces:
    - Route LVGL fast-mem to .text.lvgl_fast (flash via XIP) so the ~118 KB
    of fast-path code doesn't crowd spi_flash chip drivers out of IRAM
    under -Wl,--enable-non-contiguous-regions.
    - SPI_FLASH_OVERRIDE_CHIP_DRIVER_LIST=y + slim default_registered_chips[]
    keeps unused vendor drivers (winbond/mxic/issi/boya/th) out of the
    link entirely.
    - access_tx_cb stub fixes ble_gatts_count_cfg rc=3 (NimBLE's table
    validation rejects NULL access_cb even for notify-only c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
    [main.c]
2026-05-20 refactor: split into monorepo — firmware/ + companion/
    Repo restructured so the ESP-IDF firmware and Android companion sit as
    equal peers under a clear top level. Adds Makefile-based orchestration,
    swaps to MIT, and rewrites README/CLAUDE pointers.
    Layout:
    - firmware/ ESP-IDF cluster firmware (was at repo root)
    - companion/ Android BLE-central app (was companion-android/)
    - docs/ cross-system docs
    - firmware/docs/ firmware-internal docs
    - Makefile top-level orchestration (sources IDF, delegates
    to idf.py / gradlew). `make help` for targets.
    - .zed/tasks.json Zed tasks now call Mak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
    [partitions.csv, partitions_example.csv, stylesheet_calculator.xlsx]
2026-05-20 refactor: monorepo split — content edits missed in ed6e3df
    Follow-up to the previous commit, which captured the renames + new
    top-level files but not the in-place edits to files that had been
    renamed first. Stages those edits on top:
    - .github/workflows/firmware-build.yml + host-tests.yml — set
    working-directory: firmware (or firmware/test_apps/host) and update
    artifact paths and the lcov filter to firmware/main/...
    - .zed/tasks.json — rewrite tasks to call Makefile targets (DRY across
    Zed + CI + CLI).
    - LICENSE — replace inherited Apache 2.0 with the GitHub-default MIT
    template; copyright Aleksandr Štšepelin 2026. Vendor BSP components
    keep their own licenses inside the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
2026-05-21 docs: phase 2.5 grows stages 4-7, camera framework splits
    Phase 2.5 was originally four stages where Stage 4 (speed-camera
    framework) blocked on real GPS. Three new bench-doable stages got
    added, and Stage 4 split along the off-bike / on-bike seam so the
    phase becomes entirely independent of hardware shipping:
    - Stage 4 — host-side notif emulator. SDL2 sim grows a TCP listener
    that consumes the same TLV bytes the cluster's BLE RX path parses,
    plus a Python CLI (`tools/notify.py`) that encodes payloads.
    Collapses the "edit → flash → install APK → send real notif"
    test cycle to <5 seconds.
    - Stage 5 — BLE pairing + bonding. Replace the current just-works
    model with LE Secu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
2026-05-21 feat: phase 2.5 stage 6 — no-sim build flag
    CONFIG_VROD_INCLUDE_SIM_ENGINE (default y) gates whether the synthetic
    driving-cycle simulator gets compiled into the cluster firmware. Off
    removes sim_engine.c + sim_math.c from the source list and #ifdefs the
    sim_engine.h include + sim_engine_start() call out of main.c. gear_table
    stays unconditional — the gear indicator widget reads from it
    independently of the sim.
    Net flash impact: ~2.3 KB smaller when disabled (sim_engine + sim_math
    are mostly fixed-point math, not much code). The real point is intent
    — bench builds keep the gauge swing for visual sanity, real-bike
    builds (Phase 3 onward, J1850 driver as the producer) drop dead weight.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
    [main.c]
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2026-05-21 feat: phase 2.5 stage 5 — ble pairing + bonding
    Replace the just-works BLE link (any nearby central can read / write
    the cluster's characteristics) with LE Secure Connections + numeric-
    comparison pairing + persistent bonds in NVS.
    Cluster firmware:
    - sdkconfig: BT_NIMBLE_SM_SC=y, SM_LEGACY=n. ble_hs_cfg.sm_* set to
    DISPLAY_ONLY IO cap + bonding + mitm + sc, plus the ENC + ID key
    distribution masks. NVS persistence was already on.
    - RX characteristic now declares BLE_GATT_CHR_F_WRITE_AUTHEN — an
    unpaired central writing to RX gets insufficient-authentication
    back, which triggers Android's BluetoothGatt to auto-pair before
    retrying. TX notify is intentionally not gated: the com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
    [main.c]
2026-05-21 fix: switch to monochrome noto emoji — colr fonts blocked by lvgl bug
    Root cause: LVGL's lv_freetype_glyph.c freetype_glyph_create_cb calls
    FT_Load_Glyph with FT_LOAD_COMPUTE_METRICS + FT_LOAD_NO_AUTOHINT (no
    FT_LOAD_COLOR, no FT_LOAD_RENDER). For COLR fonts — where each
    codepoint's glyf entry is an empty placeholder and the real visual
    lives in the COLR paint tables — that returns metrics.width = 0 and
    metrics.height = 0. LVGL's metrics path then reads box_w/box_h from
    the (un-rendered) bitmap, also 0. The label's layout allocates a 0×0
    slot for the emoji and draws nothing, even though the separate
    freetype_image_create_cb path *can* produce a real 26×16 BGRA bitmap
    via FT_LOAD_COLO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
2026-05-23 feat: companion in-app device picker + LE SC numeric-comparison fix
    Tightening the BLE bring-up UX once it became clear that Samsung
    phones aggressively hide BLE peripherals from the system Bluetooth
    settings, so the OS-managed pair-new-device flow can't be used to
    adopt the cluster.
    Cluster (firmware/main/ble/ble_peripheral.c)
    * sm_io_cap: DISPLAY_ONLY -> DISPLAY_YESNO. Against an Android
    phone's KEYBOARD_DISPLAY IO cap under LE Secure Connections,
    DISPLAY_ONLY selects Passkey Entry — the cluster would have to
    display a random 6-digit number for the user to type into
    Android's pairing field. Our gap_event_cb only ever handled
    BLE_SM_IOACT_NUMCMP and rejected everyth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
2026-07-03 feat(companion): auto-reconnect after cluster power cycle
    On link loss the client arms connectGatt(autoConnect=true) to the last
    device — the controller accept list re-forms the link as soon as the
    cluster advertises, including Stage 8 directed advertising that a scan
    filter would never see. ReconnectPolicy keys on the GATT disconnect
    status so only genuine losses (supervision timeout, LMP timeout,
    failed-to-establish) re-arm; deliberate disconnects from either side's
    button stay disconnected. New WAITING conn state surfaces the armed
    wait in the UI and the foreground notification. Closes the last
    companion loose end from Phase 2.5; README status brought current.
2026-07-03 feat(gps): NMEA RMC parser + UART producer behind CONFIG_VROD_GPS_UART
    Phase 3 software half. nmea.c is pure logic (framer + checksummed RMC
    parse: any talker, ddmm.mmmm to 1e-7 deg via integer math, knots to
    km/h, no-fix sentences accepted as invalid) and sits in the coverage
    gate at 100% line/branch. gps_uart.c reads the NEO-6M/M8N on a
    Kconfig-selected UART/pins/baud and publishes into gps_source; when
    enabled it replaces gps_sim as the producer so the two never fight.
    Verified: host suite green, firmware builds with the flag off and on.
    [main.c]
2026-07-03 docs: correct plans/schematics, close Phase 2.5, kick off Phase 3
    Comprehensive audit fixes: the J1850 TX schematic was drawn inverted
    (bus permanently pulled to 12V, MOSFET shorting it low — VPW is
    active-high; redrawn as a switched high-side source with the zener
    setting the 7V dominant level); the 12V-signal dividers now account
    for 14.4V charging voltage (10k/4.7k put 4.6V on a 3.6V-max P4 pin —
    now 10k/2.7k); engine temp decodes as raw degrees C per HarleyDroid,
    not F; flash is 16MB not 32; LV_DEF_REFR_PERIOD is 33 not 15; AVRCP
    claims removed (C6 is BLE-only — that's why the companion exists);
    the master plan's Phase 2.5 BLE summary had Android/iOS swapped.
    Stale status brought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
2026-07-04 fix(j1850): RX resolution — remove RX_INVERT, configurable glitch window + sweep, dedicated ADC probe
    RX_INVERT never reflected bus polarity — it masked a bug. The P4 hardware
    glitch filter delays the filtered edge relative to the sniffer ISR's
    gpio_get_level() read, so the recorded pulse level is systematically wrong
    and frames never assemble. The on-bike sweep decoded ZERO frames at every
    nonzero window (400/800/1200/1600 ns alike) vs 546 frames / 0 bad CRC at
    0 ns — a hard cliff, not a gradient. RX_INVERT turned the dropped-edge
    glitches into passive pulses that happened to decode, hiding the cause.
    Bus is standard VPW (idle LOW, dominant HIGH): bare-bus DMM (~0.3 V idle)
    + invert-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
    [main.c, screen_bench.c]
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2026-07-05 docs: sync stale spots to the resolved design (speed cal, TX/RX, power, enclosure)
    Accuracy fixes so the repo reflects where the project actually landed. Doc-only.
    - Speed calibration (PROJECT-BRIEF changelog): primary reference is the STOCK
    SPEEDOMETER (native miles, ~5-10% optimistic, J1850-driven); phone GPS is only
    an optional later refinement.
    - TX/RX design decision (PROJECT-BRIEF): replace the stale "IRLZ44N TX + 2N2222 RX
    divider / SwapSmart" line with the resolved design — standard VPW (idle LOW /
    dominant HIGH), RX = passive 10k/4.7k + 7.5V zener, non-inverting (no 2N2222),
    TX = high-side PNP (2N2907A) driven by an IRLZ44N.
    - Discrete-line polarity added to the Phase 3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
    [enclosure.scad, section_preview.scad]
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2026-07-08 feat(odo): persist odometer/trips to NVS + trip reset + set-odometer
    Data layer for the upcoming Trip settings page. The bus counters only give
    deltas, so the running totals now live in a persistent, resettable store:
    - New pure odo_meter.c: odometer + dual-trip totals (per-trip distance AND
    fuel), with add / reset-trip / set-odometer. Host-tested, 100%.
    - j1850_driver owns the live odo_meter, accumulates the bus distance/fuel ticks
    into it, mirrors it into vehicle_data. New APIs: seed / snapshot / reset_trip
    / set_odometer, each republishing so the display updates at once. Driver host
    tests cover all four.
    - New odo_store.c (firmware-only NVS glue): restores totals into the driver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
    [main.c]
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2026-07-09 feat(telemetry): Brick 1 - cluster to phone telemetry stream + speed_raw
    Streams decoded vehicle_data from the cluster to the companion over the
    existing TX notify characteristic, filling the Ride dashboard with live data
    and carrying the raw ECM speed count the GPS calibration (Brick 2) needs.
    Firmware:
    - vehicle_data gains speed_raw (raw 16-bit ECM count), set in the SPEED parse
    branch alongside the divided mph.
    - telemetry_codec.c/.h: pure encoder for a 36-byte TLV frame (type 0x40 -
    speed_raw/mph/rpm, gear, temp, fuel, a lamp bitfield, odometer + dual trip
    distance/fuel, clock). Lamps pack branchlessly so the only branch is the
    size guard. Host-tested against an exact-byte fixtu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
    [main.c, telemetry_codec.h]
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2026-07-09 test(j1850): bench-only synthetic SPEED/RPM injector (default-off)
    CONFIG_VROD_J1850_BENCH_SPEED feeds a fixed SPEED frame (raw 19500) plus
    an RPM frame through j1850_driver_feed on a timer, so speed_raw / mph /
    rpm are non-zero with no live J1850 bus - desk validation of the companion
    telemetry stream and config write-back (divisor -> mph recompute -> NVS).
    A periodic read-back logs the live values so a phone-driven divisor change
    is visible on serial.
    Guarded, default n; the include of sdkconfig.h must precede the CONFIG_
    guard or it reads as 0 and the task silently compiles out. Never on a bike
    (it fabricates vehicle data).
    [main.c]
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2026-07-09 firmware(map): vector tile rasteriser + sim map screen
    On-device renderer for the compact ZMT0 tiles, proven in the desktop simulator:
    PBF -> compact binary -> C rasteriser -> LVGL -> screen.
    - map/map_tile.c: pure ZMT0 parser (+ host/sim dir loader, slippy projection).
    - map/map_style.h: on-device mirror of tools/maptiles/styles.py (RGB565).
    - map/map_render.c: pure software rasteriser into an RGB565 buffer - water fills
    under roads minor->major, per-tile culling, scanline polygon fill + thick
    Bresenham strokes.
    - display/screen_map.c: full-screen lv_canvas + speed-in-a-circle overlay
    (real JBM Bold, V-Rod orange).
    - simulator: VROD_MAP=<dir> renders the map screen (VROD_MAP_CENTER/_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
    [main.c]
2026-07-09 firmware(map): flashable on-device map demo + route animation
    Runs the vector map renderer on real hardware, confirmed on the P4.
    - map_demo (CONFIG_VROD_MAP_DEMO): boots straight into the moving-map screen,
    loads an embedded ZMTA tile archive, animates a baked Tallinn route
    (Padriku tee -> Liivalaia). Self-contained: no SD, no phone. Gated + off by
    default; reflash a normal build to restore the gauge.
    - map_tile: map_tileset_load_mem() parses a packed archive in place from
    flash-mapped memory (zero RAM copy); tools/maptiles/pack.py builds it.
    - screen_map: canvas in PSRAM (heap_caps) - 800x800 RGB565 too big for
    internal RAM.
    - map_render: scratch polygon buffers made static. On-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
    [main.c]
2026-07-09 firmware(map): compact flat-bottom layout + smoothness pass
    Design iteration toward the target view: map in the top 2/3 of the round panel
    (flat-bottom circle) over a compact instrument strip (tach bar hugging the
    chord, then SPEED / GEAR / ENGINE).
    Smoothness:
    - Double-buffer the map canvas. The heavy software rasterise now runs OFF the
    LVGL display lock (into a back buffer); only the buffer swap + strip update
    run under the lock, so the render task is never blocked on our CPU work.
    This was the main source of judder in the demo.
    - screen_map_render (heavy, off-lock) / screen_map_commit (light, under lock)
    split; callers updated (map_demo renders then locks only to commit).
    - Skip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
    [main.c]
2026-07-09 map: real GPS position + real instrument strip (drop the mock)
    Make the map a real feature instead of a demo: the position comes from the
    phone's GPS over BLE, and the strip reads the actual bus data.
    - New PHONE_EVT_LOCATION (0x08): i32 lat_e7, i32 lon_e7, u16 heading_cd
    (length-keyed - a heading-less sender still parses). Parsed in
    phone_protocol, stored in phone_data with freshness (phone_data_get_location),
    dispatched in ble_peripheral.
    - map_demo: when a fresh fix is present, centre on real lat/lon and fill the
    strip from vehicle_data (gear/rpm->tach/temp) - so GEAR shows the real gear,
    not N. Falls back to the baked route + synth when GPS is stale/absent.
    - Load th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
    [main.c]
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2026-07-10 map(compact): reference cluster layout + 2x wider roads
    Reworked the compact view to a clean custom cluster (per the reference mockup)
    instead of cramming the full-gauge widgets - which overlapped, since the fuel
    arc and turn-signal car-outline are sized for the whole round face.
    - Map region trimmed to 505 px (top); roads doubled in width (map_style).
    - Warning-lamp row under the map (reused warning_lights, ROW layout).
    - Readout row in the V-Rod style (JBM Bold, orange accent): TEMP | GEAR |
    SPEED (big, centre, km/h or mph via units) | RPM | FUEL%.
    - Horizontal RPM bar hugging the bezel with a red redline zone.
    - screen_map now driven by vehicle_data + settings (real units); map_demo an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
    [main.c]
2026-07-10 sim(map): live route animation in the window (interpolated glide)
    VROD_TRACK without VROD_TRACK_OUT now animates the route live in the SDL window
    - loads the track once and interpolates between points so the map glides
    smoothly - instead of the fixed-centre static view. With VROD_TRACK_OUT it still
    dumps frames for video.
    [main.c]
2026-07-10 map: heading-up rotation + 3x position marker (#52)
    screen_map_render() gains a heading arg: <0 keeps the map north-up (the cheap
    direct tile composite); >=0 composites the visible tiles into a larger square
    scratch, then does one rotated resample so the travel direction points up. The
    demo derives heading from the route tangent (phone course-over-ground when a
    real fix is present). Marker dot tripled (16->48 px). Sim animates heading-up by
    default along a track; VROD_MAP_NORTH=1 forces north-up for comparison.
    [main.c]
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2026-07-10 map: streaming SD tile loader (index in RAM, tiles read on demand)
    map_sd no longer loads the whole archive into PSRAM - a country-sized map
    (Estonia = 243k tiles / 28 MB) never fit in 32 MB. Instead:
    - map_tileset_open_file() reads only the ZMTA index into RAM (sorted at load for
    binary search; pack.py's string-sorted y order isn't usable) and keeps the
    file open. map_tileset_read_tile() seeks+parses one tile on demand.
    - screen_map's tile cache reads+parses each tile off SD on a miss (new
    map_render_tile_data(parsed-tile) split); hits stay pure blits.
    - map_sd_load() uses open_file; the whole-file PSRAM read is gone.
    - sim: VROD_MAP_STREAM=<file> exercises the on-device path. Verifi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
    [main.c]
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2026-07-10 sim: one demo source of truth across classic + map
    The map view fabricated its own fixed 45 mph vehicle_data (sim_map_vd), so
    toggling classic<->map showed different speed/rpm/gear and no signals. Feed the
    map the same sim_engine driving-cycle snapshot the gauge uses, and scale the
    route advance by that speed -- switching layout now only changes the
    representation; signals, tach, speed, gear, temp all match.
    [main.c]
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2026-07-11 map: onboard-GPS bring-up - source seam, 16B streaming index, shared SD mount, nav indicators, fixed-point rotate + PPA
    [partitions.csv]
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2026-07-24 feat(j1850): TX bench build modes - bike-replay + DTC read probe
    Bike-replay (VROD_J1850_TX_BIKE_REPLAY): live-bus IM keep-alive replay
    with a fault tally + in-loop reset/recovery, for Stage-4 on-bike TX
    characterization (no self-sniff compare on a live bus).
    DTC read probe (VROD_J1850_DTC_PROBE, Stage 5): dtc.c codec - HD J1850
    read/clear request framing + response-frame decode + J2012 text format,
    ported from HarleyDroid (request 6C <mod> F1 19 52 FF 00, response
    6C F1 <mod> 59 hi lo). dtc_probe.c keys the request to ECM/TSM/other and
    logs each decoded code; the sniffer gains a per-frame observer hook so no
    response is missed. Host-tested (test_dtc, inside the 100% line/branch
    gate). See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
    [main.c]
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2026-07-24 docs: add real UI screen renders (gauge, map, settings)
    Replace the ASCII display mockup with real screenshots captured headlessly
    from the desktop simulator (the same widget code that runs on the P4):
    - docs/screens/ gallery - gauge (moving + idle), map + compact cluster, and the
    settings family (menu, general, trip, set-odo, bluetooth). 480px, palette-
    quantized (~84 KB total). README.md documents each layout + the regen recipe.
    - firmware/simulator/main.c: add VROD_SCREEN=<name> to jump to a settings screen
    headlessly for VROD_SHOT capture (alongside VROD_SETTINGS / VROD_LAYOUT_MAP).
    - Embed the gauge render in reference/HARDWARE.md (was ASCII), PROJECT-BRIEF.md,
    and ROADMAP.md (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
    [main.c]
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2026-07-25 refactor(engine): route phone config/DTC through a command seam (ADR 0001 Phase B)
    Introduce contract/command.{h,c}: a minimal synchronous command-dispatch seam.
    The BLE bridge now emits typed commands (SET_CONFIG / DTC) instead of reaching
    into engine internals; command_handler.c (the registered handler) does the
    work. apply_config moves out of ble_peripheral.c into the handler.
    ble_peripheral.c no longer includes j1850_driver / ui_manager / dtc_service -
    connectivity stops knowing the engine exists. Behaviour unchanged (synchronous
    dispatch, same task). New command.c is host-tested; 100% line+branch gate held;
    firmware builds on the J1850+TX+DTC config.
    [main.c]
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2026-07-25 feat(engine): raw-sniff BLE forwarder — stream frames to the phone (adaptive layer step 4b)
    raw_sniff (CONFIG_VROD_J1850_RAW_SNIFF): registers a j1850_sniffer observer that
    copies + non-blocking-enqueues every decoded frame; a drain task encodes each via
    raw_sniff_encode and notifies the phone (0x50 TLV). A fixed queue decouples the
    frame rate from BLE so the decode task never stalls; frames drop on overflow
    (capture is best-effort). Gated capture build (uses the single sniffer observer,
    so it conflicts with the DTC service). Verified: compiles + links with the flag
    enabled; default build unaffected (gated source + prototype include).
    [main.c]
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2026-07-25 refactor(firmware): drop the on-P4 sim engine; desktop sim uses drive_model
    The cluster now always runs in prod mode (live J1850 bus, or the USB
    frame-injector) - no synthetic producer on the P4. Removes sim_engine +
    sim_math + the now-dead gear_table, and CONFIG_VROD_INCLUDE_SIM_ENGINE.
    The desktop SDL2 simulator gets sim_producer: a task that steps the
    shared deterministic drive_model and infers gear with the production
    gear_calc, so it exercises the real decode/inference path. drive_model
    stays host-tested but no longer compiles into the cluster firmware.
    [main.c]
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
